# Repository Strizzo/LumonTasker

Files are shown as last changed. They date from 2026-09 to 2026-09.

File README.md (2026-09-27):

# LumonTasker

A working desktop task terminal inspired by *Severance*: a Raspberry Pi 3 Model B,
touchscreen and thermal ticket printer in a custom two-bay enclosure.

The assembled prototype works. The terminal selects tasks from Trello locally,
prints tickets with a monochrome Lumon logo, and records completion or deferral. Its default UI is a simple
blue monospace screen with the Lumon globe, a focus countdown, elapsed-time
progress and a small animated number field. An alternate MDR-style layout is
available by tapping the logo. The separate message-printing integration on the
Pi/mothra remains in service; its deployment source has not yet been imported
into this repository.

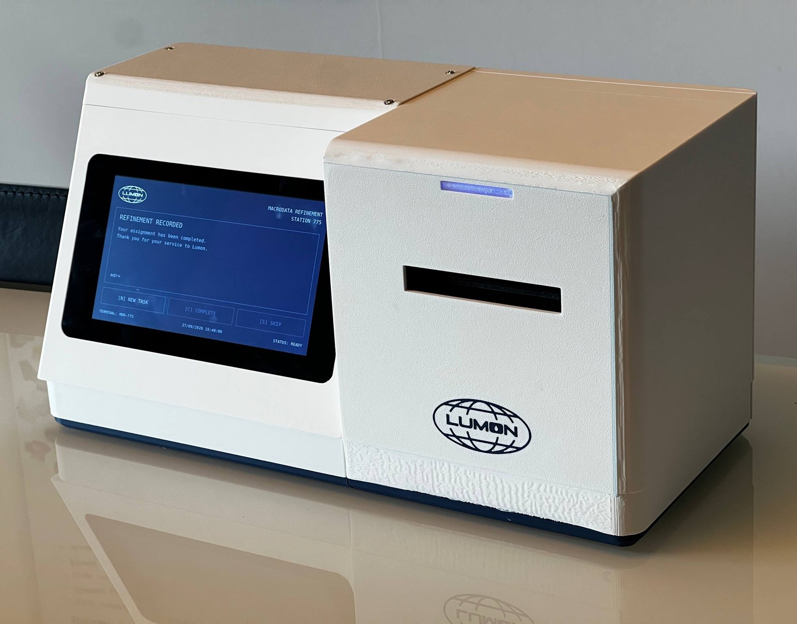
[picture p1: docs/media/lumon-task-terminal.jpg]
The assembled Lumon-inspired task terminal


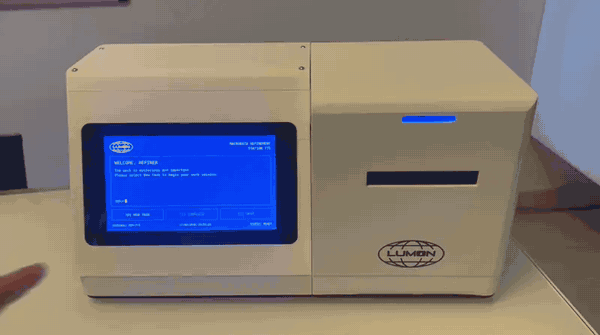
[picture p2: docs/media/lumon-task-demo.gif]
The terminal selecting and printing a task


The demonstration above is the same recording used in the build post, converted
to an animated GIF for GitHub. See also the [two software layouts](software/preview/themes-assignment.png).

## Project contents

| Path | Contents |
| --- | --- |
| [software/](software/README.md) | Pi application, both terminal layouts, assets, isolated checks and deployment records. |
| [cad/](cad/README.md) | Parametric Python CAD sources, hardware measurements, assembly reviews and engineering notes. |
| [cad/output/](cad/output/) | Versioned STEP assemblies, STL meshes, Bambu Studio projects and existing sliced print files. |
| [cad/CURRENT_PRINT_FILES.md](cad/CURRENT_PRINT_FILES.md) | Index of the parts used in the accepted physical build. |
| [files/](files/) | Earlier design sources and exports, preserved as a historical archive. |

## Software setup

Use a Python environment separate from the CAD environment. The dependency
versions in `software/taskticket/requirements.txt` match the working Pi setup.

```sh
cd software/taskticket
python3 -m venv venv
. venv/bin/activate
pip install -r requirements.txt
cp .env.example .env
cp config/settings.example.py config/settings.py
```

Fill in your Trello key, token and board ID in `.env`. The expected board lists
are `TODO`, `DOING`, `DONE` and optionally `Better than nothing`. AI is disabled
by default; ordinary task selection does not require an OpenRouter account.

```sh
python main.py
```

Open `http://localhost:5000/display`. The optional layout is
`http://localhost:5000/display?theme=mdr`. The application expects a configured
USB thermal printer on the Pi; use the isolated preview below to inspect the UI
without hardware or Trello access. Production kiosk startup is described in
[the software notes](software/README.md); historical deployment scripts contain
guards for specific past versions and are not a general installer.

From the project root, with the software environment activated:

```sh
python software/preview/check_backend.py
python software/preview/check_selection.py
python software/preview/check_routes.py
python software/preview/check_printer.py
python software/preview/check_ticket.py
python software/preview/server.py
```

The last command serves a fake-task UI at `http://127.0.0.1:8655/display` and
does not contact the Pi, Trello or a printer.

## Hardware and printing

The current complete assembly is
[LUMON_v51_GLUE_DC_INLET_ASSEMBLY.step](cad/output/v51_dc_inlet_panel/LUMON_v51_GLUE_DC_INLET_ASSEMBLY.step).
STEP files can be imported into Fusion; the editable geometry sources are the
Python generators under `cad/` and `cad/review/`. The working Fusion cloud
documents are not native `.f3d` files in this checkout.

The accepted build combines parts from several revisions. Start with
[the current print-file index](cad/CURRENT_PRINT_FILES.md), not the highest
version number of every historical part. `.3mf` files are Bambu Studio projects;
`.gcode.3mf` files contain already sliced jobs for the original P1S setup.
Check the model, plate, filament mapping and supports in your slicer before
reusing a job on another setup. Current colours are cotton-white PLA, navy-blue
PLA and a separate translucent PETG LED insert.

For CAD development:

```sh
python3 -m venv .venv
.venv/bin/pip install -r cad/requirements.txt
```

Follow the generator and revision notes in `cad/review/`. New revisions still
need the lighter walls, improved roof supports, larger display-glass seat,
closed printer-base underside and removal of the identified unused insert hole.
Those changes are recorded feedback, not changes already applied to the printed
prototype. See [build status](cad/BUILD_STATUS.md) for the full history.

## License

You may build and modify the enclosure for personal, noncommercial use.
Commercial printing or selling copies of the enclosure requires separate
permission. The hardware uses **Open Community License v1.1**, the application
uses **PolyForm Noncommercial 1.0.0**, and original documentation and media use
**CC BY-NC 4.0**. These restrictions mean this is a source-available project,
rather than an unrestricted open-source release.

See [LICENSE](LICENSE) for the scope and full terms, and
[THIRD_PARTY_NOTICES.md](THIRD_PARTY_NOTICES.md) for font licenses and the
*Severance* / Lumon references. This is an independent fan project with no
affiliation or endorsement.

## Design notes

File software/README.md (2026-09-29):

# Lumon terminal software

First deployed on 26 September 2026; MDR-inspired UI deployed on 27 September
local time. The original installation runs on a Raspberry Pi 3 Model B,
managed by `taskiosk.service`. Paths in the historical deployment records refer
to that installation; adapt them to your own Pi when setting up the application.

The physical display is 800 × 480. Its default interface is the simple blue
monospace layout the user preferred, available at
`http://raspberrypi.local:5000/display`. The newer MDR-inspired layout remains
optional at `http://raspberrypi.local:5000/display?theme=mdr`. Tap the Lumon logo
to switch between them. The screenshot from the Pi is
[preview/pi-themes.png](preview/pi-themes.png).

On the idle screen, **Manage** replaces the inactive Complete/Skip buttons.
It opens a 3 × 3 grid of Trello cards, with Previous/Next for additional pages.
DOING and TODO tasks appear directly; **Better Than Nothing** appears as one
group card showing its task count. Tap it to browse its own 3 × 3 grid.
**Back to Main** returns to the parent page, and the group itself never prints.
The logo/station header is hidden in both grids to give the cards more vertical
space and up to three lines for their titles. It returns on the welcome,
task-detail and active-task screens; the connection footer remains visible.
The main grid shows **Total focus** beside the page count: the number of open
DOING/TODO tasks across every page multiplied by the configured focus-session
duration (currently 15 minutes). Better Than Nothing tasks and the group card
are excluded. This is planned focus time, not a prediction of completion time;
the app does not currently store individual task-duration estimates. The total
is hidden inside the nested group, while loading, and on errors.
Tap a card to read its full title, then **Start & Print** to issue that specific
task. Back returns to the same grid page.
Both layouts support the picker; **M** opens it and Escape goes back.
Complete and Skip return when an assignment is active.

The picker includes all open DOING, TODO and Better Than Nothing cards in
Trello's list order, including recently skipped or issued cards. Manual selection
deliberately bypasses the automatic selector's cooldown and weighting, and never
uses AI. Merely browsing or inspecting a card does not print or update history.
The server rechecks open cards before printing, so a card completed or archived
elsewhere cannot silently issue an unrelated task. Tickets record
`selection_method=manual`; completion, assignment restoration and printing use the
existing workflow. [Picker preview with synthetic tasks](preview/manage-classic-grid.png).

Both layouts hide the mouse pointer, including over controls. The kiosk also
runs `unclutter-xfixes` with a one-second idle timeout to hide the native X11
pointer before Chromium receives its first mouse-motion event. Its process is
supervised by the existing kiosk launcher. The active-task screen omits the
fixed focus-session sentence, countdown and percentage bar, including when
restoring an older assignment. A small field of drifting numbers evokes
*Severance* without covering task text or controls. It renders at roughly seven
frames per second while an assignment is active and pauses in a hidden tab or
with reduced motion. The decorative numbers are not task data.

Switching layouts or reloading restores the latest open assignment and original
start time without selecting or printing another ticket. Newly issued tasks
store their display payload in the existing history; older active entries can
be recovered from Trello. Completed, skipped and more-than-12-hour-old entries
are not restored. Repeated-task completion now marks the newest issue, preventing
an old duplicate from causing the just-completed task to reappear.

The default uses one self-hosted DejaVu Sans Mono font. The optional layout is
informed by actual scene excerpts documented in
[references/README.md](references/README.md), using a self-hosted Liberation Sans
approximation; the production's exact typeface is not claimed. Real queue counts
remain available in the status endpoint and footer tooltip. Keyboard shortcuts
are N/C/S; Y/X still work too. The page uses `Cache-Control: no-store` and versioned
assets to avoid stale pages after an update.

## What changed

- The preferred blue terminal interface with the enclosure's Lumon globe,
  large touch buttons, decorative numbers and the newer layout available as an option.
- Real Trello connection status and queue data, refreshed every minute.
  API failures appear as unavailable rather than an empty queue.
- Task selection runs locally by default. It excludes tasks skipped within
  seven days, prefers the least-issued eligible tasks from the last 24 hours,
  then prioritizes DOING and urgent TODO deadlines. Remaining choices mix TODO
  and “Better than nothing,” with more BTN choices on evenings and weekends.
  Ties are randomized. If all eligible cards were issued recently, selection
  continues from the least repeated cards rather than returning false emptiness.
- A selected task gets a 15-minute focus session, not an invented estimate of
  its completion time. Completing a BTN task updates local history while
  leaving the reusable card on Trello; TODO/DOING completion still moves it
  to DONE.
- An optional OpenRouter helper uses Qwen3.7 Flash. Failure, timeout or an
  invalid card ID falls back to local selection, with a ten-minute cooldown
  before trying AI again. Ordinary use currently makes no OpenRouter calls.

## Printed task tickets

Task tickets now use a compact Lumon work-assignment form: globe, department
heading, issue reference, date, task, focus allowance and completion checkboxes.
One monospace family, two weights and thin rules keep it restrained. The
stationery is an original themed design. The old random euro-value line is gone.
See the [actual printer-width preview and layout notes](preview/tickets/README.md).

The entire slip is rendered as a monochrome bitmap, including accented text.
Typical artwork is about 95 mm long, plus the cutter margin; longer titles wrap
and extend the paper. Following physical feedback, the artwork's top padding
was reduced by about 2 mm and its bottom padding increased by about 12 mm to
balance the printer's leading blank space. The revised physical balance awaits
the next ticket; rendering and isolated printer-delivery checks pass.

## Optional settings

Defaults work without changes to the existing Pi configuration:

| Environment variable | Default | Purpose |
| --- | --- | --- |
| `TASKTICKET_USE_AI` | `0` | Set to `1` to try AI before local fallback. |
| `TASKTICKET_AI_MODEL` | `qwen/qwen3.7-flash` | Optional OpenRouter model. |
| `TASKTICKET_FOCUS_MINUTES` | `15` | Focus allowance for tickets and the grid total, bounded to 1–120. |
| `TASKTICKET_TIMEZONE` | `Europe/Luxembourg` | Selection schedule and UI clock. |
| `PRINTER_TASK_LOGO` | `1` | Include the Lumon globe on the work slip; set to `0` to omit it. |
| `PRINTER_WIDTH_DOTS` | `576` | Printable dot width for centring the logo on the POS80. |

Optional AI uses the existing `OPENROUTER_API_KEY` on the Pi. The prompt is
bounded to at most 12 eligible cards and 150 output tokens, without goals,
biography, descriptions or history. Thinking is disabled. An isolated live
test using one invented card succeeded; real Trello cards were not sent during
verification. Model availability and pricing were checked on
[OpenRouter's official model page](https://openrouter.ai/qwen/qwen3.7-flash).

The local source copy intentionally excludes `.env`, `config/settings.py` and
task history. Deployment preserved the Pi's credentials and history.

## Verification

The POS80 also prints graphics. On 27 September, one standalone “LUMON LOGO
TEST” receipt was sent using ESC/POS `GS v 0`; the user confirmed that the globe
was clear and complete. The initial release used a 320 × 164-dot globe above
native printer text. The full work-slip layout now replaces that format.
The test did not select a Trello card or change task history. The separate
message-printing service was not changed.

The current release passed 39 isolated checks on the Pi, including eleven
printer checks and six ticket-layout checks. They cover bitmap polarity, both
USB paths, native-text fallback, one final cut, failure handling, long and accented
titles, print margins and lossless raster-strip reconstruction. A failed write
does not create an issued-task history entry or automatically retry a partial
ticket. The deployed class also captured a synthetic job in a temporary file.

Read-only live checks authenticated to Trello, confirmed the board was open,
and found **11 TODO, 0 DOING and 19 BTN** cards. A dry run using the deployed
selector returned a real eligible task with `selection_method=local`, without
creating an AI client, modifying history or invoking the printer.

Twenty-one Python checks passed: three status checks, nine selection checks and
nine route/history checks. Browser checks passed at 800 × 480, including
55-pixel default touch targets and assignment text without overflow,
pointer hiding in both layouts, preserved sessions when switching, double-tap
protection, animation and reduced-motion behavior, failed-action retry,
completion state and offline status. These tests use
fake tasks and printer dependencies; they do not issue physical tickets. On the
Pi, a one-pixel pointer movement confirmed that Chromium's cursor resource is
fully transparent, and both kiosk and message-printer services remained active.
`scrot -p` manually composites cursor pixels, so it can show an old resource
even while native XFixes cursor hiding is active; the final screenshot was taken
with pointer capture enabled after verifying the transparent resource.

From the project root, with Python 3.9+ and `aiohttp` installed:

```sh
python3 software/preview/check_backend.py
python3 software/preview/check_selection.py
python3 software/preview/check_routes.py
python3 software/preview/check_printer.py
python3 software/preview/check_ticket.py
```

Manual-selection checks are included in `check_selection.py` and
`check_routes.py`. With the preview server and isolated Chrome running as below,
`node software/preview/check_manage.mjs` checks both layouts at 800 × 480:
nested grouping and pagination, parent-page restoration, full-title inspection, cursor hiding, safe text rendering,
double-tap protection, session restoration, empty/offline/stale-card handling,
hidden grid headers, cards at least 75 pixels tall, and returning to automatic selection. Results are in
`preview/manage-ui-check.json`; these checks use synthetic tasks and do not print.

`preview/server.py` provides an isolated UI preview at `127.0.0.1:8655`.
`preview/check_ui.mjs` exercises that preview through an isolated Chrome
debugging port at `127.0.0.1:9226`; it requires Node with built-in WebSocket
support. The current result is saved in `preview/compact-ui-check.json`, including
removal of the fixed focus display, restoration of older assignments, and
animation checks. `preview/themes-ui-check.json` records the earlier timer
release. `preview/mdr-ui-check.json` records
the earlier optional layout release. `preview/simple-ui-check.json` and
`preview/ui-check.json` record the previous designs' checks.

Both `taskiosk.service` and `thermal-printer-subscriber.service` were active
after deployment. The MQTT subscriber's PID stayed unchanged. The teleprint
container and broker on mothra were inspected without changes or test messages.
Physical ticket printing, card completion and Telegram delivery were not
triggered during the earlier UI/backend checks. The subsequent logo and
work-slip proofs are described above. Tap **New Task** on the terminal to
exercise the physical task workflow when wanted.

## Deployment and recovery

The ticket margin adjustment is recorded in `release/ticket-margins-deployment.json`.
Restore `printer/ticket.py` from its recorded backup and restart
`taskiosk.service` to undo it. Deployment captures a synthetic job in a temporary
file and does not issue a physical ticket or change task history.

The simplified task screen and larger task cards are recorded in
`release/compact-grid-deployment.json`. Restore its four `changed_files` from
the recorded backup and restart `taskiosk.service` to undo this UI update.

The grid's total-focus display is recorded in `release/task-total-deployment.json`.
Restore its five `changed_files` from the recorded backup and restart
`taskiosk.service` to undo that display and its duration metadata.

The nested Better Than Nothing group is recorded in
`release/grouped-tasks-deployment.json`. It updates only the shared script and
both templates. Restore its three `changed_files` from the recorded backup and
restart `taskiosk.service` to return to the previous flat picker.

The manual-picker release is recorded in `release/manage-deployment.json`.
To undo it, stop `taskiosk.service`, restore the six `changed_files` from the
recorded backup, then start the service. Credentials, task history and the
separate message-printer service are not part of this update.

The work-slip release is recorded in `release/work-slip-deployment.json`.
To restore the preceding logo-plus-text layout, stop `taskiosk.service`, restore
`printer/thermal_printer.py`, `printer/logo.py` and `core/task_manager.py` from
that backup, then start the kiosk. The unused renderer and bold font can remain.

The ticket-logo release is recorded in `release/ticket-logo-deployment.json`.
To undo it, stop `taskiosk.service`, restore its backed-up
`printer/thermal_printer.py` and `core/task_manager.py`, then start the service.
The unused logo module and PNG can remain. Setting `PRINTER_TASK_LOGO=0` and
restarting the kiosk disables the logo without rolling back the release.

Deployment records are saved in `release/ui-deployment.json` and
`release/selection-deployment.json`; the latest design update is recorded in
`release/themes-deployment.json` (previously `release/mdr-deployment.json`).
Backups on the Pi:

- Initial UI backup:
  `/home/srizzo/taskticket/backups/lumon-ui-20260926T214204Z`
- Selection release backup:
  `/home/srizzo/taskticket/backups/local-selection-20260926T215539Z`
- Simplified UI backup:
  `/home/srizzo/taskticket/backups/vintage-ui-20260926T221632Z`
- MDR-style UI backup:
  `/home/srizzo/taskticket/backups/mdr-ui-20260926T222627Z`
- Two-layout, pointer and animation update backup:
  `/home/srizzo/taskticket/backups/themes-ui-20260926T224648Z`

To undo the latest layout/timer update, restore the files listed in
`themes-deployment.json` from its backup, then restart `taskiosk.service`.
The new optional-layout files can remain unused; the restored template and
script will not reference them.

To undo the MDR visual update, restore its three backed-up files
(`templates/terminal.html`, `static/terminal.css`, `static/terminal.js`), then
restart `taskiosk.service`. The task selector and Trello backend are unchanged
by this visual release.

To undo only the visual simplification, restore its backed-up `main.py`,
`templates/terminal.html`, `static/terminal.css` and `static/terminal.js`, then
restart `taskiosk.service`. This keeps the working local task selector.

To undo the selection release, stop `taskiosk.service`, restore the files
listed in `selection-deployment.json` from its backup to the same relative
paths in the application, then start the service. That restores the initial
Lumon UI with the previous selector. To return fully to the original UI too,
also restore `main.py` from the initial UI backup before starting the service.
Do not restore history or credentials, and do not restart the separate MQTT
subscriber for a UI rollback. The native cursor startup change is backed up
separately; see `release/kiosk-cursor-deployment.json` for the launcher path
and backup. Restore that launcher and restart `taskiosk.service` to undo it.
The small `unclutter-xfixes` package can remain installed and unused.

The deployment scripts guard the specific inspected source hashes; they are
records of this release rather than scripts to rerun unchanged over later edits.

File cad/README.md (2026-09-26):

# Lumon enclosure: engineering review

**Current build:** the assembled prototype was accepted on 26 September 2026.
See [CURRENT_PRINT_FILES.md](CURRENT_PRINT_FILES.md) for the parts used and
[BUILD_STATUS.md](BUILD_STATUS.md) for the physical build record. The sections
below describe the original V19 review and are historical where later revisions
supersede them. Do not treat modelled parts as printed or assembled.

The real printer, screen assembly, Pi/cooler and cable paths determine the
mechanical design. The generated reference picture is a style reference only.
Neither the old picture nor the inherited component boxes establish fit.

## Working files

- `lumon_v19.py`: portable parametric working copy of the archived v18 generator.
- `export_review.py`: colored STEP, assembly-position STLs, individually oriented
  STLs, small fit coupons, previews and independent geometry checks.
- `review/logo_v18.step`: exact logo recovered from the supplied v18 STEP recess;
  six disconnected artwork regions, deliberately preserved.
- `review/audit_v18.py`: baseline STEP/mesh audit.
- `review/prepare_v19.py`: one-time migration recipe, not the normal build command.
- `output/v19/`: generated review artifacts. **Not a print release.**

Run from the project root:

```sh
.venv/bin/python cad/export_review.py
```

Python dependencies are recorded in `requirements.txt`. Original files in
`files/` remain unchanged. Fusion imports are review copies; edits made there
must be intentionally carried back to the generator before another rebuild.

## Color and assembly intent

| Group | Color | Print/assembly decision |
| --- | --- | --- |
| Left shell | Pale grey | Floor, walls, display ribs, insert lands, partition and Pi mounts form one structural print. Supports required at some internal features and the screen-opening roof. |
| Right shell | Pale grey | Floor, walls, spine and printer support rails form one print. Rails remain provisional until the printer is measured. |
| Left top cover | Pale grey | Separate for access to display fasteners, seam screws and electronics. Four screws. |
| Printer trim | Dark charcoal | Separate, open aperture around the provisional printer envelope. Two rear screws and locating skirt. The real printer supplies its lid, paper exit and controls. |
| Screen bezel | Dark charcoal | Separate flat print; perimeter fit clearance added. A thin adhesive attachment is still to be specified; no snap attachment is claimed. |
| Base plates, left/right | Dark charcoal | Separate prints, four screws each. Preserve independent color and screw access. Left plate has through vents and underside channels. |
| Display retainer | Pale grey/internal | Separate flat print; installs after the screen and clamps it at four points. |
| Rear service panels | Pale grey | Separate flat prints, four screws each with external pan heads. |
| Logo | Blue | Optional multi-material region registered to the right shell. Six loose regions are not a sensible first manual assembly. Paint/decal is the simpler single-extruder alternative. |
| Hardware reference bodies | Visualization only | Never print these as enclosure parts. Their shapes are unverified bounding boxes. |

Do not merge lids, retainer or service panels into the shells: doing so traps
hardware or prevents servicing. Keep the two main modules independently
printable and join them at the existing spine. There is no need to introduce
more large external seams until the actual build plate is known.

## Print orientation and remaining checks

`assembly_stl/` retains registration for fit and multi-material inspection.
`oriented_stl/` places each individual part on Z=0; these coordinates no longer
assemble together. Do not mix the two sets in a multi-material object.

- Shells: floor down, open top up. Inspect supports below the screen opening,
  rear-opening roofs and sideways bosses. The old blanket “no supports” claim
  is withdrawn. Supports must be removable before fitting electronics.
- Bezel and retainer: un-tilted and laid flat, rather than printed at their
  14-degree assembly rake.
- Rear panels: exterior face down; locating step faces up.
- Covers/trim: exterior top down to avoid supporting a whole internal ceiling;
  inspect the rounded perimeter for support and bed-contact requirements.
- Base plates: bottom down. Check channels, counterbores and first-layer grip.

The first fit-test plate is configured in `output/p1s_fit_plate/LUMON_v19_fit_test.3mf`
for a Bambu P1S, 0.4mm standard nozzle and textured PEI plate: 0.20mm layers,
3 walls, 20% infill, 3mm outer brim, and automatic build-plate support for the
screen corner. Studio estimates 1h24m and 27.07g including purging.
Physical AMS A1 supplies dark Bambu PLA Matte; A2 supplies light-grey Generic
PLA, as explicitly confirmed by the user. A2 was registered as Generic PLA
in the device settings. The full enclosure has not yet been sliced or released.

General support/split/tolerance rationale follows Prusa's manufacturer guide:
https://help.prusa3d.com/article/modeling-with-3d-printing-in-mind_164135
A mesh that is watertight can still have unprintable bridges or unusable holes.

## Hardware information needed for a fit release

- Printer exact model; body width/depth/height; rubber feet; lid hinge/swing;
  paper path/cutter; buttons and release lever; cable exits and plug clearances.
- Display exact model and complete assembly dimensions, including driver board,
  mounting frame, connectors and cable bend space. Confirm active image area
  before accepting the 6mm edge overlap inherited from v18.
- Raspberry Pi model, cooler and connector/cable directions.
- Actual power supply and voltage architecture. The inherited internal supply,
  inlet and barrier are packaging placeholders, not an electrical design approval.
- Printing setup confirmed: P1S with AMS, standard 0.4mm nozzle and two PLA colors.

The first physical step should be small fit coupons, followed by a printer-bay
fit test after measurement. A full pair of shells should wait for these checks.

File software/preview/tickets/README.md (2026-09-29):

# Lumon work slips

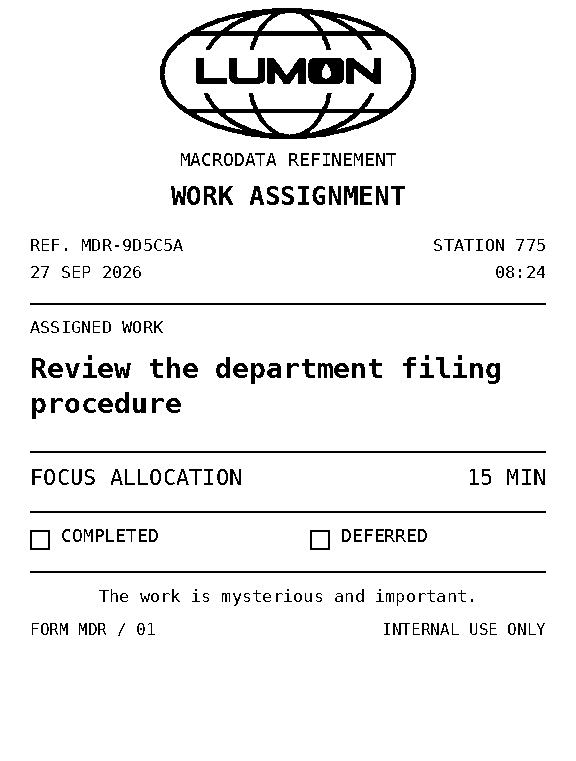
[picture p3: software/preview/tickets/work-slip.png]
Work assignment


Original *Severance*-inspired internal stationery, designed for the accepted
POS80 printer. This is not claimed to reproduce a screen-used paper prop.
The reference images contain synthetic tasks; no real Trello titles are stored.

The layout uses the existing Lumon globe, one DejaVu Sans Mono family in two
weights, thin rules and a clear assignment section. Station 775 matches the
terminal. A stable short reference is derived from the task ID; the issue date
and time use the configured timezone. The time field says **Focus allocation**
for the current selector and **Time estimate** for older estimated tickets.
Optional challenge times and older task-specific guidance remain available.
The paper checkboxes can be marked by hand; they do not change software state.
The random euro-value line and duplicate focus-session sentence are removed.

Rendering happens at the actual 576-dot printable width, with 30-dot side
margins. Normal task text is 28 dots high; supporting fields are 16–22 dots.
At 203 dpi, the illustrated two-line assignment uses roughly 95 mm of artwork
plus the printer's cutter margin. Long titles grow the slip rather than being
clipped or abbreviated. Accented text is rendered directly, avoiding the
printer firmware's inconsistent handling of UTF-8.

The revised artwork starts 8 dots (about 1 mm) below its top, reduced from 24.
Its bottom padding is 96 dots (about 12 mm) larger. This adds approximately
10 mm to each slip overall. The uneven bitmap margins compensate for the
leading blank paper visible on the physical printer; the PNG does not include
that mechanical margin. The current
[ESC/POS feed-and-cut command](https://download4.epson.biz/sec_pubs/pos/reference_en/escpos/gs_cv.html)
feeds to the cutter without reverse feeding. The next physical ticket should
confirm the balance; the POS80's exact head-to-cutter distance is not measured.

The same 1-bit pixels are used for the preview and USB job. They are sent as
contiguous 128-row raster strips with no intervening newlines, then one final
cut. Each strip is about 9 KB at 576 dots. This follows the beginning-of-line
and paper-feed behavior in the
[Epson ESC/POS raster reference](https://download4.epson.biz/sec_pubs/pos/reference_en/escpos/gs_lv_0.html)
and uses the command already confirmed on this POS80. The protocol is not
assumed to work on every other printer model. Missing assets fall back to a
readable native-text work slip before any USB write is attempted; failure after
writing starts never triggers a second fallback ticket.

To regenerate these previews without contacting hardware or Trello:

```sh
python software/preview/render_tickets.py
```

Also inspect [long-title.png](long-title.png) and
[accented-title.png](accented-title.png). The standalone physical sample has a
small **LAYOUT PROOF / NO TASK ISSUED** footer; normal task tickets omit it.

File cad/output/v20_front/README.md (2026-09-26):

> SUPERSEDED: user rejected the detachable front. Use ../v20_integral_front/ for the current mechanical study.

# Front-output v20 mechanical study

This is a new printer-module study, not the completed styled enclosure or a released print job. Do not print the old v19 printer housing: its hardware dimensions are obsolete.

Confirmed inputs:
- User measured desktop body: 131 W × 175 D × 120 H mm.
- User successfully tested feed/cut with the native output face forward.
- Rotated body envelope: 131 W × 120 D × 175 H mm.
- Seam, bezel and insert coupons passed; retain 4.2mm insert bores.

The prototype keeps the existing 158mm right-module width and spine screw positions. It has a 201mm overall design height, 20mm taller than v19, so the complete enclosure silhouette is not yet resolved. The STEP uses local right-module coordinates; translate X by 218.96mm to inspect against the v19 left module. The printer reference is a rectangular measured envelope, not a model of its native face, lid or connectors.

Six separate solids: grey shell, cradle tray, tray stop, top cover, rear cover; dark front surround. The shell floor and walls are united. Tray, stop and covers remain removable. The full native face is exposed by the surround so a guessed small paper slot does not constrain the lid. The rear cable opening is open to the panel bottom. The mounting bracket using the printer's two native keyholes is not yet modeled: its hole spacing and offset have been requested. Without that bracket, the printer is not positively retained and this design is not ready to use.

All six solids are valid and watertight; pairwise intersections and intersections with the measured printer box have no volume overlap above 0.05mm³. This checks nominal geometry only. It does not verify real case curvature, lid sweep, buttons, cable bending, retention or sliced supports. Single-part STL orientations are normalized to the bed. Separate colors onto separate plates. No new job has been sent to the P1S.

Assembly and exploded PNGs visualize the mechanical layout only. The blank grey rectangle in the assembly image represents the purchased printer envelope. Cosmetic radii, logo placement, shared silhouette with the display module, and printer mounting bracket remain to be resolved before releasing a full print.

Rebuild: `.venv/bin/python cad/front_output_v20.py`.

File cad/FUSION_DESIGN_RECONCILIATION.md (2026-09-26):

# Fusion design reconciliation — 21 September 2026

## Evidence and current state

Inspected the two open Fusion documents visually: LUMON_TERMINAL_v18 and LUMON_v19_colored_review (both unsaved review imports). Compared their source/export notes and the exported v19 STEP against the v28 printer bay currently printing. Neither open Fusion document is the current full device; do not use its printer cavity or old print parts as a release reference.

V19 explicitly assigns dark #10161E to printer_trim, display_bezel and both feet; the body and left cover are pale #DEE9EE and the logo blue #0B4F7E. This is deliberate styling, not merely Fusion component colouring. The dark printer part is an OPEN rim around the old top-exit printer, not a solid lid for the new orientation. build_lid specifies a12mm upper fillet and a hollow locating skirt. V28 has a closed, integrated pale top, a6mm front-right corner in plan, and no equivalent rounded upper transition. Earlier explanations that the separate right top was necessary for printability were wrong.

## What must be reconciled

| Area | Finding | Next action |
| --- | --- | --- |
| Printer crown | Dark rounded rim lost when old top-exit architecture was replaced. Old part is158mm wide; current bay175mm. | Design a NEW separately printed navy cosmetic cap for the existing flat top. Do not reuse old rim/cover. Keep rear removal and LED clear. |
| Upper rounding | Thin cap can soften its own edges but cannot recreate the original12mm fillet around a square shell without added height or overhang. | Show cap section/proportions before selecting radius; do not promise identical old silhouette. Prefer modest softening for this prototype. |
| Relative heights | Old full left module reaches181mm; right bay now reaches201mm before any cap. | Treat the20mm step deliberately in whole-device review. A cap increases it. Do not blindly raise display geometry or assume a flush common top. |
| Printer base | Old right foot is sized for158mm bay and has obsolete mounting points. V28 has no matching four foot-insert bosses and its shell starts atZ9. | Design matching dark right plinth and its retention for the printed shell; preserve rocker swept channel and cable opening. Align ground plane with left foot. Do not print old foot_right. |
| Base styling | Old light lower stepped band is absent from new right shell. | Decide with cap/plinth proportions whether to echo it cosmetically; a foot alone will not recreate the old inset light band. |
| Main joint | V28 retains five seam screw locations and two alignment-dowel locations from v19. | Join through left bay before electronics obstruct access; confirm fastener lengths and real tool access. Pairwise STEP audit checks cross-module collisions, not assembly access. |
| Printer support | V26 physically mostly fits; V27/V28 carry approved8.1mm bottom rise and0.6mm narrower total guide gap. | Print refined cradle as final assembly part, not another trial. It is separate from shell by design. |
| Printer retention/service | Whole printer rear-loads; two bars and rear cover are removed for paper service. | Print bars and rear cover. Verify real plug bends, switch clearance and extraction after installation. No top opening needed. |
| LED | Separate insert trial accepted; translucent PETG available. | Print PETG insert separately after profile/slot known; flange attachment without pressing native controls. Confirm visibility behind installed front. |
| Screen bezel/corner | V19 corrected prior lower-left corner geometry; bezel coupon passed previously. | Retain correction and separate dark bezel; specify adhesive only on locating lands, after actual screen fit. Do not restore v18 corner. |
| Display retention | Source assumes192.96x110.76mm original Pi7-inch display,21mm assembly depth TBD and6mm bezel overlap. | Confirm exact actual display, active-area boundaries, PCB thickness, connector and ribbon clearance before printing left tub/retainer. Source MEASURED comments are not new verification. |
| Pi/cooler | Inherited85x56mm PCB and58x49 mounting pattern;22mm assembled height TBD. | Confirm actual Pi and cooler, port direction and cable access; update mounts/envelope. |
| Power packaging | Old left tub hardcodes LRS-100-24-size supply, IEC inlet, divider and a speculative buck envelope. | Confirm actual chosen power hardware before carrying those pockets/cutouts into the next left module. No electrical implementation inferred from CAD placeholders. |
| Cooling | V19 left foot has through slots and rear-opening underside channels. | Keep intake path open; review exhaust and cooler clearance with actual hardware, then evaluate temperatures in assembled prototype. |
| Colours and print split | Current A2 light grey/A1 navy differ from exact historical render swatches. | Keep bezel/cap/plinth navy as separate jobs; pale structural parts separately; six shell colour changes only for logo. PETG insert separate. |
| Fastener schedule | Old31-insert count included obsolete right foot/top details. | Recount after plinth and left bay are final. Tested4.2mm insert bores remain; no two top-cover screws in V28. |

## Execution order

1. Allow current integrated-top shell print to continue. Review does not require cancellation.
2. Design and render the new rounded dark cap and matching right plinth around the ACTUAL v28 shell; these are not yet print-ready parts. Preserve LED and rear service clearances.
3. Prepare final refined cradle, retaining bars, rear cover and PETG diffuser. Verify Bambu settings natively: previous imports did not honor every programmatic setting. Slice each and request print launch as instructed.
4. Confirm display/Pi/cooler/power hardware (question sent to user), then finalize left bay, bezel, retainer, left cover, rear panel and feet together.
5. Recheck seam assembly, wiring, supports and whole-device appearance before releasing left structural print.

The current combined review is output/v28_integrated_top/whole_enclosure_review.step and PNG, generated from retained v19 left parts plus v28 right parts. It is a REVIEW with unverified left hardware, not a complete print release. Cross-module interference audit is context_audit.json. Existing Fusion tabs remain untouched as reference.

## Fusion synchronized — 21 September

Imported the coloured whole_enclosure_review.step into a new Fusion document and saved in the existing lumon project as LUMON_v28_CURRENT_ASSEMBLY_REVIEW. Verified current integrated-top right shell and dark left bezel/foot visible. Original v18/v19 tabs preserved. The new cap/right plinth are still unmodelled, not silently represented by obsolete parts. Left hardware remains unverified.

Standing workflow: refresh the complete coloured assembly in Fusion BEFORE asking for future print approval. Match reviewed right-shell geometry to the actual release revision, retain clear part names and label unverified/concept parts. Keep source generators and review STEP reproducible; save an explicitly versioned Fusion review and visually verify it. Do not use stale Fusion tabs to describe the currently printing design.

## V29 — rear service hatch / ventilation correction (2026-09-21)

The v19 electronics hatch overlapped the lower four rear exhaust slots.
V29 reduces its opening from 112 × 94 to 112 × 74 mm and the cover from
132 × 114 to 132 × 94 mm. Lower datum is retained; upper screw centres move
from z132 to z112. The rear wall and rebate change together, leaving 6 mm
between the cover top and the first exhaust slot. All five vents pass solid
intersection checks, the two changed meshes are watertight, and assembly
pair checks report no interference. This verifies geometry, not cooling performance.

Source: `cad/lumon_v29.py`; regenerate with `.venv/bin/python cad/review/build_v29_review.py`.
Only `tub_left` and `rear_panel_left` are replaced in the exact v28 combined STEP.
The actively printing v28 printer shell is unaffected. Left-side hardware
measurements and print release remain pending.

Complete coloured assembly: `cad/output/v29_rear_vent_fix/whole_enclosure_review.step`.
Saved and opened in Fusion, project `lumon`, as `LUMON_v29_REAR_VENT_REVIEW`.
Audit and rear view are in the same output directory. No new print dispatched.

## V30 — matching printer plinth added (2026-09-21)

Supersedes the printer-base omission above. `cad/review/build_v30_plinth.py`
adds a new navy bonded foot around the exact v28 printed shell, retaining
all v29 geometry. The foot is 9 mm high with 2.5 mm inset and 5 mm lower
bevel matching the left foot. Ground planes agree. Open cutouts preserve
the rocker, rear cables and inter-bay cable route. Five 0.3 mm recessed
adhesive beds retain the foot; unrecessed top lands carry compression.
This avoids new holes in the already printing shell. Physical fit and
bonding remain untested; do not present it as a screw-mounted base.

Valid single-solid watertight mesh, all adhesive beds backed by shell floor,
zero base/assembly intersections and clear relief volumes verified.
Files and assembly notes: `cad/output/v30_printer_plinth/`.
Opened and saved in Fusion project `lumon` as `LUMON_v30_MATCHING_BASE_REVIEW`.
Separate navy print only; not sliced or dispatched. Dark rounded top cap
remains outstanding. No other geometry was changed.

## V31 — prototype complete, cradle retention and next physical checks (2026-09-22)

The v28 shell is now printed (grey/yellow substitution), explicitly a test shell.
The user has only the earlier v26 cradle. V31 retains the exact v28 shell and
approved refined cradle, and adds two tray-capturing legs/lips to the lower rear
bar using its existing screws. Rear/upward nominal play is 0.5 mm. Geometry,
clearance and tray-motion checks pass; physical fit remains pending. The kit
has now been sliced and verified in Bambu Studio: 3 h 6 m 28 s, 108.54 g PLA,
212 layers, one colour. Use `02_cradle_and_bars_reviewed.3mf` and its matching
G-code export. Launch approval, clear bed and current PLA slot remain pending.
See `output/v31_cradle_retention/README.md` for the fitting sequence and prepared
single-colour kit. Imported into Fusion and saved in the existing `lumon`
project as `LUMON_v31_CRADLE_RETENTION_REVIEW`; the complete assembly was
visually checked. A 10-editable-document-limit notification appeared after
saving, but the named v31 document is present without an unsaved marker. No
older document was deleted or changed to read-only during this update.

The user wants the final enclosure less box-like. Keep rear service and a rigid
front/top, but revisit the final structural shoulder rounding and coordinated
navy crown/outlet surround/base using the full assembly. The grey/yellow shell
does not constrain the final styling. Do not start another large shell or final
colour print before hardware fit and actual-CAD appearance review.

## V32 — equal-height study (2026-09-22)

The user explicitly confirmed equal overall heights, tops aligned. This
supersedes the earlier relative-height direction: the left bay grows from
181 to 201 mm, matching the printer bay, with both bases on z=0. The display,
bezel, supports and retainer move up 10 mm to remain centred on the taller
face. Front lid fasteners follow the taller sloped wall and rear vents move
up 20 mm, leaving 26 mm above the service hatch. Bay joining holes retain
their coordinates. All printer-side parts are exact V31 solids, preserving
compatibility with the printed shell and prepared cradle kit.

Changed solids and meshes pass validity/watertightness checks. Complete
assembly intersection checks find no clashes; joining bores, lid fastener
passages and rear vents are unobstructed. Actual left-side hardware remains
unverified, so this is a proportions study, not a left-bay print release.
Coordinated crown rounding and navy trim are still outstanding and must
preserve the common finished height.

Source: `cad/review/build_v32_equal_height.py`. Complete STEP, audit, and
before/after actual-CAD previews: `cad/output/v32_equal_height/`.
The V32 STEP is imported and visible in Fusion as `whole_enclosure_review*`.
Cloud save is blocked by the personal-use 10-editable-document limit;
repeated CUA coordinate actions on the older V28 Editable control failed
with `windowNotFoundAtPosition`, including after resetting the tool session.
No older document was deleted or made read-only. Local STEP and previews are
saved. The design browser was restored. No print was dispatched.

V32 save blocker resolved: the user confirms on 22 September that they made
older Fusion versions read-only and saved the latest equal-height review.

## V33 — cohesive exterior study (2026-09-22)

User explicitly requested matching lower profiles and top-front rounding, with
one continuous shape split for printing rather than two visibly independent
bays. V33 uses a common upright outer envelope with a recessed 14-degree
display. The band has one height and setback across the face; both bays share
a 12 mm front roof radius. The left front brow is now integral, with the
removable lid joint on the roof behind it. The screen and printer datums,
cradle/bars, bay joining axes and service access remain unchanged.

This is a form option, not a final print release. Its four changed solids and
meshes pass checks, all assembly/hardware-envelope and rear-extraction checks
are clear, and vents/joining bores/lid bores are unobstructed. Actual left
hardware and slicer validation remain pending. An assembled seam remains;
do not promise an invisible joint without finishing.

Complete CAD and notes: `cad/output/v33_unified_body/`. Source generator:
`cad/review/build_v33_unified_body.py`. Imported, visually verified and saved
in Fusion project `lumon` as `LUMON_v33_UNIFIED_BODY_STUDY`, without an unsaved
marker. Older V32 saved by the user is preserved. No print dispatched.

## V34 — correction: preserve the sloped display surround (2026-09-22)

The user rejected V33's upright facade and deep screen recess. The original
sloped plane around the display is required. V34 restores the exact V32 face,
bezel and screen position, retaining the common base profile. The display
cover is rebuilt with no fillet along the joining edge: both roof surfaces
meet flat at z201. Exposed front edges have matching 12 mm radii tangent to
their respective faces. The existing front setback from the display rake
remains; no canopy fills it. Roof joint coverage and all assembly, reference,
extraction, vent and bore checks pass. Left hardware and slicing remain pending.

Saved and visually checked in Fusion `lumon` as
`LUMON_v34_SLOPED_CONNECTED_ROOF`. V33 remains only as a rejected alternative.
Files: `cad/output/v34_sloped_connected_roof/`. No print dispatched.

## V35 — desktop-terminal angle (2026-09-22)

User liked the desktop-terminal direction after discussing 20 vs 25 degrees.
V35 models 25 degrees for the entire sloped display face and screen assembly,
retaining the connected roofs and common base. The printer side is exact V34.
Front lid lands/screws move rearward with the panel. A small retainer relief
clears the existing power divider without cutting it. Five screw lands remain
fully supported; use only the rear alignment dowel because the old front pin
now lies ahead of the left wall. All assembly, reference-envelope, extraction,
vent and bore checks pass. Actual electronics remain unverified, with a tight
1.29 mm retainer-to-buck placeholder clearance. No print released/dispatched.

Saved and visually checked in Fusion `lumon` as
`LUMON_v35_DESKTOP_TERMINAL_25DEG`. V34 remains for 14-degree comparison.
Source: `cad/review/build_v35_desktop_terminal.py`.
Files and assembly notes: `cad/output/v35_desktop_terminal/`.

## V39 rear alignment —22 September2026

Full assembly saved in Fusion as LUMON_v39_ALIGNED_REAR at19:38 and verified.
Display-side rear wall/hatch/roof/base extend9.75mm to the printer cap datum.
Front throughY135,25-degree display,Pi/PSU and all printer-side parts unchanged.
Rear corners and base radii matched; CAD/mesh/clearance checks pass.
Seven Bambu bay plates prepared, no dispatch; see output/v39_aligned_rear.

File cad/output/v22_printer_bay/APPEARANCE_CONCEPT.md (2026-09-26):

# Finished appearance concept

Generated with built-in image_gen on 20 September 2026 from whole_enclosure_study.png. Output: finished_appearance_concept.png.

Suggested palette: Polymaker Panchroma Matte PLA, 1.75mm, Cotton White shell and Army Blue bezel/base/logo. This is a Lumon-inspired aesthetic choice, not an official colour match. Current manufacturer swatches approximately #F4EFEB and #2E4462; physical filament and lighting differ. Amazon Italy stock/prices not verified.

The generated render follows CAD proportions but is NOT an exact CAD rendering. LCD graphics, receipt text, printer buttons/status light and some edge/base details are illustrative. Actual printer front is retained, not replaced with this generated control panel. Right feet/base and final cosmetic integration remain to be modeled. Screen/UI design is not changed by this illustration.

User explicitly paused print dispatch; preparation may continue.

Prompt brief: Transform the actual CAD front-right preview into a photorealistic finished-product concept, preserve the sloped left screen module, 20mm taller right front-output printer bay, integral front, existing broad printer opening and logo placement. Matte warm Cotton White shell, Army Blue bezel/base/inlaid logo, fine printed texture, fitted LCD with retro teal task list, exposed black intact printer face with paper and controls, neutral studio desk and soft daylight. No top-output paper, front screws, keyboard or extra knobs. Hardware details illustrative; not an engineering drawing.

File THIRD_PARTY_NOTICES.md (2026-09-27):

# Third-party notices

The project-wide terms in [LICENSE](LICENSE) apply to the author's original
contributions. They do not replace the licenses or rights below.

| Material | License or rights notice |
| --- | --- |
| Courier Prime font files | SIL Open Font License 1.1; see [OFL.txt](software/taskticket/static/fonts/OFL.txt). |
| DejaVu Sans Mono font files | Bitstream Vera font license and DejaVu public-domain changes; see [DejaVu-LICENSE.txt](software/taskticket/static/fonts/DejaVu-LICENSE.txt). |
| Liberation Sans font files | SIL Open Font License 1.1; see [Liberation-LICENSE.txt](software/taskticket/static/fonts/Liberation-LICENSE.txt). |
| Python and CAD dependencies | Installed separately; retain their respective upstream licenses. See [software requirements](software/taskticket/requirements.txt) and [CAD requirements](cad/requirements.txt). |

*Severance*, Lumon and the Lumon globe logo are third-party references used in
this independent fan project. Their names, artwork and trademarks belong to
their respective rightsholders. The software and enclosure licenses do not
grant permission to exploit those third-party rights. No affiliation,
endorsement or official merchandise status is claimed.

The interface and task-slip layouts are original themed designs; they are not
claimed to be production artwork from the series. Scene-reference source links
are documented in [software/references/README.md](software/references/README.md).

The photographs and animated demonstration in `docs/media/` were provided by
the project author. The GIF is a format conversion of the author's original
recording. The media license covers the author's contributions, with the
third-party elements described above excluded.

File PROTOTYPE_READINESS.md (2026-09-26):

# First enclosure prototype — exploration, 20 September 2026

> Follow-up: the working v19 engineering review and revised geometry are in
> `cad/REVIEW_FINDINGS.md` and `cad/output/v19/`. The notes below describe the
> original archive before that review, not the current working candidate.

## Starting point

This workspace is an archive of parametric CAD, STEP assemblies, STL exports,
renders, and reference photographs. No application/firmware project or Git
repository was found at the workspace root. CAD generators use build123d/OCCT.

Use `files/mnt/user-data/outputs/lumon_terminal_v18/` as a **candidate baseline
for review**, alongside `files/lumon_v18.py` and `files/LUMON_TERMINAL_v18.step`.
It includes the raked display module, printer cover with paper slot, separate
feet, rear panels, and display bezel. Its report gives an assembled envelope
of 376.96 × 161 × 181 mm. This is not a print-approved release.

Do not combine the loose STLs in `files/` into an assembly: they include older
geometry. For example, the loose left tub is 227.46 × 160 × 151.97 mm while
the archived v18 left tub is 218.96 × 161 × 156 mm. The loose top plate is
3 mm tall; the v18 cover is 21 mm tall. Selected loose STL/report hashes do
not match their archived counterparts. Names such as v51/v52/v53 should not
alone establish chronological order; source headers and timestamps are unreliable.

## Measured STL bounds for the v18 candidate

Dimensions below were read directly from binary STL vertices, in the model's
millimetre convention. These are assembly-axis bounds, not chosen print orientations.

| Part | X × Y × Z (mm) |
| --- | --- |
| tub_left | 218.96 × 161.00 × 156.00 |
| tub_right | 158.00 × 161.00 × 156.00 |
| top_plate_left | 218.96 × 128.09 × 21.00 |
| printer_lid | 158.00 × 161.00 × 21.00 |
| display_retainer | 194.36 × 36.85 × 133.18 |
| display_bezel | 212.96 × 34.06 × 125.66 |
| rear_panel_left | 140.00 × 3.00 × 114.00 |
| rear_panel_right | 110.00 × 3.00 × 90.00 |
| foot_left | 216.46 × 156.00 × 9.00 |
| foot_right | 155.50 × 156.00 × 9.00 |

`ref_*.stl` represents purchased hardware, not enclosure parts to print.
STLs retain assembly offsets: e.g. tub bottoms are at Z=9 and the printer
cover starts at Z=160. Each part needs deliberate orientation and placement
on the slicer's bed. Bounding-box fit alone does not account for brims or supports.

## Issues to resolve before full-size case prints

1. The archived v18 validation report flags a **1.7 mm rear-left wall FAIL**.
   Reproduce and inspect this before releasing the left tub.
2. Printer dimensions remain explicitly UNVERIFIED: 142 × 122 × 122 mm.
   Confirm the actual unit, connectors, lid opening sweep, controls, and paper
   exit. `paper_slot_y=45` is still TBD. Display thickness is also TBD at 21 mm.
3. The report contains stale statements: it describes both modules as raked
   and also describes the printer block as upright; it calls the printer well
   open although a cover is exported. Its 21-insert schedule omits separate
   foot fastening and the source now includes lid magnets. Recalculate hardware
   from the chosen geometry rather than shopping from the old report.
4. Existing zero-interference results cover selected pairs only. They do not
   establish cover clearance, paper travel, lid servicing, or full assembly fit.
5. Regeneration needs environment repair: build123d is absent from the default
   Python; source uses `/home/claude/out_v18`, `/home/claude/logo_src.png`, and
   `/mnt/user-data/uploads`. The exact logo source is not present under that
   filename. Export code also retains a v2 STEP filename. Preserve the archive
   and make a portable working copy before regenerating.

## Next prototype sequence

1. Record printer model/build volume/nozzle/material and actual component measurements.
2. Confirm the v18 appearance as the desired baseline and repair/revalidate
   the working CAD, including the thin wall and complete mating-part checks.
3. Generate small fit fragments for the seam joint, display rebate, and printer
   support before committing to full tubs (also proposed in BUILD_PLAN_v2.md).
4. Slice and inspect those fragments using the actual printer profile.
5. After fit checks, print the right tub and trial-fit the receipt printer;
   then release the left tub, covers, bezel, retainers, and feet.

An appearance-only mockup can use provisional component dimensions, but should
be labelled accordingly. A functional fit prototype needs measured hardware.

## Verification performed

Read the existing build plans, v18 source and report, inspected the v18 render,
compared selected loose/archive hashes, and independently measured STL bounds.
No CAD regeneration, mesh-manifold validation, slicing, or physical fit test
has been performed. Original design files have not been modified.

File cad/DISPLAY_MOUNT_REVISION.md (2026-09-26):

# Display mounting revision — actual hardware photos, 23 September 2026

## V49 measured bracket-depth correction — 24 September

V48 completed (Device Finished100%,121/121 and user assembly photo), but the
arms bend while seating the display and the short screws do not reach. User
measures glass FRONT to flat metal mounting face **8.4 mm**, and screws **4 mm
under the head**; heads fit the existing counterbores.

- V49 relieves all four contact pads **2.44 mm**, local y6.96 to y9.40.
- Plastic grip under screw head is **2.0 mm**, reduced from3.9; head-seat y11.40.
  The actual4 mm screws protrude2 mm nominally. Do not substitute M3x6.
- Original XY hole positions, arm roots, pocket193.6x111.4/R8.2 and3 mm ledge
  preserved; contact depth changes only. CAD single-body, watertight, bearing,
  screw passage, unchanged-region and conservative insertion checks pass.
- Return to front-face-down orientation at user request. Two small identical
  upper-right corner coupons compare support gap0.20 vs0.12 mm and test depth/
  screw reach. Full-frame geometry also updated, but no full-frame reprint queued.
- New prints not dispatched; fresh plate-clear confirmation is still needed.
  CAD: output/v49_measured_display_depth. Fusion stays savedV39; not synced.
- Earlier2.5 mm maximum-thread-depth claim is not explicitly verified in the
  manufacturer drawing. Do not force a screw that stops before its head seats.
- Full display case still needs cable/power and full-body print/access review.

**Latest width change, 24 September: V45 uses a 3 mm bearing ledge.** The user
requested the wider seat and confirms the black band stays clear of the outer
3 mm rear glass border. The whole ledge remains 2.3 mm thick; 0.8 mm glass,
1 mm front recess, accepted outer opening, and four integral retention arms
remain unchanged. No band notch is needed. V44's 2 mm width below is history.
The nominal chassis is only 0.35 mm away from the wider seat at its lower edge;
the actual seating and metal mount stack still require the physical trial.
See output/v45_display_seat_3mm. Full-case release and Fusion sync remain pending.

**Latest correction, 24 September: the user's recessed seat is load-bearing.**
The glass must rest on its rear perimeter and be stopped from moving inward
without screws. Four screws through integral case arms into the metal lugs
prevent front withdrawal. V41/V43's deliberate gap under the glass was incorrect
for this request. V44 supersedes that load path; historical proposals below are
retained as history, not current instructions.

V44 provides a 2 mm bearing width and keeps the accepted glass opening and 1 mm
recess. The user now measures mostly 0.8 mm glass, and 1.3 mm at a local black
band (possibly a data connection, not identified). The measured baseline seat
is y1.8; historical 0.7 and 1.1 mm variants remain references. The user confirms
the band does not reach the outermost 2 mm rear bearing border, so no seat relief
is needed. The 2 mm dimension is the inward support width, not soft padding
thickness. Glass_0p8 is the selected seat. An interior envelope conservatively
checks band clearance without inventing its exact location or identity. This
does not release the full case for printing. The seat and four rear metal-lug lands must match
the freely seated assembly simultaneously. Check for printing tolerances/high
spots and correct any rear lug gap with measured rigid shims or revised pads;
never use the screws to pull the glass across that gap. No bedding layer is
assumed; any later bedding thickness must be included in the mounting stack.
The old V40 contour test does not validate this new bearing seat. See
output/v44_bearing_seat/README.md and per-variant audits. Fusion and printing
are unchanged by this revision.

The photos show a Pi already attached to the display controller standoffs, four unused outer mounting lugs on the metal back, a thin glass overhang, an orange flex and a DSI cable. Treat the display and Pi as one serviceable assembly. The loose wires were unplugged accidentally; the user confirms no physical pins/connector were reported broken. Their original pin mapping has not been verified, so do not infer connections from wire colours alone.

## Why the V39 display-side mount must change

The inherited CAD represents the display as a192.96×110.76×21 mm box. Its21 mm depth is explicitly a placeholder. The generic4 mm thick rear retainer sits21 mm behind the inner front panel, with long side ribs. Pi references and mounts are separate on the enclosure wall. Photo evidence makes those representations incomplete for this assembled hardware. Previous placeholder collision checks do not establish clearance for the attached Pi or plugs.

## Selected mounting direction

Keep the25-degree sloping face. The latest user requirement removes the separate navy surround and uses the glass border in an integral white recessed seat. Use the four OUTER threaded lugs in the display's metal chassis, on a lightweight removable carrier or local brackets. The official drawing labels these M3, nominal126.2×65.6 mm pitch. Do not confuse them with the inner M2.5 controller/Pi mounting pattern58×49 mm. Verify the hardware variant and fastener engagement before selecting screw length.

Locate the glass within a shallow opening with clearance. A soft anti-rattle gasket can be added, but mounting screws must seat against properly sized rigid spacers/bearing pads, never pull the glass tightly against a rigid lip. The original corner coupon is useful for contour/clearance comparison only and cannot validate the entire mounting stack.

The manufacturer enclosure whitepaper documents0.7 and1.1 mm glass variants with the same front-to-rear-mount datum, and warns that hard contact against the glass during tightening can detach or crack it. A lipless glass opening supported from the metal rear mount is the preferred starting point here; retain the option of soft pads after actual stack measurement. Do not glue only the glass corners. The guide also permits an appropriately designed perimeter tape mount as an alternative; we prefer screw-removable retention for this build.

Use the lighter enclosure design direction: broad skins around2.4 mm initially, with reinforcement local to the carrier mounts. Remove unused separate Pi mounts and bulky generic display ribs only when the new full assembly is represented. Check PSU/divider/buck clearances, airflow, ribbon bends, GPIO jumpers, USB/printer cable, power plug and SD access. No final electrical or thermal layout is implied by this mechanical proposal.

## Confirmed glass outline and provisional corner radius

User measured the glass as **193 × 111 mm** on 23 September, consistent with the nominal 192.96 × 110.76 mm reference. The official drawing shows rounded corners but does not dimension their radius. Scaling its vector outline gives tangent offsets of approximately 7.9 mm; use **R8 provisionally**, not as a manufacturer-certified dimension. Reproducible values are saved in references/display_glass_corner_inference.json. Provide perimeter clearance/corner relief and verify a small fit sample so a minor corner variation cannot load the glass. No additional manual radius measurement is required at this stage. These are reference data and mounting requirements; production CAD has not yet been revised.

## Depth confirmed and V40 fit test

The user confirms **40 mm** total depth with the Pi attached. The user also explicitly requests a precise visual fit. V40 targets a 193.4 × 111.4 mm opening: 0.2 mm clearance per side, provisional R8.2 opening around an R8 glass contour. The rear metal lugs carry the assembly. The glass sits 1 mm behind the navy frame's face; it is not squeezed against a rigid lip.

A small full-outline frame and four brackets have been generated and independently checked in output/v40_display_mount/fit_audit.json. This fit-kit release is separate from the full-enclosure audit: the provisional rear cable allowance overlaps the inherited divider by 188.72 mm³. Do not erase or waive that full-enclosure check. Resolve actual cable routing/power layout before printing the large left body. The nominal 126.2 × 65.65 mm outer M3 lug pattern and glass-to-lug plane must be physically checked using the kit. The earlier 65.6 mm pitch was a rounded reading; the drawing says65.65.

Fusion remains closed at the user's request after Mac performance problems. V40 is not yet synchronized there. The separate fit-kit STEP and mesh files are local and reviewable; keep V39 Fusion clearly distinguished.

Existing V39 display-side projects are review-only and are not released for printing under these new facts. Current printer shell remains accepted. The rear cover was verified finished at231/231 layers before the V40 fit kit was dispatched at21:39 local; both physical checks remain pending.

Sources: see display_hardware.json. The unchanged official drawing is saved at references/original_touch_display_mechanical.pdf.

## Physical contour accepted; integral recessed seat — 24 September

The user reports the V40 frame fits perfectly and shows it around the glass. Preserve the printed193.4×111.4 mm,R8.2 pocket contour. This confirms the practical opening, not the precise glass radius, rear bracket fit, or final retention stack. Rear-bracket clarification is pending.

The user explicitly clarified that there should be **no final navy bezel and no navy lip**. The existing black glass border is the visible surround. The intended geometry is an integral recessed seat in the white sloped panel, with a step behind the glass, not a separate piece overlapping its front. The assistant's earlier interpretation about restoring the original6 mm front overlap was incorrect and must not be implemented.

V41 retains the accepted outline and unchanged V40 bracket shapes, moving the glass and complete relative mounting stack rearward together to recess the glass below the white panel. Fill the old bezel rebate flush with the white face, remove the separate bezel component, and keep the glass free of rigid clamping pressure. Actual body/recess fit and cable/power clearances still require review before a large print.

## Four integral mounts — latest user direction,24 September

V43 merges the four arms into the case and closes the obsolete case-side screw/insert holes. Front-insert the unplugged display and attached Pi; four rear M3×6 screws fasten into the original metal lugs. The integral mounts remain during front removal. Exact nominal swept-envelope checks now include those fixed arms and pass; the earlier V41 check removed the detachable brackets. Existing V40 test pieces are still useful for measuring the same mounting pattern and bearing depth. The final assembly will not need them as loose parts.

Four bearing pads retain3.9 mm thickness and nominal2.1 mm screw engagement. The large case print may need local support beneath integral arms; slicing and real screwdriver/cable access remain to be checked. Unconfirmed actual power architecture and the237.48 mm³ cable/divider clash still hold full-case release. No new print dispatched; Fusion remainsV39.

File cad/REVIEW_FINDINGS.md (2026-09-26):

# v19 enclosure review

## Scope and status

This revision keeps the overall 376.96 × 161 × 181 mm envelope and repairs
mechanical details independent of the hardware measurements. It is a review
candidate, not a production or slicer-approved print release. The generated
reference image provides styling only. Actual hardware takes precedence.

The original archive is preserved. v19 is generated from `lumon_v19.py` and
exported by `export_review.py`; the imported Fusion document is a review copy.

## Findings and changes

| Finding in v18 | v19 change |
| --- | --- |
| Uneven transition beside the lower-left screen corner: rake cut through a previously rounded upright edge | Construct the sloping shell first, then round its actual front edge. Retain the deliberate base-band step. |
| Rear service rebate reached into the rounded rear-left corner; inset base reduced cavity-wall thickness | Move/narrow the left service panel and preserve 3mm walls around the inset base cavity. |
| Display bezel and pocket had identical perimeter size | Add 0.3mm clearance per side to the separate bezel. Adhesive attachment remains to be specified. |
| Forward alignment dowel at Y=15, Z=118 lay in front of the raked left wall | Move it to Y=35 and relocate the nearby upper screw to Y=50. Check hole and surrounding material on both mating walls. |
| Seam counterbore left only 0.8mm of the 3mm wall under the head | Use a full-thickness clearance hole with the screw head accessible inside the left bay. |
| Magnet pockets lacked reliable open seats/lands; some generated enclosed void shells | Replace the speculative magnetic retention with six screw locations: four left, two at the rear of the printer trim. Add connected insert lands and compression sleeves under the covers. |
| Foot inserts were deeper than the tub floor; some locations conflicted with internal packaging | Add raised insert bosses and relocate the eight mounting points into clear regions. |
| 2.2mm rear-panel counterbores cut through the 1.8mm outer skin | Keep the skin and use external screw heads. |
| Solid dark base plate blocked the floor intake slots | Add matching through slots and channels opening at the back of the base. |
| Chamfer along both sides of the base seam produced a V notch | Chamfer the outside perimeter while leaving the mating seam square. |
| Cover imposed an unmeasured paper slot and hid the real printer's top | Replace it with a separate dark, open trim. Its aperture remains provisional; real lid swing, controls and cable access still need checking. |
| Old STEP omitted the blue logo fill and had no useful color separation | Export named, colored bodies, including all six logo regions. Keep hardware references in a separate STEP. |

## Verification and limits

- Independent baseline audit: archived STEP solids were geometrically valid;
  that did not establish good fasteners, assembly access or print orientation.
- v19 checks each main part for one solid, CAD validity and watertight STL.
- All-pairs volume intersections include the case parts, logo, and inherited
  display/printer/Pi/PSU/inlet/buck boxes. See `output/v19/geometry_review.json`.
- Local material probes check insert bores, blind-hole floors, screw passages,
  compression sleeves, rear-panel head bearing and seam fastener surrounds.
- A radial sample of the rear-left corner at seven heights and seven angles,
  sampled every 0.05mm, measured about 1.25mm minimum in v18 and about 3mm in
  v19. This is a targeted check, not a complete minimum-thickness certification.
  See `output/v19/rear_corner_wall_check.json`.
- Three small coupons are extracted from actual geometry: left/right rear seam
  and the screen corner. Each is a valid single solid. They still need slicing
  with the actual printer profile.
- No lid-swing simulation, cable routing validation, physical fit test, thermal
  test or slicer toolpath review has been completed. Hardware boxes are not
  accurate representations of connectors, levers, feet or moving lids.

## Assembly and fastener plan

Keep ribs, lands and floor united with their corresponding shell. Keep covers,
rear panels, feet, screen retainer and dark bezel separate for access and color.
Use the two-module spine joint rather than adding another large visible seam
before knowing the print bed size.

Current geometry has 31 M3 insert locations: spine 5, retainer 4, rear panels 8,
base plates 8, covers 6. Pi pilot holes are separate and are not included in that
count. Two 4mm alignment dowels are provided. These counts are design inventory,
not a finalized shopping list: insert body size, screw engagement and head
geometry need confirmation with the chosen hardware and fit coupons.

Suggested order: test coupons; install accessible inserts in empty shells;
mount display/retainer and required wiring; join the spine while screw access
is clear; fit electronics and printer; attach separate base plates, rear panels,
bezel and covers. Recheck this order with the actual connectors and tools.
The rear lower spine screw is close to the power-supply region: join the modules
before fitting that supply. A removable electronics tray is a sensible later
revision if the confirmed hardware makes service access awkward.

## Remaining design decisions before full-shell printing

1. Confirm actual printer, display assembly, Pi/cooler, power architecture and
   connector dimensions. The printer trim may require a front relief for its
   lid release or controls; do not infer that relief from the generated image.
2. Confirm printer bed, nozzle, filament and multicolor capability.
3. Inspect support paths and removal in a slicer. The upright left shell has a
   roughly 181mm-wide screen opening; “vertical opening” does not make its roof
   self-supporting. If supports prove excessive, separate the front carrier
   with designed screw lands rather than simply cutting the shell in two.
4. Test inserts, dowel fit and bezel rebate. A successful mesh check cannot
   establish real extrusion tolerances.
5. Choose logo method: registered multicolor region, paint, or decal. The small
   disconnected blue islands are not recommended as loose hand-assembled prints.

Print orientations and the part/color table are in `README.md`.

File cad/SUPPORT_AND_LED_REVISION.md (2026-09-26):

# Support and indicator revision

## Hardware correction: tapered casing, downward rocker and LED

User photos, 21 September 2026, show original front/rear walls are not parallel. In the chosen orientation these become upper/lower faces. The prior 131 × 120 × 175mm reference remains only a maximum envelope; it cannot validate support contact, printer tilt or actual outlet alignment when installed. The width coupon passed, not the full cradle. Do not print the full v23 tray/shell as a validated mount.

Original rear power rocker becomes downward-facing. Provide a clearance pocket or through-opening in BOTH tray and any shell floor beneath it, including both switch positions, assembly tolerances and insertion/removal path. The table or eventual foot/base structure must not reach the rocker through that opening. Switch width/height, position and protrusion are pending; no precise hole is guessed from photographs. Define structural support pads on verified casing lands clear of switch and connectors; shim/pad heights may differ to keep the paper-output face aligned. Retainers must secure without wedging tapered casing or loading buttons/lid.

User does not require external feed/lid-release button access; those become available after removing the intact printer for paper service. Conceal with internal noncontact clearance, not a wall resting on controls. LED should remain visible. Preferred proposal: a small separate translucent/off-white insert, supported by a concealed shoulder in the shell, with a light-collection cavity accommodating the sloped native face. Do not claim a fixed matte-PLA wall thickness will transmit enough light; test an optical sample with the actual filament. No direct loading of the native LED lens. Exact LED position and angle pending.

Required measurements: rocker outline, protrusion in both positions and distances to two adjacent edges; original front-to-rear length at lid and bottom (taper); LED outline and centre relative to upper edge in chosen orientation. Photographs establish features but not precise dimensions. The fitted outlet centre remains 60mm from printer top, but its absolute CAD height depends on corrected support placement. No printing authorized for this redesign.

## Additional measurements — 21 September

Original top length 166mm becomes front vertical span; original bottom length175mm becomes rear vertical span. Difference9mm over approximately120mm new front/back depth. This constrains overall taper but does not establish how the9mm is divided between upper and lower faces. Do not assume a9mm wedge under the printer or move the fitted outlet until support pose is determined. Keep175mm as conservative height envelope.

Downward switch outline23×16mm; distance65mm from original top/new front edge and16mm from closest side edge. Edge-versus-centre datum, side in installed coordinates and protrusion remain unconfirmed. Store measurements without silently locating a precision hole. Prefer open relief beneath rocker with support lands outside its full travel; table/base and insertion path clearance still required. No print sent.

## Confirmed rocker clearance

User confirms offsets65mm from new front and16mm from nearest side are to NEAREST EDGES. Rocker protrudes4.5mm. With provisional23mm across-width and16mm front/back axis assignment, rocker spans65–81mm from front and16–39mm from nearest side. Proposed relief27×20mm gives2mm margin on each side:63–83mm from front,14–41mm from nearest side. Reserve at least6.5mm free depth normal to the casing (4.5mm rocker +2mm margin), in both switch positions. These are design allowances, not a validated installed cutout.

Any tray/floor/base structure must clear this volume. A closed pocket under the final position alone is insufficient if the downward rocker crosses solid supports while sliding in; use an open insertion channel or a removable support arrangement. Resolve actual taper/support pose and transverse-side mapping before committing support geometry. No print sent.

Active revision: v25_tapered_printer, source printer_bay_v25.py. User-authorized60/40 taper implemented with bearing rails, rear-open switch channel, fitted90×14 paper slot and separate hollow0.8mm LED insert. LED40×4.5 projected, upper edge2mm down (interpretation); switch mapped left in top plan with FRONT at top. See v25 README for assumptions and checks. Printing requires explicit user confirmation.

## Translucent PETG available — 21 September

User has translucent PETG. Preferred final LED diffuser is the existing separate insert printed in PETG and assembled into the PLA shell. Do not combine the materials as a bonded multi-material print. Existing light-grey PLA trial is still useful for geometry/fit. PETG brand/profile and loaded slot are not specified; do not send PETG using the current A2 PLA profile. Keep the recessed flange and noncontact cavity; verify optical transmission before final installation.

## V26: lateral taper correction

User confirms final front/outlet width132mm and rear/cable-face width143mm; switch remains underneath. V25 constant-width cradle invalid. Revised source cad/printer_bay_v26.py and output/v26_double_taper_printer accommodate both tapers, with provisional symmetric lateral split. Cradle guide gaps134/145mm; bay width175mm. Geometry audits pass for estimated envelope. Replacement cradle project prepared but not sliced/sent. Full shell remains pending physical fit and full-device integration.

## V27 physical-fit acceptance and refinement

V26 mostly fits; user waives repeat cradle trial. Increase bottom support rise5.4 to8.1mm, reduce total lateral gap0.6mm. Aperture/LED front datum rises2.7mm while retaining166mm front span. Updated CAD audits pass; final cradle included with assembly parts. Shell native supported project sliced8h49m/335.77g/six filament changes,not sent. Remaining parts prepared but not sliced. See output/v27_refined_printer/README.md; native Bambu settings must be verified because imported packer settings were not fully honored.

## V28 integrated top — user-requested cancellation

V27 shell cancelled at layer1/805. V28 merges4mm top into shell, removes both top fasteners and insert bores, retains201mm external height and rear extraction. Front-down orientation prints top as upright wall; separate cover was not required for printability. Geometry audits pass; no replacement dispatched. Bed must be cleared after cooling. See output/v28_integrated_top.

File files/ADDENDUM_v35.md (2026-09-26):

# LUMON_TERMINAL — v3.5 addendum

Adds the 10° display rake and the internal-PSU power bay. Generated by
`lumon_v35.py`. Envelope unchanged: **359 × 153 × 144 mm**.

---

## 1. Where the aesthetic details land

The split is not "nice things last", it is whether the detail moves a
mounting face.

**Form-defining — done now, in v3.5.** Rake, and by extension the front
plane's position at every height. Everything that mounts to that plane —
window lip, locating ribs, retainer bosses, retainer frame — is generated in
a local upright frame and then raked as a unit, so they stay coplanar by
construction rather than by hand-fitting.

**Surface — M4.** Fillets and chamfers on the top and front edges, shadow gap
at the seam, bezel chamfer, vent slot styling, ID plate, status LED, feet.
These only cut material from surfaces that are already fixed.

Corner radii sit awkwardly across the two: the external radius is currently
6 mm and is a surface detail, but going much above ~8 mm starts eating the
space the corner bosses occupy. Treat 8 mm as the ceiling unless the bosses
move first.

---

## 2. What the rake cost

- Front face leans back **25 mm** over the 144 mm height.
- The display's vertical extent shrinks to 110.76 × cos 10° = **109.1 mm**.
  That is inherent to tilting, not a modelling artefact.
- The display's rear face sweeps backwards as it rises: **y ≈ 29 mm at
  z = 28**, **y ≈ 49 mm at the top**. Three things had to move out of that
  swept volume: the mains barrier (now starts at y = 40), the PSU's front
  corner blocks (shortened to 6 mm), and the front pair of top-plate bosses
  (now at y = 58, behind the display's top rear edge). The top plate's front
  edge is located by the rebate ledge instead of by screws.
- Side stiffening flanges are clipped to start behind the display assembly.

### The seam step

The printer module cannot be raked. Its lid opens straight up and its front
sits 3 mm behind the front face, so raking that module would drive the wall
into the printer. The result is a **25 mm step at the top of the seam**: the
display console leans back, the printer block stands vertical.

This is defensible — it reads as a raked console beside a forward equipment
block, which is what the render implies anyway. But it is a real decision, not
a side effect. At M4 it gets resolved deliberately: either a chamfer running
the step into the seam, or a shadow gap that declares it. If you would rather
they align, the alternative is moving the printer back ~25 mm, which pushes
the depth to about 178 mm.

---

## 3. Power architecture

One 24 V open-frame supply, one mains entry, one buck for the Pi.

```
 IEC C14 (fused + switched) ─ fixed rear wall
        │
        └─ 24 V PSU ─┬─ 24 V ──► printer  (through the spine pass-through)
                     └─ buck ── 5 V ─────► Pi ──► display (GPIO / USB)
```

- **PSU pocket 129 × 97 × 30** at x = 66, y = 40. Sized for Mean Well
  LRS-100-24 (4.5 A, 108 W); the LRS-75-24 (99 × 97 × 30, 3.2 A) drops into
  the same pocket with longer corner blocks. Captured by printed corner
  blocks, not screwed — its own M4 holes stay unused and unmeasured.
- Pulled 13 mm forward of the rear wall so the rear-panel insert bosses clear
  it. They collided in the first pass.
- **Mains inlet in the fixed strip of the rear wall**, not in the removable
  service panel, so mains wiring never crosses a joint you open for service.
  Cutout 47.2 × 28.3 for a fused + switched snap-in C14; the outer face is
  thinned locally to 1.5 mm, because snap-in clips will not grip 3 mm.
- **Mains barrier** at x = 59, 46 mm tall, separating the PSU zone from the
  Pi and buck.
- **Pi mounted vertically** on the left wall on four 58 × 49 standoffs, ports
  facing rear. Flat on the floor it would not fit beside a 129 mm PSU.
- **Ventilation:** intake slots in the floor under the PSU, exhaust high in
  the rear wall. Nothing on any visible surface.

### Sizing caveat

108 W assumes a 24 V printer. **Read the voltage and current off the label of
the printer's own brick at M0** — that is the sizing input and it is currently
a guess. If the printer turns out to be 12 V, the whole rail changes.

Mains inside a printed enclosure: PETG or ASA, not PLA. Terminal block
covered, inlet earthed to the PSU chassis terminal, mains conductors strain
relieved and kept on their own side of the barrier.

---

## 4. Assembly order change

The spine screw at (y 140, z 45) sits above the PSU and must be driven
**before** the PSU goes in. Splitting the modules later means removing the PSU
first.

---

## 5. Open

Printer W/D/H, lid swing, LED and button positions, port positions, display
assembly thickness, Pi model, buck module dimensions, printer supply voltage.

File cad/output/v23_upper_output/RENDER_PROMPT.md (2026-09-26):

# Upper-output appearance concept

Built-in image_gen; reference: whole_enclosure_study.png. Appearance concept only: exact printer controls, screen graphics and base details remain illustrative. No print authorization.

Use case: product-mockup, CAD-to-photoreal concept. Use the attached CAD as strict reference for the geometry, proportions, view, opening locations and logo. Render a completed Lumon-inspired desktop device on a neutral desk in soft studio light. Matte warm off-white shell (Cotton White approximately #F4EFEB), matte muted navy bezel/base/logo (Army Blue approximately #2E4462), subtle fine 3D printed surface. Left module has a sloping landscape LCD in the existing bezel, screen filled with a minimal teal-on-dark task list. Right taller module MUST have the black rectangular printer face in the UPPER HALF exactly where the CAD has a grey rectangle. Upper edge of aperture close to top, lower edge around mid-height. The integral white LOWER HALF has the navy LUMON globe logo, preserve exact CAD logo placement. Inside that UPPER black aperture show exposed native receipt printer face: a small horizontal blue status bar with triangular buttons beside it near the TOP of the black face, a horizontal paper exit BELOW these controls but still in the upper half of the enclosure, short white 80mm receipt emerging forward/down. This is the native printer face, not an added removable enclosure panel. Keep receipt short enough to show logo below. Do NOT move outlet to lower half; do NOT place logo above printer opening. No visible front screws or seam outlining the white lower panel; front shell is integral. Keep original CAD two-module proportions, right module 20mm taller, the existing vertical module joint, right top flat and off-white, no keyboard or top paper outlet. Slightly round edges only as CAD. Screen content and exact printer face details illustrative. One hero image, no annotations or extra views, no dimension arrows.

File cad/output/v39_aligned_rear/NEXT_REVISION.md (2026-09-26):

# Next shell revision — physical feedback, 23 September 2026

## Exposed unused insert hole — 26 September feedback

Remove the unused screw-insert bore exposed on the printer-bay edge beside
the display glass in the user's photo:
`/tmp/codex-remote-attachments/01a0bf3e-2220-7252-adef-d07f9ff37b1f/491BE101-4384-473F-91DF-DCE7AA8ACD06/1-Foto-1.jpg`.
The next revision should have a continuous finished surface there. Identify
the exact source feature against this photo before modifying CAD; remove any
corresponding unused mating bore, while preserving the other functioning
inter-bay joints and display mounts. This is future-revision feedback, not
a request to reprint or alter the currently printing inlet panel.

User accepts the current V39 shell and confirms the existing V31 cradle and printer fit perfectly inside it. Do not reprint this shell now. User authorizes the next piece (the compatible V39 rear cover) and confirms the build plate is clear.

The lower light-coloured band is recessed 0.8 mm on the exterior, Z9–33 mm. This is deliberate styling geometry inherited from V33 and retained through V39, not evidence of filament shrinkage. With the shell printed front-face down, the recessed front strip needs support; user photographs show the navy support interface still present in the first photo and the stepped side outline in the second.

For the next shell revision, make this light-coloured lower band flush with the main exterior on front and sides. Preserve the tested inner floor, cradle datums, switch/cable relief, insert positions and retention interfaces. Coordinate the matching rear-cover lower band and display-bay exterior so the assembly remains cohesive. Keep the separate navy foot as a separate design decision; do not silently remove its base functions. Review the revised print orientation and support preview to eliminate this unnecessary exterior support strip.

Source anchors: build_v33_unified_body.py BAND_INSET=.8; V38 rear cap repeats the .8 mm lower band; V39 retains the printer-side geometry. No geometry or current prepared slice has been changed by this note.

## Weight reduction — additional user feedback

User reports that the shell feels too heavy and asks for a better balance of robustness and filament use. Treat this as a design requirement for the next shell revision and a reason to review the remaining unprinted parts before release. The already printed shell is accepted; do not scrap it. The rear cover is already printing and was not stopped or modified.

Evidence from the actual V39 shell G-code (see weight_audit.json): 4 wall loops, 5 top / 5 bottom layers, 15% gyroid. Slicer model mass approximately 593.16 g; total with support/purge/tower 634.49 g. Summed XY deposition by feature gives 415.39 g of inner+outer wall paths, 72.52 g sparse infill, 54.42 g internal solid infill, 39.54 g support/interface. These are toolpath estimates, not a physical weighing. The feature sums match the slicer total after excluding stationary purge. Existing CAD includes 3 mm front/outer wall, 4 mm roof/floor, a continuous 9 mm inter-bay wall, and thick rear mounting rails.

Reducing sparse infill from15% to10% would, under a simple proportional estimate, save only about24 g on this shell (approximately4% of model mass); actual reslicing is required. Geometry and perimeter allocation offer the larger opportunity. The unprinted display body has only23.26 g of sparse infill in612.70 g total, making infill-only changes particularly ineffective there.

Candidate design, requiring slicing and physical stiffness/retention checks before release:
- Broad non-load-bearing skins: start at2.4 mm; preserve overall outside dimensions and tested internal bearing/locating datums. Expand selected cavities to thin panels without moving the printer, cradle or screw axes. Use short local ribs where large panels flex.
- Inter-bay wall and full-height rear rails: replace excess bulk with a thinner web plus local mounting bosses/gussets. Preserve the complete insert engagement depth and surrounding material at each screw. Do not merely change the9 mm wall globally, since it locates and joins the bays.
- Printer-bearing floor: preserve cradle seats and load paths; consider pockets between them rather than blanket thinning.
- Initial slicer candidate:3 wall loops,4 top/bottom layers,8–10% gyroid in remaining thick regions. Keep local reinforcement around inserts, inter-bay joints and retaining contacts. Thin skins may remain effectively solid; fewer loops alone is not a guaranteed mass saving.
- Unprinted navy feet: investigate a ribbed underside retaining the existing outer appearance, bearing/bonding pads, cable/switch openings and rear-cover clearance. Review the unprinted display body/roof before using current heavyweight slices.
- Coordinate with the flush lower-band correction. Keep the current V39 cover compatible with the accepted shell; future matching pieces must be versioned separately.

Before any revised print: compare model/support mass and time against V39 in Bambu; inspect unsupported roofs, panel skins and reinforced fasteners. Validate with a representative panel/corner sample using the actual filament and orientation if needed. Do not claim a final percentage saving or validated strength until those checks are complete. No revised lightweight CAD or G-code has yet been released.

## Closed navy underside — 24 September feedback

The V42 lean slice of the original V39 navy base is printed and the user confirms it fits; they will glue it later. Keep this accepted part. For the next base revision, the user prefers a closed flat underside instead of openings copying the shell-floor reliefs. This supersedes the open/ribbed underside suggestion above.

V30 and V38 conservatively extended rocker and cable service volumes through the complete base to ground level. A matching through-cut below every shell-floor aperture is not intrinsically required. Develop a thin continuous bottom skin below internal clearance recesses, with necessary rear/side exits, rather than filling the base solid. Verify rocker clearance in both positions, plugs/cable bends and rear insertion/removal against actual hardware; the old ground-reaching keepout boxes do not establish the minimum physical clearance. Preserve the accepted outer fit and adhesive lands and review weight/time after slicing. No closed-floor geometry or print is released yet.

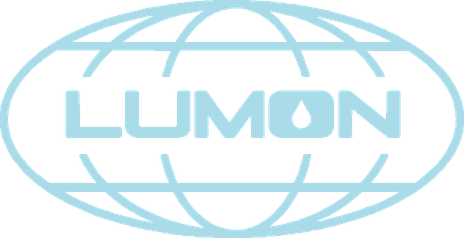
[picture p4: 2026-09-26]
software/assets/lumon-cyan.png

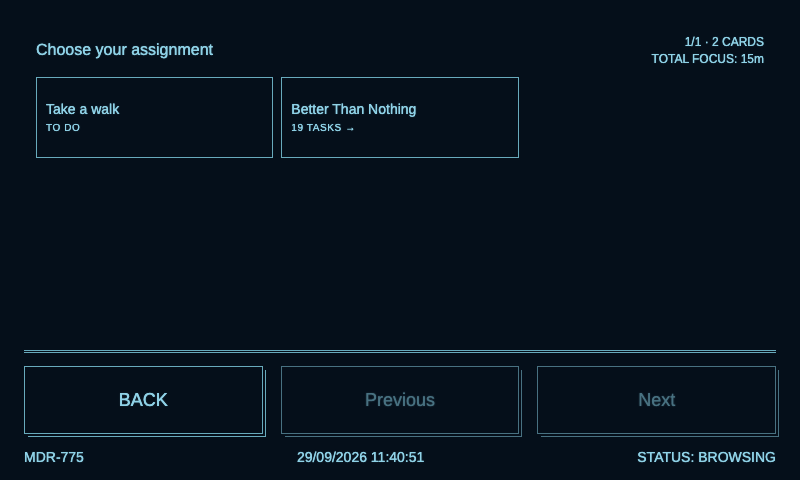
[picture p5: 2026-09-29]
software/preview/manage-mdr-grouped-main.png

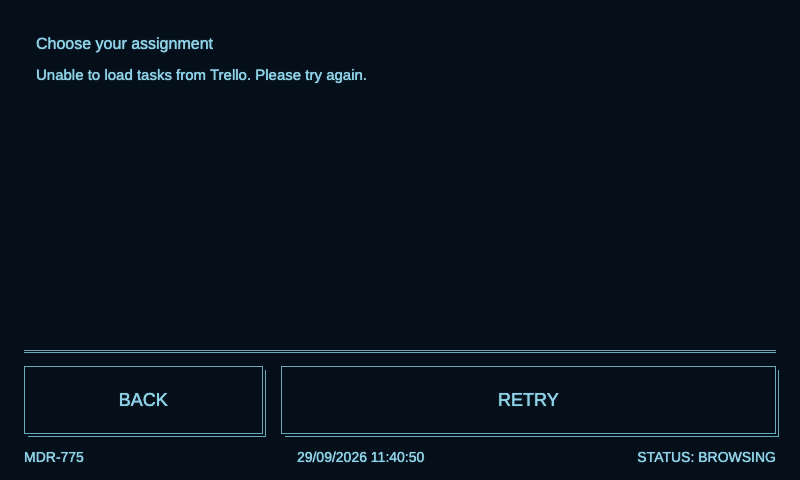
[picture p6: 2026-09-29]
software/preview/manage-mdr-offline.png

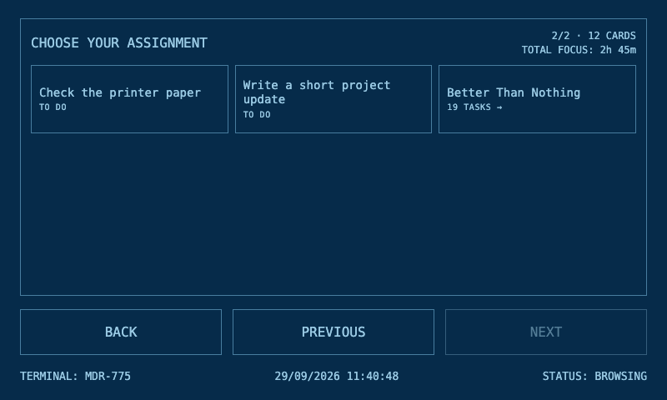
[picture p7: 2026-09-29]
software/preview/manage-classic-page2.png

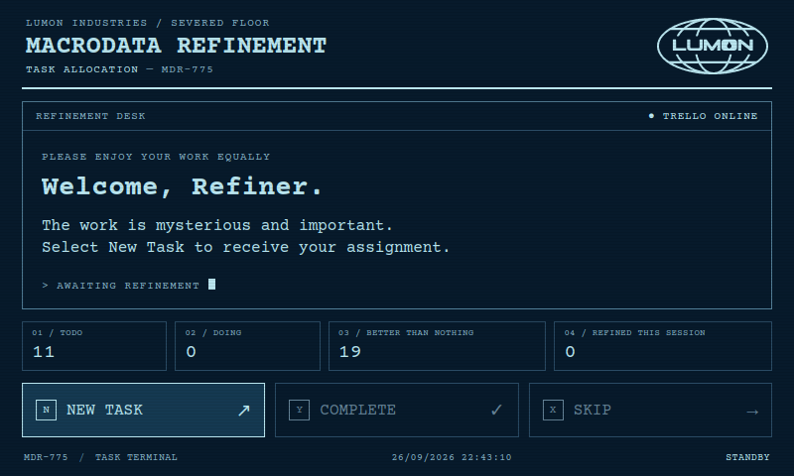
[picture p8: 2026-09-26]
software/preview/pi-after.png

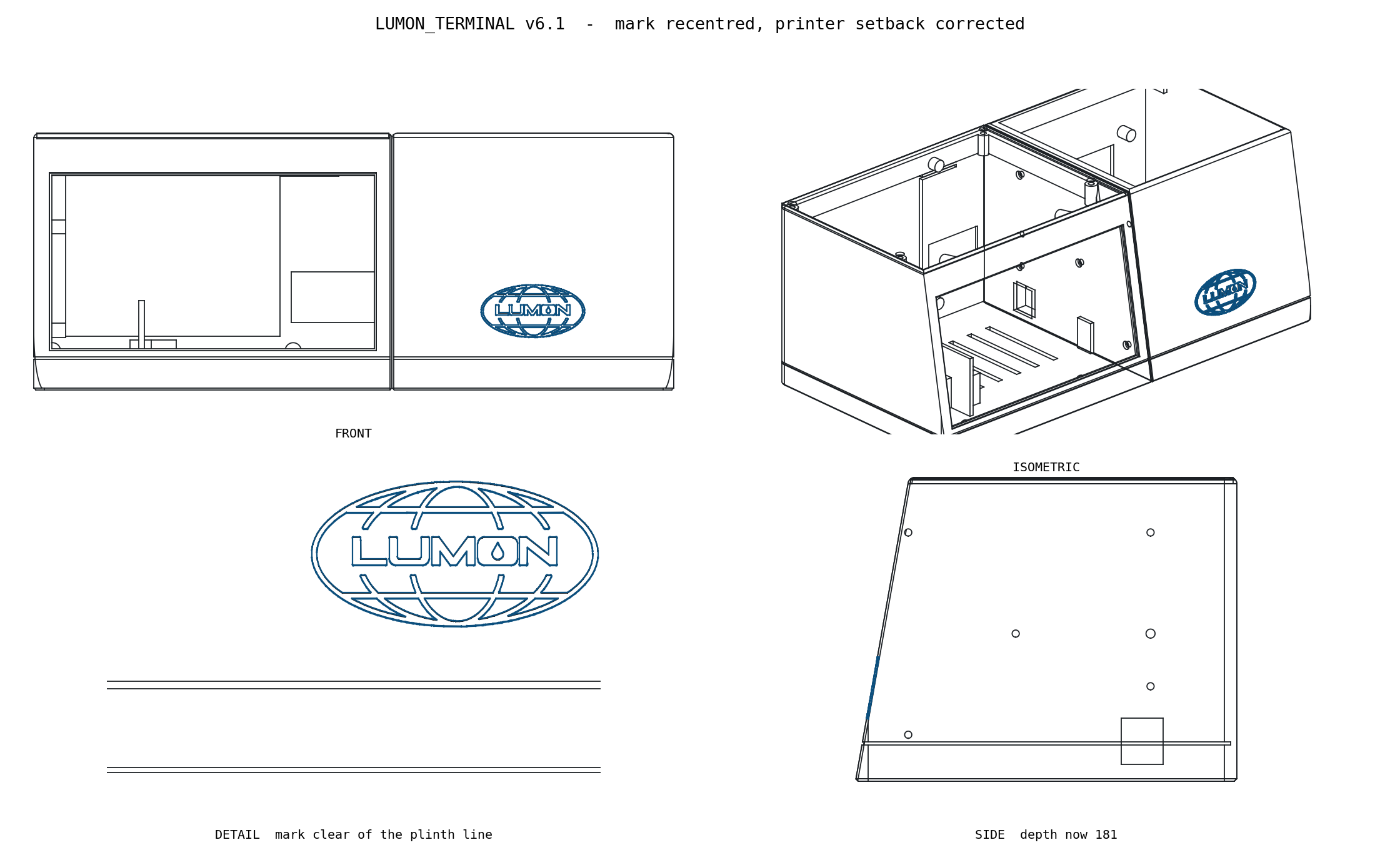
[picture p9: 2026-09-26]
files/v6_views.png

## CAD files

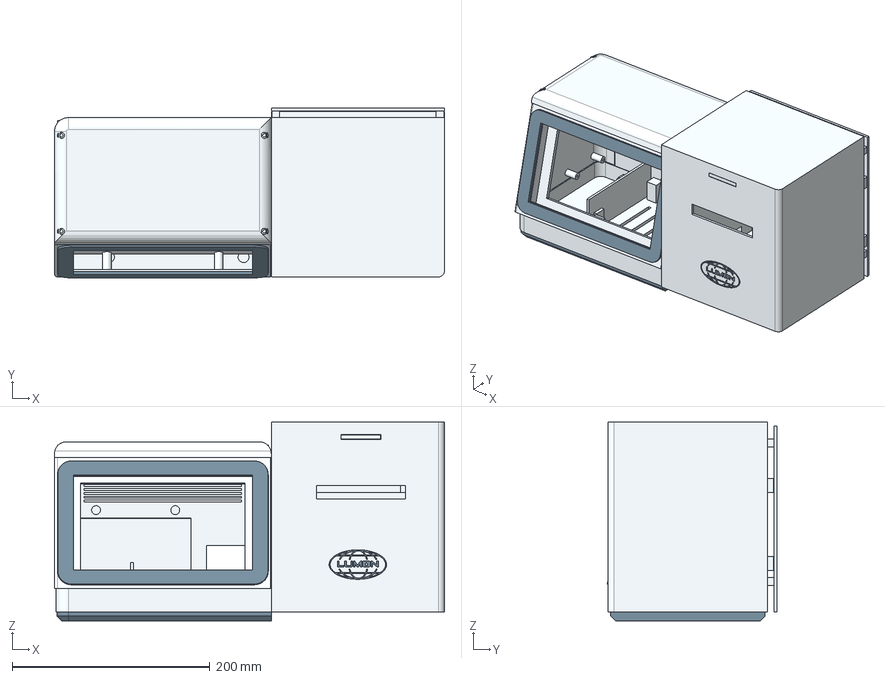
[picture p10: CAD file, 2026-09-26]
cad/output/v29_rear_vent_fix/whole_enclosure_review.step
394.0 x 171.5 x 201.0 mm
tub_left
top_plate_left
display_retainer
rear_panel_left
foot_left
display_bezel
cradle_tray
retaining_bar_58
retaining_bar_137
rear_cover
logo
led_diffuser

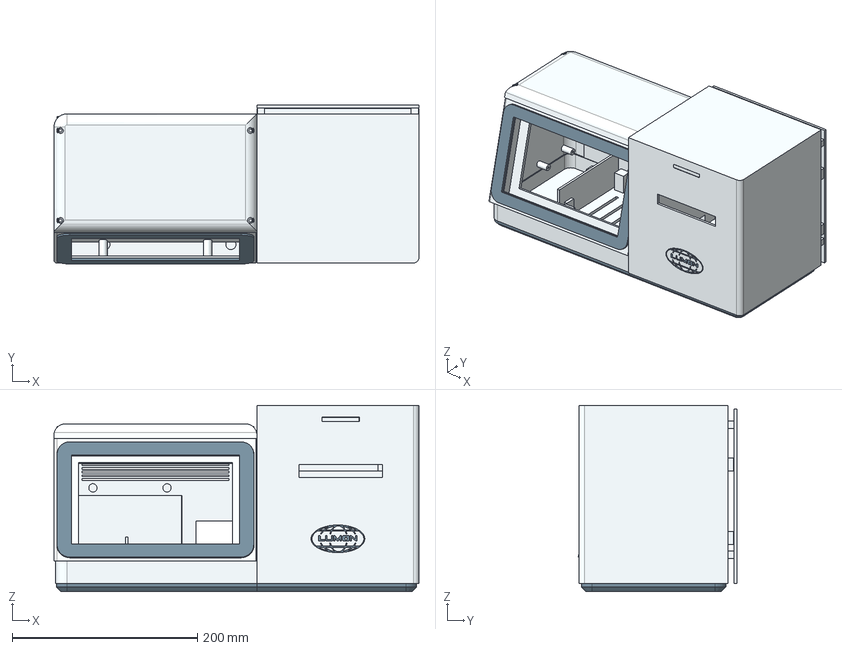
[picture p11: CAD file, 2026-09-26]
cad/output/v30_printer_plinth/whole_enclosure_review.step
394.0 x 171.5 x 201.0 mm
tub_left
top_plate_left
display_retainer
rear_panel_left
foot_left
display_bezel
cradle_tray
retaining_bar_58
retaining_bar_137
rear_cover
logo
led_diffuser
foot_right_bonded

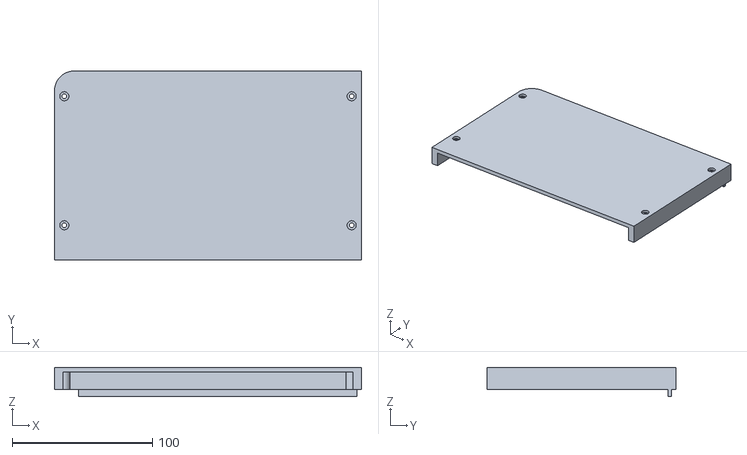
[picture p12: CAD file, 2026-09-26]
cad/output/v33_unified_body/top_plate_left_assembly.stl
219.0 x 134.8 x 21.0

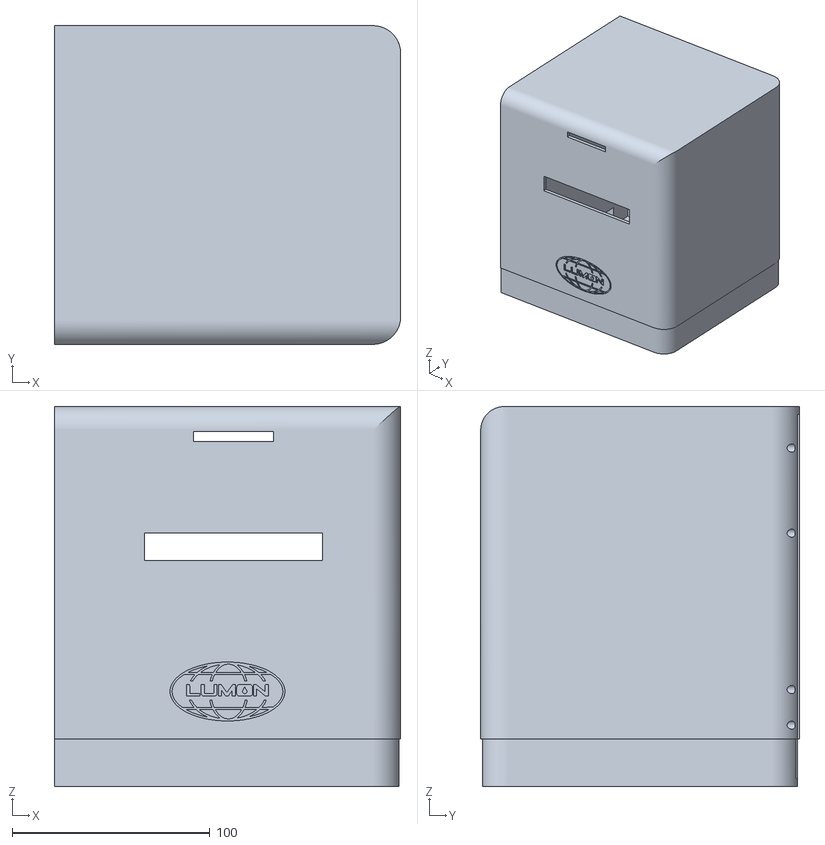
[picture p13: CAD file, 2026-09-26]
cad/output/v34_sloped_connected_roof/shell_assembly.stl
175.0 x 161.0 x 192.0

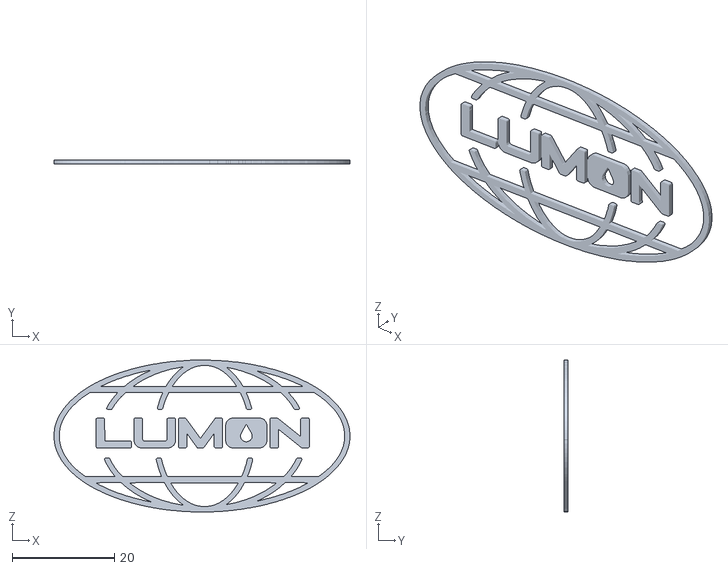
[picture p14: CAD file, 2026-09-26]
cad/output/v37_logo_spacing/logo_assembly.stl
58.0 x 0.8 x 29.8

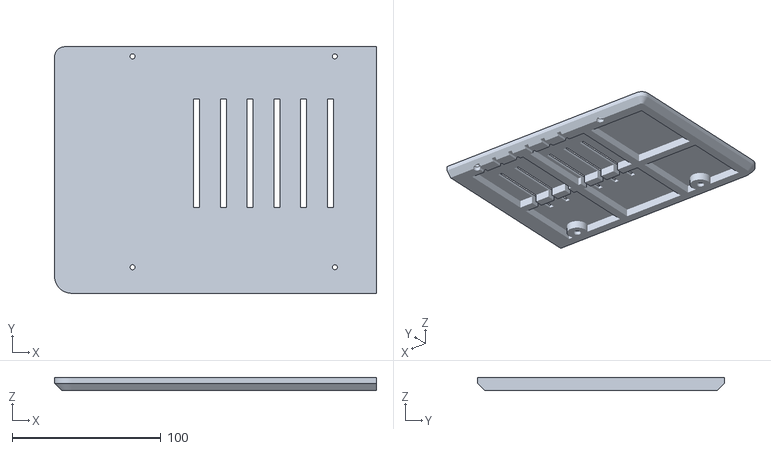
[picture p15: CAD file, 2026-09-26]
cad/output/v40_display_mount/foot_left_assembly.stl
216.5 x 165.8 x 9.00

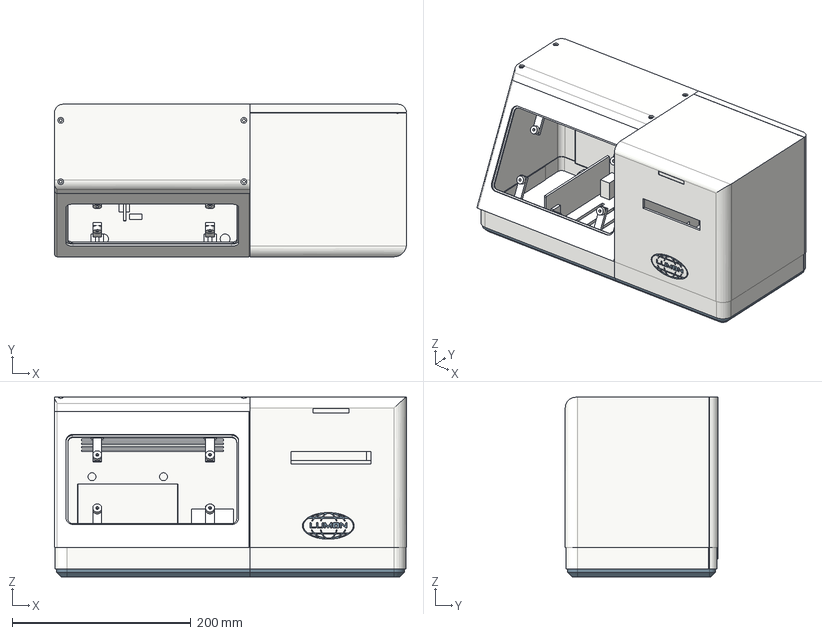
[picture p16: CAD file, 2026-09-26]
cad/output/v43_integral_display_mounts/whole_enclosure_review.step
394.0 x 170.8 x 201.0 mm
tub_left
top_plate_left
rear_panel_left
foot_left
cradle_tray
led_diffuser
foot_right_bonded
rear_cover_integrated

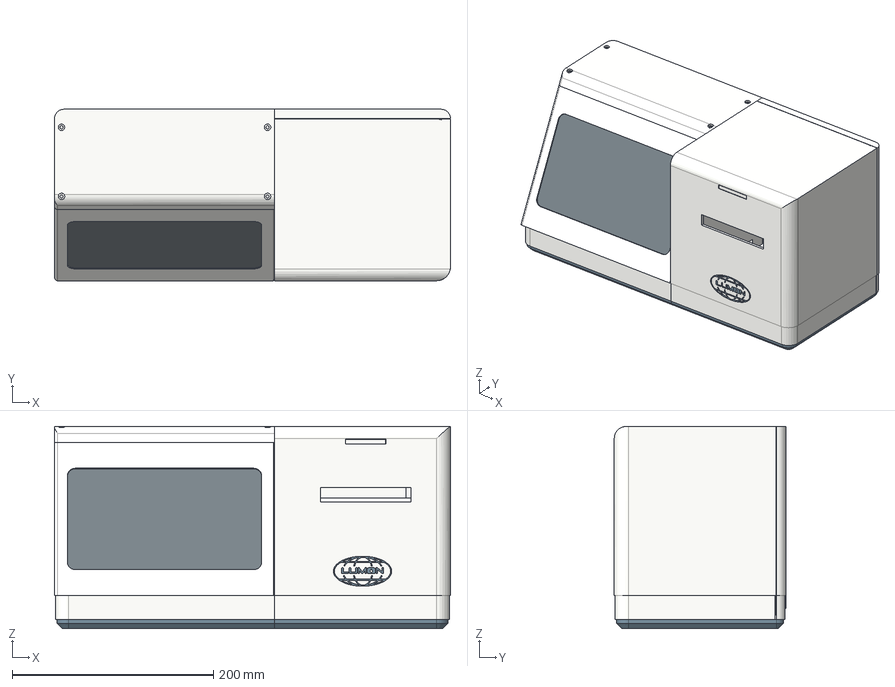
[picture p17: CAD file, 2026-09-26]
cad/output/v44_bearing_seat/glass_1p1/whole_enclosure_with_hardware.step
394.0 x 170.8 x 201.0 mm
tub_left
top_plate_left
rear_panel_left
foot_left
cradle_tray
led_diffuser
foot_right_bonded
rear_cover_integrated
REFERENCE_glass
REFERENCE_chassis_nominal
REFERENCE_attached_Pi_nominal

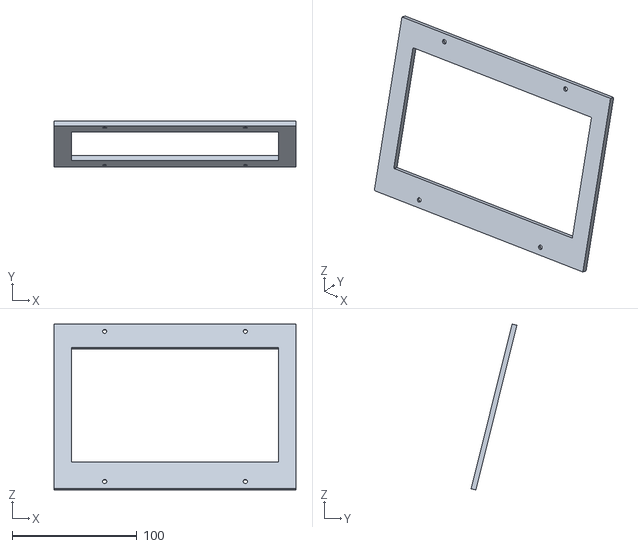
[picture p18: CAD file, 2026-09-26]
cad/output/v32_equal_height/display_retainer_assembly.stl
194.4 x 36.8 x 133.2

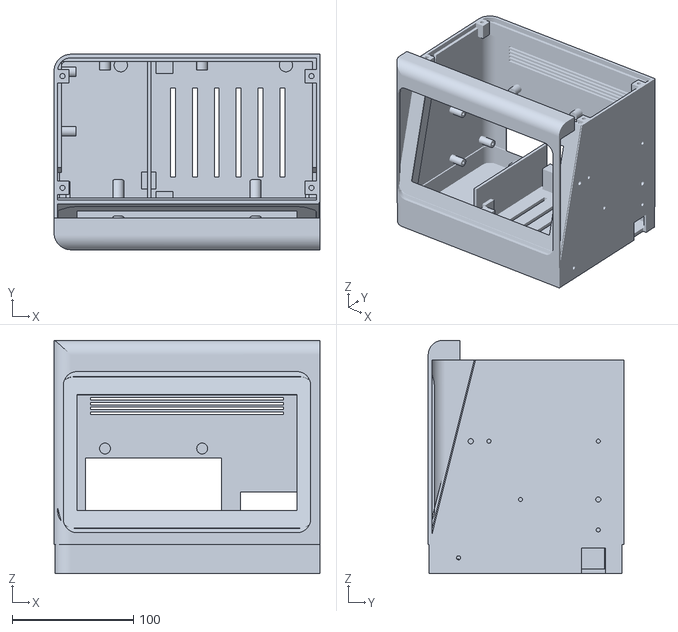
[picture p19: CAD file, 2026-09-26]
cad/output/v33_unified_body/tub_left_assembly.stl
219.0 x 161.0 x 192.0

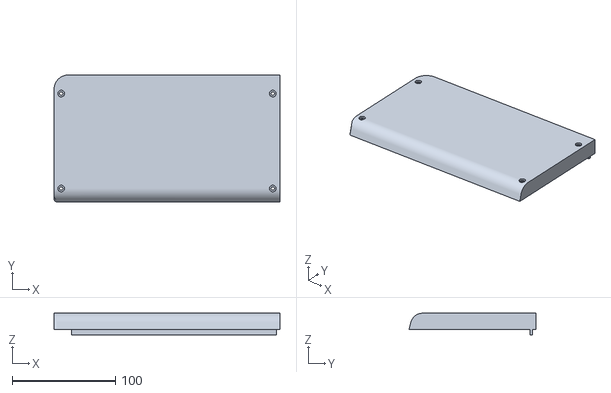
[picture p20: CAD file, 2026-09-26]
cad/output/v34_sloped_connected_roof/top_plate_left_assembly.stl
219.0 x 123.1 x 21.0

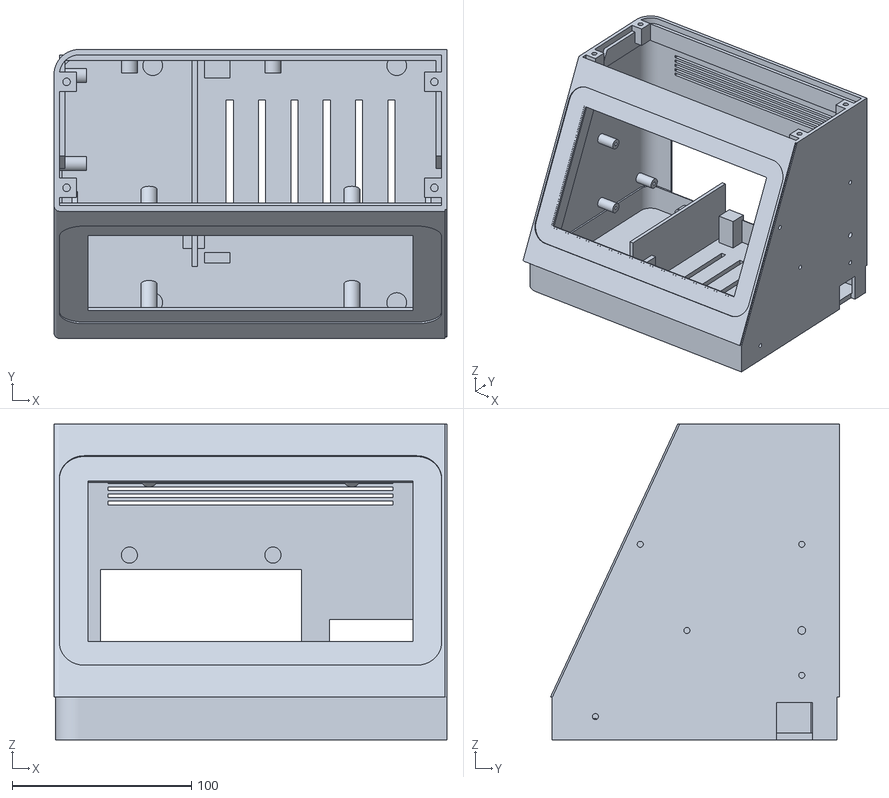
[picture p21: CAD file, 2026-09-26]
cad/output/v35_desktop_terminal/tub_left_assembly.stl
219.0 x 161.0 x 176.0

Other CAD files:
cad/output/v35_desktop_terminal/whole_enclosure_review.step
cad/output/v36_outlet_alignment/whole_enclosure_review.step
cad/output/v44_bearing_seat/glass_0p7/whole_enclosure_review.step
cad/output/v44_bearing_seat/glass_0p8/whole_enclosure_review.step
cad/output/v45_display_seat_3mm/glass_0p8/whole_enclosure_with_hardware.step
cad/output/v49_measured_display_depth/whole_enclosure_review.step
cad/output/p1s_fit_plate/LUMON_v19_fit_test.3mf
cad/output/p1s_fit_plate/LUMON_v19_fit_test_setup.3mf
cad/output/p1s_fit_plate/dark_bezel_corner.stl
cad/output/p1s_fit_plate/light_screen_corner.stl
cad/output/p1s_fit_plate/light_seam_left.stl
cad/output/p1s_fit_plate/light_seam_right.stl
cad/output/v19/LUMON_v19_colored_review.step
cad/output/v19/assembly_stl/display_bezel.stl
cad/output/v19/assembly_stl/display_retainer.stl
cad/output/v19/assembly_stl/foot_left.stl
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

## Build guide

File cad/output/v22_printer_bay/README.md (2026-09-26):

# V22 rear-loading printer bay — prototype, not print-released

**USER HOLD: preparation only; do not print until renewed user authorization.**

Source: `cad/printer_bay_v22.py`. Bambu project packer: `cad/review/pack_printer_projects.py`.

## Design

The intact printer slides in from the rear onto a removable tray. Two rear bars retain it; a separate rear cover conceals them. The front is part of the main shell and has no removable panel or front screws. Side guides have 1mm nominal clearance to the measured 131mm body width, so its corner radius is not needed. The native keyholes (61mm centres, 132mm from large-hole centres to original rear/cable edge) are recorded but unused.

Rotated printer envelope: 131 W × 120 D × 175 H mm. Controls face forward near the bottom, original rear/cable edge is above. Front clearance is 1mm, rear retaining-pad clearance 0.5mm. Optional removable shims can take up play after trial fitting. Never force the body into place.

The front aperture is 127 W × 88 H mm, exposing a generous lower region for the native cutter and buttons. Their exact locations and paper trajectory are not measured; this aperture requires physical verification. The grey block in renders represents the printer envelope, not a second panel to print. Native printer casing, lid and mechanism stay intact.

## Assembly and paper changes

1. Fit M3 heat-set inserts in the tested 4.2mm bores, flush and square. Keep bores clear.
2. Place the tray on the shell floor and slide the printer in from the rear.
3. Confirm the front opening clears the cutter, paper and buttons, and pads contact solid casing. Route cables through the upper rear opening without pinching or tight bends.
4. Attach two retaining bars with four M3×12 screws (6mm bar thickness, nominal 6mm thread engagement).
5. Attach the rear cover with four M3×14 screws (9.5mm cover/spacer stack, nominal 4.5mm engagement).
6. Attach the top using two M3×8 screws (4mm cover, nominal 4mm engagement). Check screws do not bottom out; tighten gently.

For paper changes: disconnect cables, remove rear cover and both bars, slide the whole printer rearward, then open its native lid outside the enclosure. The top may remain fitted according to the rectangular-body removal check. Reinstall in reverse. Spine attachment to the display module uses the inherited interface and is separate from these ten screws.

## Prepared plates

| File | Parts | Physical AMS slot | Nominal layers at 0.2mm |
|---|---|---|---|
| 01_shell_with_logo.3mf | Integral-front shell and registered flush logo | A2 shell, A1 logo | 805; both colours only in first 4 |
| 02_cradle_and_bars.3mf | Tray and two retaining bars | A2 | about 213 |
| 03_top_cover.3mf | Top cover | A2 | 20 |
| 04_rear_cover.3mf | Rear cover including integral spacers | A2 | about 48 |

Layer counts above are geometric estimates, not slicer results. A2 is light-grey Generic PLA, A1 dark Bambu PLA Matte. Only the shell plate requires colour changes. Shell prints front-face down, with the 0.8mm logo against the plate; all other parts are single colour. Never independently centre the shell and logo STLs: the registered files share the same transform and are assembled in the prepared 3MF.

Proposed settings: P1S 0.4mm, 0.2mm layers, four walls, five top/bottom layers, 15% gyroid, 5mm outer brim. Supports currently disabled for inspection, not yet validated. Slicer must confirm bed/exclusion-area and prime-tower clearances, bridging/overhangs, correct filament allocation and time/material totals before sending.

## Verification and remaining work

`checks.json`: six individual structural solids plus six-region logo; all meshes watertight, no significant pairwise/body-envelope collisions, rear-removal sweep clear with top fitted. This validates nominal CAD geometry, not physical hardware fit or print success.

`whole_enclosure_study.png` / `.step` combines the new bay with the existing display module for proportions. The new bay is 20mm taller than the old 181mm design height. The right plinth/feet and final cosmetic integration are unfinished; this is a printer-bay prototype, not the full case release. Display/Pi/cooler and power/cable fit remain unverified.

Bambu Studio 02.05.00.66 command-line slicing crashed before output on both this project and the previously printed fit-test project. Explicit settings loading also failed profile compatibility. Native UI returned no accessible window. No valid sliced G-code, print-time estimate or waste total was produced, and no print was sent. Resume via Bambu UI when the Mac/window is accessible. Prepared archives still require successful Bambu import and preview validation.

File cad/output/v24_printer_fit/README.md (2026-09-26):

# Printer fit samples — centre datum confirmed

User confirmed 56mm from printer upper edge to outlet vertical centre. Aperture upper edge is 49mm down, lower edge 63mm down; width 90mm, height 14mm, horizontally centred. Selected file: `front_template_centre_56_ALTERNATIVE.stl` (historical filename; this is now the confirmed version). Upper-edge-56 template is obsolete and not on the plate.

Two pieces: centre-datum front template (131 × 69 × 3mm) and actual cradle cross-section (141 × 16 × 20mm, 133mm guide gap for 131mm printer). Hold the template notch/top edge level with printer top and centre it; verify paper alignment, feed/cut and absence of rubbing. Place cradle gauge under the printer to check free fit and resting contact. Neither sample validates full connector routing or retaining pads.

P1S 0.4mm / Textured PEI / 0.2mm / four walls / 15% gyroid / 5mm brim / no supports or prime tower. Both pieces physical AMS A2 light-grey Generic PLA. Bambu GUI estimate 45m42s including preparation, 15.37g, 100 layers. No within-print colour swaps. User authorized starting if under one hour and finished before 11:30 meeting. Send initiated 21 September 10:32 local, printer accepted job and entered preparation, 0/100 layers; device estimated finish 11:18. Full-case printing remains on hold.

Plug measurements: power15mm, square USB12mm, recorded provisionally as protrusion allowances; locations and bend space remain unmeasured. Upper-output orientation is already user-tested.

## Physical sample result, 21 September 2026

User confirms cradle fit is fine; retain 133mm guide gap. Printed centre-56mm template fits acceptably, but moving its opening DOWN 4mm aligns it perfectly: use centre 60mm below printer upper edge, edges 53/67mm below top, unchanged 90 × 14mm size. This supersedes the earlier 56mm value. No repeat sample print requested or sent. Corrected reference geometry is in `cad/output/v24_printer_fit_refined`; preserve this printed job as history. Paper feed/cut through template was not explicitly reported, so do not mark that test passed.

For the current v23 body placement (X16.5..147.5, Z16..191), the fitted outlet rectangle maps to X37..127 and Z124..138, centre X82/Z131. This is centred on the printer, not shell X79. The v23 broad opening remains provisional; carry these coordinates into the detailed front while resolving button access.

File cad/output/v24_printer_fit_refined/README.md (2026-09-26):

# Fit correction — no reprint needed

Cradle sample physically accepted; retain geometry and 133mm guide spacing.

Outlet template: move opening 4mm down from printed centre-56 version. New centre is 60mm from printer top; upper/lower edges 53/67mm. Size stays 90 × 14mm. Source: user physical fit feedback, 21 September 2026.

Exports are corrected reference geometry only. No new Bambu job or dispatch; full-case print hold remains. Original printed files preserved in ../v24_printer_fit. Feed/cut through template not explicitly reported.

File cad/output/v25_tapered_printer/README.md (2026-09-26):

# V25 tapered printer bay — review, not print release

Source `cad/printer_bay_v25.py`. Supersedes v23 bay. **Current authorization (21 September): useful trial prints may proceed provided they finish with margin before 15:30. Verify the bed is clear between jobs. Later prints require renewed authorization.**

## Implemented

Approximate user-authorized60/40 taper: rear span175mm, front166mm over120mm depth; lower/switch face differs5.4mm, upper3.6mm. With reference rear bottomZ16/topZ191, front bottomZ21.4/topZ187.4. Two8mm-wide longitudinal bearing rails follow the lower slope. Original133mm side-guide gap is retained from the passed width sample. Contact lands and real casing curvature still need trial fitting; the approximation is not a scan.

Paper aperture90×14mm, centred on printer X82, not shell X79. CentreZ127.4 follows60mm below the new front topZ187.4; boundsX37..127,Z120.4..134.4. Original tested local60mm datum is retained, not the obsolete absolute height from the rectangular box. White integral front remains; logo below atZ57. Native buttons concealed with nominal front clearance; no external pushers.

Rocker23×16mm, nearest edges65mm from new front and16mm from nearest side, protrusion4.5mm. Left placement follows user's above-view description with FRONT at top of plan. Clearance channelX30.5..57.5, Y67 through rear, cuts both tray and shell floor. Its swept audit reserves2mm lateral and2mm additional depth beyond4.5mm protrusion. It is open-ended to avoid snagging during rear loading. Clear native casing pads carry load rather than rocker. Check side mapping in the top view before fabrication.

LED projected rectangle40×4.5mm, top2mm below front upper edge. Horizontal centring assumed from photographs. Separate hollow diffuser:0.8mm light-transmitting front wall, peripheral rim and rear bonding flange,0.2mm edge clearance to shell. Install from rear with small adhesive points on flange; no force or adhesive on native LED. Current material/transmission, native light angle and setback remain unverified. This is NOT a guarantee that matte light-grey PLA transmits enough blue light; translucent/white insert or thinner membrane can be substituted without reprinting the shell. Print flange-down; membrane bridges only2.9mm across the cavity. Buttons retain nominal1mm body-envelope clearance, but their actual projection is not modeled.

## Assembly

Heat-set bores remain tested4.2mm. Seat tray, slide printer from rear, route cables through lower rear relief, fit both retaining bars (fourM3×12), rear cover (fourM3×14), top (twoM3×8). Use gentle tightening and verify no bottoming. Remove rear cover and bars to withdraw intact printer for paper changes. Disconnect cables first. Body and rocker removal envelopes audited; cable plugs are not fully modeled because locations/bends remain unmeasured. Do not pull against connected cables.

## Limits and outputs

STEP, oriented STLs, registered shell/logo STLs, CAD renders, checks.json. Collision checks use an estimated tapered prism, not detailed hardware. Rear switch keepout is modeled conservatively along its path. Actual support contact, button noncontact, LED transmission and cable fit still require physical review. Full-device base/feet integration and left electronics fit remain unfinished. Print status is recorded below. Each remaining Bambu project requires successful slicing and review before dispatch.

## LED trial sliced in Bambu GUI

05_led_diffuser_trial.3mf imported and sliced successfully:10m08s total,7m13s preparation plus2m55s printing;0.61g model/material estimate,17 layers at0.2mm. Only filament2/light-grey Generic PLA used, no repeated colour changes. Trial is for checking current filament transmission before larger printing. Preview has no error. Sent at 12:51 on 21 September with user authorization; device confirmed active at 12:55. Completion is not yet confirmed.

## Cradle trial ready — not yet sent

`06_cradle_fit_only.3mf`: Bambu GUI estimate 1h23m, 48.85g / 16.38m, 100 layers, A2 light-grey PLA only. No colour swaps. Cradle plus both retaining bars would take 2h18m, so the bars were removed from this trial to leave margin before the meeting. Original combined project remains available. Await a clear bed after the LED trial before sending the cradle.

### Physical checks after cooling

- LED: hold the hollow rear toward the printer's blue LED. Check visibility from normal viewing distance without pressing either native button. No glue yet.
- Cradle: use the confirmed upper-half outlet orientation. Seat the printer gently on the two sloped rails. It should sit steadily without needing to wedge or force the housing between the guides.
- Check that the downward-facing rocker stays entirely inside the relief, with clearance in either switch position. The printer must not rest on the rocker. Check with power disconnected first.
- Slide the printer rearward out of the cradle; neither the switch nor the casing should catch. Check the cable route with the plugs attached, without bending them sharply.
- This trial checks the support geometry; the final shell, retaining bars, cover and electronics integration are not yet physically validated.

## Translucent PETG available — 21 September

User has translucent PETG. Preferred final LED diffuser is the existing separate insert printed in PETG and assembled into the PLA shell. Do not combine the materials as a bonded multi-material print. Existing light-grey PLA trial is still useful for geometry/fit. PETG brand/profile and loaded slot are not specified; do not send PETG using the current A2 PLA profile. Keep the recessed flange and noncontact cavity; verify optical transmission before final installation.

## Trial dispatch — 21 September, 13:06 local

User reports LED trial is fine and build plate is cleared. Cradle-only job sent to P1S using AMS A2 light-grey PLA. Auto Bed Leveling explicitly disabled at user request; timelapse off. Sliced estimate remains 1h23m, so expected finish around 14:30 with ample margin before 15:30 meeting. Device accepted job and began downloading; final device startup confirmation recorded in cradle_trial_slice.json.

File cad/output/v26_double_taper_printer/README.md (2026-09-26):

# V26 — printer tapered in width and height

Supersedes v25. Preserve v25 as the printed trial history; its constant-width cradle does not fit the full printer.

Confirmed final orientation: paper-outlet front face 132mm wide, cable-plug rear face 143mm wide. The switch remains on the underside. Front/rear heights remain 166/175mm over 120mm depth. Width taper is provisionally symmetric (5.5mm per side); lower/upper height taper remains the user-authorized 60/40 approximation.

Cradle inner guide widths are 134mm at the front and 145mm at the rear. Fixed 8mm support lands remain under the estimated casing throughout its length; physical contact against rounded real surfaces remains unverified. Switch relief is widened to 31mm to accommodate the side-datum uncertainty introduced by the taper and remains open through the rear. Do not force the old cradle onto the printer.

Bay width increases from 158 to 175mm, retaining rear fastener clearance and the existing left seam interface. Paper aperture remains 90 x 14mm, centred on the printer, with its vertical centre 60mm below the front body top. LED diffuser geometry is unchanged apart from its assembly location; use a separately printed translucent PETG insert. Previous PLA insert trial was reported fine.

Generated STEP/STL parts pass solid validity, watertight mesh, pairwise interference, straight rearward body removal and conservative switch-path checks. These checks use an idealized tapered envelope; they do not validate the real curves, buttons or cables. Full-device integration with the display bay remains pending.

06_cradle_fit_only.3mf is prepared for P1S, 0.4mm nozzle, 0.2mm layers, filament 2 light-grey PLA. NOT sliced or sent; previous v25 duration does not apply. Confirm the build plate is clear and check current print authorization/time window before dispatch. User requested skipping automatic bed leveling for repeat printing.

Next physical trial: confirm front and rear guide fit, steady support on sloped lands, underside switch clearance in both positions, rearward withdrawal and connected cable clearance. Do not print the full shell before these checks pass.

## GUI slicing completed — 21 September, 14:42

Revised cradle: slice OK, 1h33m total (7m13s preparation, approximately1h26m model),55.54g,100 layers,filament2. Not sent: starting now would overlap the15:30–16:00 meeting. Skip Auto Bed Leveling at next dispatch as requested; some preparation time remains.

## Print started — 21 September, 14:54

User explicitly authorized starting despite the earlier meeting constraint. V26 cradle sent on A2 light-grey PLA, Auto Bed Leveling off, timelapse off. Device confirms active job preparing,100 layers,55.54g,estimated finish16:26. Physical fit remains to be checked after completion.

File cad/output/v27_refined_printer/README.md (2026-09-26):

# V27 — physical-fit refinements

V26 cradle reported mostly fine. User explicitly requests proceeding without another cradle test. Bottom support rise is increased by50% from5.4 to8.1mm above the rear bearing level; front support rises2.7mm. Lateral guide gap is reduced0.6mm total (0.3mm each side), giving133.4mm front and144.4mm rear. Side guide slope and height are unchanged.

Reference front bottomZ24.1/top190.1 preserves measured166mm front span; rear remainsZ16..191 and175mm span. Paper aperture and LED are raised2.7mm with the front datum; aperture centre remains60mm below front top. This updates the estimated casing profile to fit feedback, not a precise scan or proven rigid-body pose. Width taper remains132/143mm. Switch channel remains conservative and open rearward.

All exported solids/meshes pass validity/watertightness, pairwise collision, body rear withdrawal and switch sweep checks. No physical repeat of refinements is claimed. Whole-enclosure context STEP/PNG includes the older left module for visual review only; display/Pi fit and full base integration remain pending.

## Print preparation

Use01_shell_supported.3mf for the shell: saved by Bambu Studio with tree(auto) supports enabled,2 wall loops,15% infill. GUI slicing:8h49m,335.77g total,15.85g supports,1.96g purge,0.8g tower,6 filament changes,805layers. No cantilever warning remains. Slot2 light-grey PLA body,slot1 navy PLA logo. Shell lies front-face down; logo is confined to initial layers. Native archive contains meshes/settings, not saved G-code. No print sent.

The generated01_shell_with_logo.3mf is an intermediate, not the reviewed native variant. Programmatic settings were not fully applied by this Bambu version; verify settings in GUI for all remaining projects. Do not overwrite01_shell_supported.3mf by rerunning the packer.

Other prepared projects:02_cradle_and_bars (final refined cradle, not another trial),03_top_cover,04_rear_cover,07_retaining_bars_only (alternative if cradle handled separately). These remain unsliced; no duration claims. Use separate single-colour jobs for these parts. PETG diffuser remains a separate insert STL; profile/loaded slot not specified, so no PETG print project dispatched.

Assembly: install4.2mm heat-set inserts; seat refined cradle, load intact printer from rear, install two retaining bars (fourM3x12), rear cover (fourM3x14), top (twoM3x8). Check screw bottoming and retain the switch/cable clearances. Diffuser bonded only on its flange, no pressure on original light/buttons. Paper service via rear cover and retaining-bar removal.

Print launch requires user confirmation, consistent with standing instruction; the earlier time-window and specific cradle authorizations do not release this long shell job.

## Shell dispatched with explicit user approval

21 September approximately16:51 local:01_shell_supported sent and device confirmed active heating,805 layers,335.77g,estimated finish22 September01:39. AMS A2 light-grey body/A1 navy logo;Auto Bed Leveling off,timelapse off. Other parts remain unprinted.

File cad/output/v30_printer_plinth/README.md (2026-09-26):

# V30 — matching printer base

The new navy `foot_right_bonded` fills the missing z0–9 mm beneath the exact v28 shell. It shares the left foot's ground plane, 2.5 mm inset and 5 mm lower bevel. The outside corners have an 11.5 mm radius. The v29 rear-hatch correction is retained.

Print `foot_right_navy.stl` as a separate single-colour PLA part, underside flat on the bed. Proposed filament: existing A1 navy PLA. Bounds: 172.5 × 156 × 9 mm. Slicer setup and print approval are still required; no print was launched.

Assembly: dry-fit under the joined enclosure first, front edge aligned and feet on a flat surface. The shell rests on the top lands; five 0.3 mm-deep recessed beds provide room for adhesive. Apply adhesive only within those beds and seat the lands fully against the shell. Do not use thick foam tape that raises the shell. This bonded retention avoids drilling or revising the shell already being printed. Rear withdrawal of the native printer remains available without removing the base.

The switch relief, rear cable channel and inter-bay cable notch remain open through the base. No new screw holes or assumed fasteners have been added. Physical fit and adhesive retention have not yet been tested.

Checks in `audit.json`: one valid watertight solid, common ground plane, every bonding bed backed by the shell floor, zero interference with all existing assembly parts, and zero intrusion into the three relief volumes.

Regenerate: `.venv/bin/python cad/review/build_v30_plinth.py` from the project root. Fusion project `lumon`: `LUMON_v30_MATCHING_BASE_REVIEW`.

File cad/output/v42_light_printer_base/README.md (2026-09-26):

# V42 — lighter printer-base print

## Selected and dispatched

**02_V42_printer_base_lean.3mf / .gcode.3mf** uses the original V39 base shape with3 walls,4 top/bottom layers,10% gyroid and0.2 mm layers. Single navy PLA fromAMS A1, no supports or colour swaps. Outer shape, original bonding pads, switch/cable channels and fit to the accepted printer shell are unchanged.

Started24 September00:57 local. On24 September morning the user reports completion and P1S3DP-01P-994 shows matching job V42_Navy_Printer_Base_Lean Finished,100%,45/45 layers. Estimated2h05m09s,75.89 g; actual finish time not retrieved. Bed leveling/timelapse off. User subsequently confirms the base fits and will glue it later; bonding remains undone. The plate was cleared and V46 display-seat test dispatched at10:39; see that job's record for the latest print state.

| Slice | Material | Time |
|---|---:|---:|
| Original V39 settings |97.50 g|2h48m01s|
| New pocketed CAD, lean settings |89.01 g|2h38m37s|
| **Selected original shape, lean settings** |**75.89 g**|**2h05m09s**|

The selected slice saves21.61 g (22.2%) and42m52s relative to V39. Pockets reduce CAD volume by29.6% but create extra perimeter paths, so they lose the actual print comparison. Do not print01_V42_light_printer_base: it is the rejected pocketed candidate. The internal plate/object names in the selected archive still mention COMPARE_ONLY because that comparison won; the dispatch job was explicitly renamed.

The current whole_enclosure_review.step copies the V41 recessed-glass candidate with the ORIGINAL printer base. whole_enclosure_pocketed_candidate.step and printer_base_local.step/printer_base_print.stl document the unselected pocket experiment. Fusion remains closed/latest savedV39.

## After printing

Dry-fit the base under the accepted printer shell. Its large rear openings must line up with the switch/cable channels and it should sit flat. Keep it unbonded until rear-cover installation and the combined-bay fit are checked. The shallow original adhesive beds remain available for final bonding; no new mounting screws or shell drilling are required.

## Underside feedback — 24 September

The user accepts the printed base's fit but prefers a closed flat bottom. V30 cut conservative rocker, rear-cable and inter-bay clearance volumes completely through the 9 mm base; V38 retained this approach in the longer base used by V39/V42. These are service-clearance openings, not ventilation requirements or a structural need to duplicate every shell-floor aperture.

For the next revision, design a thin continuous underside below internal recesses/channels, with only required rear/side cable exits and service access. Do not fill the channels solid. Check the actual rocker positions, plugged-in cables and rear extraction sweep against the proposed bottom skin rather than treating the old ground-reaching clearance boxes as measured hardware. Closed-floor clearance is not yet validated; no replacement geometry or print has been released. Keep the accepted printed base, with bonding deferred as the user plans.

## Historical V41 display progress (superseded by V45/V46)

V41 exact nominal front-extraction sweeps for glass/chassis/attached Pi passed with rear brackets removed. White recessed seat and visible glass border retained, no navy bezel. Four rear bracket seating and power hardware/layout still need confirmation. The broad cable keepout clashes with an inherited internal-PSU divider, so it has not been silently waived. User asked whether to retain existing external power adapters; answer pending. No display-body print released.

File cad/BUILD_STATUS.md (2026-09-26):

# Current physical build status — 26 September 2026

## Assembled device accepted; software phase started — 26 September

User reports “It's great and it works” after assembling the two bays, including
the translucent PETG insert. The supplied photo shows the assembled device with
the blue indicator illuminated. This supersedes the insert's pending completion,
fit and transmission checks below. No further enclosure print is requested at
this point; the next task is Trello verification and the Lumon terminal UI.
Software deployment and live checks are documented in `../software/README.md`.
Photo reference:
`/tmp/codex-remote-attachments/01a0bf3e-2220-7252-adef-d07f9ff37b1f/0633AA76-1ED7-49BC-8ACD-53273498E6D4/1-Foto-1.jpg`.

## Translucent PETG LED insert — 26 September

User confirms translucent PETG is loaded in AMS slot **3**. Prepared the current
assembly's existing insert, unchanged from the accepted earlier PLA fit trial.
One valid watertight solid, 44 × 8.5 × 3.4 mm in flange-down print orientation,
zero clashes with the current assembly. The saved Fusion assembly already
contains this geometry; no new Fusion document is needed.

Native Bambu slice: **11m30s, 0.61 g, 17 layers at 0.2 mm**, Generic PETG
255 C nozzle / 70 C textured PEI bed, no supports or prime tower. Continuous
first-layer flange and layer 14 short face bridge visually checked. Native
export verifies the PETG preset and temperatures. A3 PETG K0.040 registration
confirmed in Device; project filament 1 must map to physical **A3** at launch.
Prepared project/toolpath: `output/v51_petg_led_insert`.

**Dispatched** after fresh user confirmation that the plate is cleared.
Send dialog mapping verified PETG **A3**, timelapse OFF, auto bed levelling OFF.
Device confirms active preparation of the matching LED job at 0/17 layers,
waiting for heatbed; nozzle target 255 C / bed target 70 C. Estimated finish
22:25 local.
Completion, physical PETG fit and optical transmission are still pending.
After printing,
fit the insert from behind the light opening, flange inside; test the blue light
before small flange adhesive points. PETG optical performance remains untested.

White DC inlet panel is **Finished 100%, 40/40 layers** in Bambu Device.
Removal is confirmed by the user clearing the plate; actual socket/panel fit
is not yet confirmed. This supersedes
older inlet-panel "active preparation" statements below.

## Exposed unused insert hole — next revision feedback, 26 September

User identifies the visible screw-insert hole on the printer-bay edge beside
the display glass as useless and requests removal in a future revision.
Photo reference:
`/tmp/codex-remote-attachments/01a0bf3e-2220-7252-adef-d07f9ff37b1f/491BE101-4384-473F-91DF-DCE7AA8ACD06/1-Foto-1.jpg`.
Omit that exposed unused bore and any associated unused mating feature in the
next revision, leaving a continuous finished surface beside the screen.
Map this photo to the exact CAD bore before editing; do not remove the other
working inter-bay joints or display mounts as a blanket change. Current
printed parts and the active inlet-panel job are unchanged.

## Remaining-print and batching review — 26 September

User is away and cannot clear the build plate between jobs. Bambu Device was
checked again: the V51 navy display base is Finished 100%, 45/45 layers; the
white DC inlet panel was initially prepared but not dispatched. User subsequently
confirms the plate was left cleared and authorizes printing. The inlet panel
was sent to P1S using cotton white A2 with bed levelling and timelapse off;
Device confirms active preparation at 0/40 layers, filament loading and
heating to 55 C bed / 220 C nozzle; estimated finish 17:26 local.
Completion and physical fit remain pending.

There are no other specified, unprinted PLA enclosure parts to add to the
inlet-panel plate. The printer shell/cradle, printer rear cover, both navy
bases, display body, rounded roof and rear hatch have already been printed.
Printed does not mean physically fitted: printer rear-cover fit and display
base fit still need user confirmation. Old loose display brackets and navy
screen bezel are superseded and must not be printed. Inter-bay joining uses
fasteners and the existing rear metal alignment-dowel provision, not a new
printed joining block.

The LED insert was only trial-printed in light-grey PLA (see V25
`led_trial_slice.json`, finished and accepted). The final translucent PETG
insert is prepared with Generic PETG and user-confirmed AMS A3; its printing
and optical check are pending (see current section above). Keep this as a separate PETG job rather than adding it to
the cotton-white PLA inlet panel. Any converter mount or harness restraint
requires the actual selected converter and wiring layout. Future lighter
shells, improved display roof supports and larger glass seat are revision
requests, not additional parts needed for this physical assembly.

## Rear 24 V inlet glue panel — 26 September

User chooses to glue the female DC socket and requests a cylindrical sleeve
extending **5 mm inward** for adhesive contact. Prepared the V51 accessory with
10.2 mm bore for the requested nominal 10 mm neck, 14.2 mm sleeve outer diameter
and 2 mm radial wall. Outer face remains 56 × 37.1 mm, locating shoulder
46.9 × 28 mm, preserving the already printed case. It is one valid watertight
solid with zero CAD assembly clashes. Actual socket neck/body clearance must
be dry-fitted before glue. The separate rear clamp and black-body measurement
request are superseded by the user's glue choice.

Bambu Studio native slice of `02_DC_inlet_glue_panel.3mf`: **20m27s, 5.62 g,
40 layers at 0.2 mm**, cotton-white PolyTerra PLA on project filament 2 / AMS
slot 2. Outside face on bed; no supports/prime tower. First layer and complete
sleeve toolpaths visually checked. Saved native project and exported native
G-code 3MF in `output/v51_dc_inlet_panel`. Stock PolyTerra profile uses 220°C
nozzle, 55°C textured bed and carries the generic PLA chamber/bed heat advisory;
do not alter profile glass-transition fields simply to suppress that warning.
**Dispatched 26 September, approximately 17:05 local, after explicit plate-clear
confirmation.** Cotton white A2, bed levelling and timelapse OFF. Device
confirms active preparation of the inlet panel at 0/40 layers, filament
loading and heating; estimated finish 17:26 local.
Completion and physical socket/panel fit are pending.

Bambu Device reports the navy display base **Finished 100%, 45/45 layers**.
User confirms the plate is clear, so removal is confirmed; base fit is still
unconfirmed. The revised full assembly STEP is
`LUMON_v51_GLUE_DC_INLET_ASSEMBLY.step`. Imported and saved the full assembly
in Fusion project `lumon` as `LUMON_v51_GLUE_DC_INLET_ASSEMBLY`. Confirmed saved
(no asterisk), with only that document left open. V30 review was made read-only
to free one editable slot; it is preserved.

Incoming regulated 5 V can use Pi **physical pin 2**, and incoming ground
**physical pin 9**; the display remains on pin 4 (red 5 V) and pin 6 (black GND).
On a component-side view with the header along the top and USB/Ethernet to the
right, the outside row is even-numbered left to right, and the inside row is odd.
GPIO input bypasses the Pi 3 micro-USB input protection: final protected converter
and secure harness are still pending. No physical power wiring is inferred.

## V51 display-body fit and support feedback — 26 September

The user reports that several of the automatic tree supports inside the upright
white body broke during printing. The roof bridge still printed, but left loose
strands that the user removed. This is a support failure, not evidence that the
body geometry or filament calibration alone is at fault. For the next full body,
replace the current default `tree(auto)` strategy at that roof span with a
stable, deliberately placed support arrangement and inspect its footprint,
branch/trunk stability, interface and bridge layers in Bambu Studio before
printing. Consider a self-supporting roof detail if it preserves the accepted
external shape and roof interface. Do not reuse the V51 support plan unchanged.

The V51 recessed glass seat was too tight in the full body: fitting required
substantial sanding despite the earlier small fit coupons. On the next body
revision, enlarge the seat **2.0 mm overall in width and 2.0 mm overall in
height**, centred on the existing glass/lug datums (nominal current opening
193.6 × 111.4 mm; proposed 195.6 × 113.4 mm, subject to checking the actual
V51 source). Keep the accepted four mounting-hole axes and screw-contact depth.
Retain an effective 3 mm load-bearing ledge under the actual glass perimeter;
do not simply move the inner ledge edge outward with the new pocket. Check
glass retention, visible edge gap, corner profile and front removal with the
real display before another full print. The current sanded white body remains
the physical test part; no reprint is requested now.

The navy base was still printing when this feedback was reported. Bambu now
reports completion; physical fit is not yet confirmed.

The user does the project through the assistant and has done no unreported work.
Keep CAD, sliced, printed, and physically fitted states separate. Update physical
state only from explicit user confirmation or direct evidence; never infer that
an instruction has been carried out.

## Power requirement clarified — one external cable

User confirms **Raspberry Pi 3 Model B**. Printer adapter label is 24 V DC,
1.5 A, 36 W (adapter rating, not measured printer load). Plan: one external
24 V enclosed brick, internal regulated 5 V converter feeding Pi micro-USB,
and a separate 24 V printer branch. The user is willing to reuse the original
printer DC cable/three-contact plug; pinout and polarity still need verification.

Recommended adapter: **Mean Well GST90A24-P1M, 24 V / 3.75 A / 90 W**.
Amazon.de listing https://www.amazon.de/dp/B0131V8XWQ verified 24 September:
IT-Tronics GmbH €32.91 + €8 shipping = €40.91, estimated 30 September–5 October.
Cheapest offer €37.78 delivered, estimated 8–12 October. No purchase made.
C14 mains inlet needs a grounded C13 mains lead; listing only states one adapter.
DC output is 5.5 × 2.5 mm centre-positive barrel, not the printer's connector.
Converter and enclosure DC inlet are still to finalize. See power_architecture.json.

This direction supersedes the old unconfirmed internal LRS supply, IEC inlet
and divider. No electrical connections or full-body release yet. Active V50
roof/rear-panel print remains compatible and unchanged.

## V51 display body preparation — 25 September

Follow-up: user reports the V51 white display body has finished and the plate
is clear. The bottom edge and four roof mounts look intact; user says roof and
rear-hatch fits look fine. No detailed mounted-screen test has been reported.
The navy display base is printing on P1S 3DP-01P-994. The inherited V40
underside-pocket base was rejected after native slice preview (124.03 g,
4h38m, cantilever warning). V51 uses the closed-surface V39 outer profile
with old power-vent slots filled. CAD probes confirm continuous top/bottom
material across the interior and preserve the four fastening holes. Six small
tabs introduced by the slot plugs were trimmed to the chamfered outer profile
before the final slice. The top-face-down plate sliced with no support at
3h23m17s, 114.16 g, 45 layers, 3 walls, 4 top/bottom layers and 8% gyroid.
Bambu Studio reported successfully sent with navy PLA A1, timelapse off and
auto bed levelling off; Device subsequently showed active printing at 6%,
layer 1/45, with nozzle and bed at printing temperature. Completion and
physical fit are pending. After it cools, check the closed underside/edge,
dry-fit it to the white body and compare the back edge with the printer bay
base before any permanent assembly.

V50 rounded white roof and 132 × 94 mm white rear hatch completed. Bambu shows
Finished 114/114; user confirms both intact and build plate clear. They do not
assemble until the full display bay body is printed. Roof fastens from above;
rear hatch closes the lower rear service opening. Remove supports gently and
store both parts. No need for glue.

V51 CAD preserves the accepted V49 glass/metal-lug seat and V50 printed mating
interfaces. Removed old open-frame internal AC PSU divider/corner blocks and
unneeded Pi-on-side-wall standoffs; closed old floor/base cooling slots. The
old rear connector recess is retained as a modular low-voltage inlet site,
with an independent blank/pilot insert until the exact connector is selected.
Single-solid watertight STL; body front-down bounds 218.96 × 231.33 × 164.17 mm.
Bambu's selected upright, base-down plate is
`output/v51_external_power_body/02_V51_display_body_upright.3mf`.
Native tree-support slice: 20h2m, 562.20 g total (457.69 g model),
3 walls, 4 top/bottom layers, 8% gyroid, 0.12 mm support gap.
Sent to P1S 3DP-01P-994 using cotton white A2 with timelapse and auto bed
levelling off after user confirmed the roof/hatch intact and plate clear.
Bambu showed an active 0/880-layer job, cleaning nozzle tip, estimated finish
20:59 local. User subsequently confirmed this body completed, bottom and roof
mounts intact, roof and rear hatch fit, and plate clear. The corrected V51
whole-assembly STEP was uploaded to the existing Fusion `lumon` project as
`LUMON_v51_EXTERNAL_POWER_ASSEMBLY`; it appeared in the project search and
opened as a solid-design assembly. Fusion is a review copy of the generated
CAD; the project STEP remains the source for further geometry edits.

Navy display base print plate is
`output/v51_external_power_body/04_V51_closed_display_base_top_down.3mf`.
The old internal-PSU ventilation slots are closed in this version. Earlier
`03_V51_closed_display_base.3mf` is the alternate bottom-down comparison,
not the print job sent to the P1S.

User proposed Amazon Prime GPJYD 24 V / 3 A / 72 W adapter; its rating fits the
provisional power budget, but purchase/physical loaded performance are unconfirmed.
Pi needs a separate regulated 5 V converter. See power_architecture.json.

## V50 display roof and rear panel print record — 24 September

User confirms the plate is clear after V49. Sent the prepared roof and rear
panel together as V50_Display_Roof_and_Rear_Panel to P1S3DP-01P-994.
Cotton whiteA2, bed levellingOFF, timelapseOFF verified.114 heights,
3h53m40s,118.64g, no inter-colour swaps. Device later showed Finished 114/114; user confirms both pieces intact and
plate clear on 25 September. Output: v50_full_display_preflight.

The full display body/base remain unprinted. The power direction is now a
shared external 24 V supply (see above); internal converter/inlet geometry
still needs integration. Display fit tests are accepted.

## Current — V49 physical tests accepted, full bay preparation

User confirms BOTH V49 corner samples seat without bending and their 4 mm
screws reach/tighten gently. User measured the mixed samples and identifies
**0.12 mm support top gap as better**. Select that gap for supported display
bearing features. No further full-frame fit test is needed before preparing
the full display bay. The four-hole XY pattern was separately confirmed on
the earlier full-frame test; V49 tests one revised corner twice.

Full display body, roof, rear hatch and left navy base remain unprinted.
Printer shell/cradle and navy printer base fit are accepted. Printer rear
cover was printed; physical fit has not been reported. Preserve accepted
printer geometry. Power architecture is awaiting clarification: old CAD has
an unconfirmed internal PSU/divider and an interfering cable keep-out.
Full-body orientation/access and final slices still need review. Fusion V39.
Fresh plate clearance after V49 has not yet been reported.

## Full-case preflight — 24 September, after V49 acceptance

- Full body front-down bounds218.96×231.33×164.17 mm; sloped front face
  reaches the bed. Mesh watertight. Full-body slice remains outstanding.
- Four display screws have room for a compact driver envelope:55 mm shaft,
  Ø5.5 mm, plus45 mm long/Ø25 mm handle, with roof removed. Straight long
  insertion from outside the rear is obstructed at three screw axes. Use roof
  access before routing wires; exact user's screwdriver has not been measured.
- Existing rounded roof and rear hatch prepared together, sliced and previewed
  in Bambu: **3h53m40s,118.64g,whiteA2 only,114 heights**,3walls,4top/bottom,
  10%gyroid,0.12supportgap. Geometry matches savedV39. Only0.78g non-model.
  Project/toolpath in output/v50_full_display_preflight; NOT DISPATCHED.
- Awaiting user choice: existing external adapters vs specified internal PSU.
  Old divider occupies237.48mm³ of provisional Pi rear cable space; do not
  carry unconfirmed power hardware into the final full-body print.
- Fresh plate-clear question sent for roof/hatch; no answer yet. No new print.
- Remaining full body/base need power/cable and ventilation finalization;
  provide closed-looking lean left base without obstructing needed air paths.

## V49 measured bracket-depth correction — 24 September

V48 completed (Device Finished100%,121/121 and user assembly photo), but the
arms bend while seating the display and the short screws do not reach. User
measures glass FRONT to flat metal mounting face **8.4 mm**, and screws **4 mm
under the head**; heads fit the existing counterbores.

- V49 relieves all four contact pads **2.44 mm**, local y6.96 to y9.40.
- Plastic grip under screw head is **2.0 mm**, reduced from3.9; head-seat y11.40.
  The actual4 mm screws protrude2 mm nominally. Do not substitute M3x6.
- Original XY hole positions, arm roots, pocket193.6x111.4/R8.2 and3 mm ledge
  preserved; contact depth changes only. CAD single-body, watertight, bearing,
  screw passage, unchanged-region and conservative insertion checks pass.
- Return to front-face-down orientation at user request. Two small identical
  upper-right corner coupons compare support gap0.20 vs0.12 mm and test depth/
  screw reach. Full-frame geometry also updated, but no full-frame reprint queued.
- V49 small plate sliced/reviewed:50m14s,14.30 g,whiteA2 only,no colour swaps.
  Per-object0.20/0.12 gaps verified in saved project and toolpath.
- User now confirms plate clear. Sent the two V49 coupons using whiteA2,
  bed leveling/timelapseOFF. P1S shows matchingV49 job active0/152,startup,
  ETA18:14 local. First layer, completion and physical outcome pending.
  CAD: output/v49_measured_display_depth. Fusion stays savedV39; not synced.
- Earlier2.5 mm maximum-thread-depth claim is not explicitly verified in the
  manufacturer drawing. Do not force a screw that stops before its head seats.
- Full display case still needs cable/power and full-body print/access review.

## Historical quality feedback — V48 during printing

- User photo shows continuing loose/frayed strands on the opposite side of
  the flipped frame. Orientation change is not a validated surface-quality fix.
- Device checked at58%, layer103/121,1h16m remaining, ETA16:13. Exposed infill
  and unfinished top surfaces cannot yet be judged as final finish.
- Actual support Z gap remains0.2 mm; denser3-layer/0.15 mm interface was used.
  Support contact is a plausible cause; filament calibration is not established
  as the cause from this photo. Original mounts remain unchanged/confirmed.
- Before final-case printing: inspect completed bearing and reverse faces, then
  validate contact gap/finish with a SMALL representative coupon and reference
  surface; review effective filament profile if ordinary surfaces also fail.
  Prefer orientation avoiding support contact on visible/bearing surfaces.
  No calibration job sent; existing print unchanged. Details:
  output/v48_display_original_mounts/PRINT_QUALITY_FEEDBACK.md.

## Latest correction — preserve original mount holes, V48

- User corrected display assembly orientation and confirms original holes match.
  DO NOT apply the earlier rear-view right3.6/down2 mm shift. V47 is superseded
  and was never printed; its project/toolpath are marked DO_NOT_PRINT.
- V48 retains the exact V45/V46 arms, pads, bores and counterbores. Only widen
  the pocket0.2 mm overall and retain the improved rear-down test orientation.
- Original hole alignment physically confirmed. Bearing surface quality and
  simultaneous glass/metal-lug seating are not yet accepted.
- V48 CAD checks passed, including zero mount-geometry difference fromV45.
  GUI project and toolpath saved/reviewed: 11098s, 63.32g,121 preview heights.
  User now authorizes printing and confirms plate clear. Sent V48 test to
  P1S3DP-01P-994, cotton whiteA2; leveling/timelapseOFF verified. Device
  confirms matching job active0/121, heating/loading, ETA16:15 local. Camera
  live; first layer/completion not yet verified. FusionV39.

## Historical, superseded mount shift — V46 correction to V47, 24 September

- V46 completed, confirmed by user photos and Bambu Finished100%,114/114.
- Glass almost fits; one corner tight. Increase pocket total width by0.2 mm,
  centred (+0.1 per side), to193.6×111.4 mm; R8.2 and height retained.
- Shift entire four-lug pattern and pads right3.6 mm/down2 mm viewed from rear.
  In front-based local CAD coordinates this is X−3.6/Z−2.0. Pitch unchanged.
- Loose strands/poor attachment visible along inner ledge. Do not accept the
  bearing surface or simultaneous glass/metal-lug contact as validated.
- V47 updates production tub and extracts a matching fit frame. CAD passes
  single-solid/watertight, full3 mm bearing, corrected bores/lands, nominal
  front insertion sweeps, and unchanged geometry outside interface regions.
- Revised fixture prints rear down, seat and lug lands upward. Denser three-layer
  same-PLA support interface underneath non-contact reverse faces. WhiteA2 only.
  GUI slice/preview passed:3h04m01s,63.31g,121 preview layer heights. Saved
  project/toolpath. Fresh plate-clear question pending; no dispatch yet.
- Full display enclosure not released. Actual metal/Pi offsets not inferred
  from lug-only measurement; power/cable layout and full-case access unresolved.
  Fusion remains closed/latestV39. See output/v47_display_fit_correction.

## Latest display requirement — V45 3 mm bearing seat, 24 September

- User requests 3 mm inward bearing width instead of 2 mm and explicitly
  confirms the black band clears the outermost 3 mm rear glass border.
- Widen ledge through its full 2.3 mm material thickness. Keep measured
  0.8 mm glass, 1 mm recess, accepted opening and four integral retention arms.
  No notch, front lip, soft gasket or separate navy bezel required.
- Selected candidate: output/v45_display_seat_3mm/glass_0p8. V44 2 mm geometry
  is historical. Nominal chassis clearance at lower glass border is only
  0.35 mm; actual ledge/metal-lug stack still needs a physical fit check.
- CAD passed: single valid watertight body, full-width/full-depth ledge,
  nominal hardware clearances, front sweeps with fixed arms, screw passages,
  and conservative band clearance. Bearing contact area is 1754.52 mm².
- Full-case power/cable routing, screw access and slicing remain pending;
  no display-body print released. Printer parts/job unchanged; Fusion V39.

## Completed test — V46 integral display-seat fit frame, 24 September10:39

- Exact V45 seat and four integral arms cropped into one small test frame;
  no loose brackets/case inserts. CAD interface, front passage and mesh checks
  pass. Same-colour normal supports required under ledge and mounting arms.
- GUI slice/export reviewed:2h02m04s,47.29 g (39.11 g model,8.17 g supports),
  A2 cotton white only,114 preview layer heights, no inter-colour swaps.
  3 walls/4 top-bottom layers/10% gyroid. Project/toolpath saved in
  output/v46_display_seat_fit.
- User now explicitly confirms plate clear. Sent toP1S3DP-01P-994 as
  V46_Display_3mm_Seat_Integral_Mount_Test. A2 white mapping and bed leveling/
  timelapse OFF verified before Send. Device confirms matching job active at
  0/114, waiting for heatbed55 C, nozzle220 C; estimated finish12:41 local.
  Camera enabled. Completion subsequently verified; physical test issues above.
- After print, remove supports; fit glass/Pi from front with no screws and
  check even seat plus all four lug-pad contacts, then gently secure M3×6.

## Previous display requirement — V44 bearing seat, 24 September

- User measures glass mostly 0.8 mm, with a local black band measuring 1.3 mm
  total, and confirms the band does not reach the outermost 2 mm rear border.
  Select glass_0p8 seat y1.8 for glass-front y1.0; no seat notch required.
  The 2 mm dimension is bearing width underneath glass, not padding thickness.
  The rigid integral ledge is 2.3 mm thick; there is no soft gasket/front lip.
- User explicitly requires the recessed seat to support the glass and prevent
  inward movement without screws. Four rear screws prevent front withdrawal;
  four support arms stay integral with the case. No separate bezel/front lip.
- V41/V43 left 0.4–0.8 mm behind the glass and did not meet this requirement.
  V44 raises the continuous 2 mm bearing ring to the nominal glass-back plane.
  Accepted 193.4×111.4 mm/R8.2 opening and 1 mm recess are preserved.
- Two older nominal variants (0.7 and 1.1 mm) remain as references. The new
  glass_0p8 baseline uses the user's measurement. A conservative interior band
  envelope checks seat clearance; exact band geometry remains unknown.
  Seat geometry selected; full case not released for printing. Keep glass and rear lug
  bearing planes matched; never tighten across a lug gap.
- The measured 0.8 mm baseline and both reference variants pass valid single-body/watertight checks, all four-side bearing
  checks, glass-alone inward stop/outward clearance, and nominal front sweeps
  with integral arms in place. This verifies geometry, not physical strength
  or a physical assembly test.
- Existing V40 contour test does not validate the new seat or metal lug stack.
  Full-body power/cable, screw access and printability checks remain pending.
  Printer geometry/job unchanged; Fusion remains V39. See output/v44_bearing_seat.

## Previous display candidate — V43 integral mounts,24 September

- User proposes case-integrated mount arms because the display/Pi inserts from
  front. Implemented four integral arms, four M3×6 rear screws into metal lugs.
  Removed four separate brackets, four M3×8 case screws and four case inserts.
- White recessed seat, accepted outline/R8.2 corners and1 mm recess unchanged.
  No navy bezel/front lip. Metal pad depth and screw engagement unchanged.
- Revised body single valid/watertight solid. Four bores/head recesses/lands
  pass. Exact nominal front insertion/extraction sweeps pass with integral arms
  LEFT IN PLACE. Nominal Pi margin and component clearances pass.
- Existing V40 frame/brackets still verify hole pattern and metal bearing depth;
  only glass contour is physically confirmed. Do not require final separate
  brackets after adopting V43. Fixed-arm full-body orientation/support review,
  screwdriver/cable access, and real power architecture remain unverified.
- Cable/divider conflict237.48 mm³ retained. No full-body print released.
  Active navy base unchanged. Fusion closed/latestV39. See output/v43_integral_display_mounts.

## Completed print — navy printer base, verified 24 September morning

- User reports the previous print completed. Bambu Device confirms matching
  V42_Navy_Printer_Base_Lean, 100%, 45/45 Finished. User now explicitly confirms
  the base fits and will glue it later. Bonding remains undone.
- User dislikes the open underside and wants a closed flat bottom. The original
  conservative switch/cable clearance cuts extended through the full base.
  Next revision: thin bottom skin, internal clearance recesses and necessary
  rear/side exits; validate rocker travel, cables and printer extraction first.
  This is recorded design feedback, not a released CAD change. Keep this base.
- User subsequently cleared the plate; V46 was dispatched at10:39 as above.

- User said go on and then explicitly confirmed all five display-test pieces
  were removed and the plate completely clear.
- Compared original V39 slice97.50 g/2h48m01s, pocketed CAD89.01 g/2h38m37s,
  and original shape with lean settings75.89 g/2h05m09s. Selected the last:
 22.2% less filament and42m52s faster than V39, with intact outer/bond surfaces.
- Dispatched02_V42_printer_base_lean toP1S3DP-01P-994. Device shows job
  V42_Navy_Printer_Base_Lean, heating0/45 layers, estimated finish03:02.
  NavyA1 only; no supports/colour swaps; bed leveling/timelapseOFF.
  Completion and physical fit now verified as above. See output/v42_light_printer_base.
- Pocketed candidate NOT selected. Current V42 review STEP retains the V41
  assembly with original printer-base geometry; no Fusion changes.
- V41 exact nominal front-service sweeps pass after bracket removal.
  Full display print waits for rear bracket seating confirmation and actual
  power/cable plan. Asked user about retaining existing external adapters;
  answer pending. Fusion remains closed/latestV39.

## Latest physical feedback — 24 September, V40 display frame

- User reports perfect fit and supplies a photo of the full-outline frame on the
  real glass. Preserve the193.4×111.4 mm opening withR8.2 corners as physically
  accepted. The exact glass radius itself remains inferred, not measured.
- Printed frame completion confirmed. Four rear bracket seating/alignment,
  fastener stack and retention are NOT yet confirmed; clarification requested.
- User explicitly corrects the appearance: **no separate navy bezel and no lip
  over the glass**. The existing black glass border stays visible, fitted into a
  recessed seat in the white sloped front. The assistant's preceding overlap
  interpretation was wrong and is superseded.
- Preserve the accepted pocket contour and the rear metal-lug support. Fill
  the obsolete decorative bezel rebate into the white panel and provide a
  shallow step behind the glass, without a front clamp.
- V41 candidate generated and visually checked: integrated white seat,
  glass recessed1 mm, no front overlap and no separate display_bezel component.
  Body is valid/watertight; checked part pairs and nominal hardware clear.
- Printed bracket shapes unchanged; entire glass/anchor stack moves2 mm
  rearwards together. Rear screws release the screen for extraction from front.
- No new print dispatched. Rear bracket fit remains unconfirmed; provisional
  cable keepout still overlaps divider237.48 mm³. Full-body release held.
  Fusion remains atV39. See output/v41_recessed_glass/{README.md,audit.json}.

## V40 display fit kit — 23 September evening

- User confirms attached display/Pi depth **40 mm**; glass **193 × 111 mm**.
  No outstanding glass or total-depth measurement request.
- User wants the glass to fit precisely into the frame. Candidate opening is
  **193.4 × 111.4 mm**, 0.2 mm nominal per-side gap, R8.2 from provisional R8
  glass. Physical fit test determines the final curve and allowance.
- Small five-part kit: full-outline frame and four separate metal-lug brackets.
  Geometry, connected solids, watertight meshes, assembled pair collisions,
  glass clearance, and print orientations passed independent fit-kit audit.
- Candidate V40 removes obsolete separate Pi standoffs and generic retainer.
  Large display bay remains on hold: rear cable allowance intersects the old
  divider; resolve routing/actual power layout after the mechanical fit test.
- Candidate display foot has 44.3% less CAD solid volume; this is not a sliced
  filament-saving claim or a stiffness validation.
- User stopped work to close Fusion because Mac performance suffered, then
  authorized resuming and printing while clearing the bed. Keep Fusion closed
  for now; V40 has NOT been imported/saved there. V39 remains latest Fusion.
- User brought Bambu forward; GUI controls recovered. Fit kit sliced, saved,
  visually reviewed and dispatched at **21:39 local** to P1S 3DP-01P-994.
  Matching job verified active/heating at **0/60 layers**, estimated finish22:50.
- **1h11m26s,26.74g,60layers**; A2 cotton-white PLA only, no supports or colour
  swaps.3 walls,4 top/bottom layers,0.8 mm top minimum,10% gyroid,0.2 mm layers.
  Bed leveling and timelapse OFF. First layer/completion/physical fit unverified.
  See output/v40_display_mount/{slice_review,print_dispatch}.json.
- Earlier CLI slicing attempts failed; the saved GUI slice/export is authoritative.

## Display hardware update — 23 September

- New photos show Pi attached directly to display; four outer metal mounting
  lugs available. User confirms loose wire plugs only, not broken pins.
- Revise the display mount around metal lugs and measured spacer stack;
  glass must not be squeezed against a rigid lip. Keep25-degree facade.
- Existing21 mm display box and separate Pi mounts are unverified placeholders
  inconsistent with the complete photographed assembly; V39 display-side
  slices remain review-only. Current printer rear-cover print unaffected.
- User measured glass **193 × 111 mm**. Official drawing has no corner-radius
  callout; scaled vector outline suggests ~7.9 mm, so provisional reference R8.
  Allow clearance/corner relief and verify a small fit test; no tight glass clamp.
- Full assembly depth subsequently confirmed as40 mm; superseded by V40 fit
  kit above. See DISPLAY_MOUNT_REVISION.md and display_hardware.json.

## New design requirement — reduce enclosure weight

- User finds the printed shell too heavy; balance stiffness with material use.
- Audited actual G-code: shell ~593 g model; inner+outer wall paths~415 g,
  sparse infill~73 g. Existing broad panels3–4 mm; inter-bay wall9 mm.
- Future candidate:2.4 mm general skins, local ribs/bosses, preserve bearing
  surfaces and insert engagement;3 loops/4 skins/8–10% gyroid as a starting
  point requiring reslicing and stiffness/retention checks.
- Review remaining unprinted bases/display parts for weight before release.
  Current cover continues; existing shell accepted. Detailed measured evidence
  and candidate criteria in output/v39_aligned_rear/NEXT_REVISION.md and
  weight_audit.json. No lightweight geometry or revised print yet released.

## Completed print — V39 integrated rear cover (23 September)

- User authorized next part and confirmed bed clear after shell removal.
- Dispatched 02_V39_printer_rear_cover.gcode.3mf to P1S 3DP-01P-994.
  Device directly verified Finished,100%,231/231 layers before V40 dispatch
  at21:39 local. Physical cover fit remains unverified.
- Cotton white A2 only; auto bed leveling and timelapse OFF.
- Estimate4h04m51s,140.90g,231layers. Completion verified in Device.
  See output/v39_aligned_rear/rear_cover_print_dispatch.json.

## Latest physical confirmation — V39 shell, 23 September

- Shell finished (P1S 805/805); user supplied photos and removed the part.
- Existing V31 yellow cradle fits perfectly in this shell; printer fits perfectly
  on it inside the shell, explicitly confirmed by user.
- User accepts current shell; requests a flush lower band for next revision.
  Existing 0.8 mm decorative exterior inset causes the step and front-down
  support strip. See output/v39_aligned_rear/NEXT_REVISION.md.
- User authorizes next compatible rear-cover print and confirms bed clear.
  Rear cover, navy foot and secured closure remain untested.

## Latest check — 23 September afternoon

- P1S reports shell printing at 96%, 785/805 layers, 37 minutes remaining;
  estimated finish 16:19 local. Completion and fit are not yet confirmed.
- Next physical step: cool, remove supports/brim, dry-fit existing V31 yellow
  cradle and printer into new shell; check raised outlet, LED, switch/cables.
- Next prepared print is integrated white rear retaining cover (4h04m51s),
  then navy printer base (2h48m01s). Cover replaces old separate bars.
- Await actual shell condition and clear plate before another dispatch.

## Active print — V39 printer shell (22 September, 21:45 local)

- User explicitly authorized printing and confirmed the build plate is ready.
- Sent 01_V39_printer_shell.gcode.3mf to P1S 3DP-01P-994; Bambu confirms
  successful send. Device shows the matching job, 0/805 layers, heating.
  Estimated finish 23 September at 16:15 local.
- A1 navy / A2 cotton white; auto bed leveling and timelapse OFF.
- Estimate 18h30m54s, 634.49g, 805 layers. Only this shell dispatched.
- First-layer quality and completion not yet verified. See
  output/v39_aligned_rear/print_dispatch.json. Earlier bed-clear hold resolved.

## Current actionable state — V39 (22 September evening)

- Rear-depth mismatch fixed. Both assembled rear facesY170.75; both basesY168.25.
  Display rear extended9.75mm; matching9.5mm rear corner/7mm base radius.
- Front throughY135 exactly unchanged;25-degree display retained. Pi/PSU fixed.
  Rear hatch/IEC recess/roof skirt and rear mounts updated together. CAD audit
  passes, including clashes, vents, mounts and printer rear removal.
- Fusion saved and verified as LUMON_v39_ALIGNED_REAR at19:38;10/10 editable docs.
- Four revised display-side plates sliced plus three unchanged printer-side
  slices reused with byte-identity checks. All in output/v39_aligned_rear.
  See README.md,plate_manifest.json,slice_review.json. Shell dispatched as above.
- Next job01_V39_printer_shell.gcode.3mf:18h30m54s,634.49g,805layers,6changes.
  Embedded name stillV38 because toolpath is unchanged. WhiteA2/navyA1.
  Bambu Send succeeded for this V39-named file; A1 navy/A2 white and
  bed leveling/timelapse OFF verified.
- Display body19h07m34s,roof3h02m,hatch54m30s,navy base4h38m.
  Seven plates total1528.76g white+259.86g navy(excludes unchanged trim/retainer).
- Older rear-depth design hold and build-plate clearance hold are resolved.
  User confirmed the plate is ready after removal request; shell dispatched.
- Left actual electronics fit unverified. Printer prototype retention/feed passed;
  new integrated rear cover/outer holes still await physical trial.

## Rear alignment review — PRINT HOLD (supersedes launch readiness below)

User identifies mismatched assembled depths in Fusion. Verified actual V38 STEP:
left rear wall/hatch/roofY161.00, printer rear coverY170.75:9.75mm step.
Left navy base endsY158.50 versus rightY168.25:also9.75mm step.
Bambu Send dialog closed without sending. Nothing started. Even a reply to the
older bed-clear question does not release this design hold.
Recommended correction: extend display-side rear envelope/roof/base to common
Y170.75 while preserving tested printer installation and25degree display front.
Dependent rear hatch/vents/IEC/roof/base mounts must be revised together. Left
Pi/PSU placements are depth-derived if regenerated and need corresponding checks.
Geometry has NOT been changed yet; this turn establishes the mismatch and cause.
See output/v38_integrated_rear/rear_alignment_review.json.

## Latest actionable state — V38 (22 September, approximately 17:49)

- Full assembly saved in Fusion as LUMON_v38_INTEGRATED_REAR (17:19 save,
  no unsaved marker, 9/10 editable documents). App-control connection recovered.
  User confirms Fusion and Bambu look fine and says proceed.
- Rear closure: flat shell lands, rounded single cover with integral retaining
  ribs/capture lips, four M3x14 screws, matching navy base. CAD audit passes.
- ALL THREE printer-bay plates sliced and exported in output/v38_integrated_rear:
  - SELECTED shell: V38_final_shell_tree.gcode.3mf, 18h30m54s, 634.49g,
    805 layers. A2 white631.72g, A1 navy2.77g. Colours coexist only layers1–4;
    six changes total. Tree supports39.54g save46.77g and1h20m53s over normal.
  - Cover: V38_rear_cover.gcode.3mf, 4h04m51s,140.90g white,231layers,
    single colour,1.33g removable support.
  - Base: V38_navy_base.gcode.3mf,2h48m01s,97.50g navy,45layers,
    single colour,no supports.
- All slices within build volume, correct P1S0.4/texturedPEI, effective G-code
  flow0.98/maxvol22/nozzle220/bed55 for the selected PLA. Native metadata
  includes per-nozzle arrays; use effective G-code settings when auditing.
- Bambu Send print job dialog OPEN for V38_final_shell_tree:634.49g/18h31m,
  P1S3DP-01P-994,navyA1/whiteA2,TimelapseOFF,AutoBedLevelingOFF verified.
  SEND NOT CLICKED. User already authorizes printing; only missing info is a
  completely clear build plate. Async question pending. Camera shows only part
  of low-positioned bed, so clearance could not be verified from it.
- Current send-dialog screenshot is700x688 with Send centre[631,644]. Refresh
  screenshot before acting. Prior V37 coordinate-mismatch rejection is historical;
  do not reuse old ungrounded coordinates.
- V37 shell G-code and V38_final_shell.gcode.3mf(normal supports) are superseded.
  Selected editable project:01_V38_shell_reviewed.3mf or tree_supports project.
- Physical prototype V28+V31 retention and feed/tear passed; new cover/outer
  screw positions not physically tested yet. Left electronics hardware fit is
  unverified; no left-bay final print released.
- Final PLA:PolyTerra CottonWhiteA2;Bambu NavyBlueA1. No V38 part dispatched.

## Confirmed (historical ledger follows)

- V28 integrated-top printer shell finished. Grey PLA ran out and the user
  continued with yellow; this shell is a mechanical prototype.
- V31 revised cradle and both retaining bars are now printed in yellow PLA.
  User reports the assembled fit is perfectly fine and provides a rear photo
  showing the printer seated and bars offered up. Screws are not installed in
  the visible holes; secured retention, outlet/LED alignment and functional
  feeding/cabling/service checks remain unconfirmed.
- User previously tested the printer in the intended upper-outlet orientation.

## Prepared, not physically completed

- V35 is the latest desktop-terminal study: display and surround at 25 degrees,
  saved in Fusion as `LUMON_v35_DESKTOP_TERMINAL_25DEG`. Printer side unchanged.
  See `output/v35_desktop_terminal/README.md`. Five joint screws and rear dowel
  remain; omit the former front dowel at y35,z118 for this angle. Current CAD
  references clear, but actual hardware remains unverified (buck gap 1.29 mm).
- V34 is the retained 14-degree exterior alternative, saved in Fusion as
  `LUMON_v34_SLOPED_CONNECTED_ROOF`. The user rejected V33's vertical display
  facade: preserve the original sloping face around the screen. V34 restores
  it and the original bezel, connects the flat roofs without a rounded valley
  at the seam, matches exposed front roof rounding and retains the common
  lower band. See `output/v34_sloped_connected_roof/README.md`.
- V33 unified-body study is geometry-checked and saved in Fusion as
  `LUMON_v33_UNIFIED_BODY_STUDY` in `lumon`. It shares the lower band and
  rounded front roof across both bays, recesses the tilted screen inside a
  common upright body, and moves the left lid joint behind the front brow.
  REJECTED by the user; retain only for reference. No new print is released/dispatched.
- V32 equal-height study is modelled and geometry-checked: both bays 201 mm
  tall, display centre 10 mm higher, bases on the same ground plane. See
  `output/v32_equal_height/README.md`. This is not a left-bay print release.
  User confirms they set older Fusion versions read-only and saved V32.
  Local STEP and previews are also saved. The previous save blocker is resolved.
- V31 revised cradle plus two retaining bars are sliced in Bambu Studio:
  3 h 6 m 28 s, 108.54 g PLA, 212 layers, one colour.
- Source/review: `output/v31_cradle_retention/README.md` and
  `output/v31_cradle_retention/slice_review.json`.
- Native project: `output/v31_cradle_retention/02_cradle_and_bars_reviewed.3mf`.
- Sliced plate: `output/v31_cradle_retention/02_cradle_and_bars_reviewed.gcode.3mf`.
- Fusion review saved as `LUMON_v31_CRADLE_RETENTION_REVIEW` in `lumon`.
- Inserts, bars, full printer installation, cable routing, paper feeding/cutting
  through this shell, and rear-service test are not confirmed complete.
- Right navy base and final shape refinements are not physically fitted.

## Next action

User authorizes test prints and confirms AMS slot 2 now contains yellow Generic
PLA. The send dialog maps PLA to A2; bed leveling and timelapse are off.
User clicked Send after CUA controls failed. Dispatch VERIFIED in Bambu Studio:
V31 cradle and retaining bars, 0/212 layers, heating bed to 55 C, estimated
finish 15:32. AMS A2 yellow Generic PLA; bed leveling and timelapse off.
Physical completion and fit remain unconfirmed.
Final enclosure prints wait for final filaments. Preserve these settings at launch.
If a different material/profile is selected, reslice and report any material
change to duration before dispatch.

After the kit finishes, guide the user through physical assembly one step at a
time. Do not ask them to manage Fusion, Bambu Studio, exports, or CAD files while
the assistant can do those steps. Retain the shell for mechanical checks; defer
the final-colour shell until fit and the revised appearance are approved.

The earlier Bambu app-control timeout is resolved. The project generator's
process-override metadata was corrected and the saved native settings and
exported G-code were verified.

Latest physical update: user reports V31 fit successful; photo is consistent
with lower capture bar at bottom and plain upper bar above. Hidden retaining
lip engagement cannot be established from this rear view. Next check is front
outlet/LED alignment with the printer fully seated, then secured/functional tests.

## V36 outlet correction from physical assembly

User confirms LED alignment acceptable and paper opening usable, requests opening
3 mm upward with revised cradle seated. Applied in V36 to V35 shell only:
90 x 14 mm aperture centre Z133.1 (previous130.1); LED/cradle unchanged.
Validated single-solid/watertight shell and opening clearance. STEP exported to
output/v36_outlet_alignment/whole_enclosure_review.step. Fusion import pending;
no new print. Current prototype remains usable for functional checks.

## V37 logo spacing and filament arrival

User reports final filaments arrived; brand/material/colour and loaded AMS slots
asked, not yet confirmed. V37 moves N right 0.3 mm, increasing O–N gap from
0.294 to 0.594 mm. Matching shell recess updated; V36 outlet correction preserved.
Shell and logo validated and exported; Fusion synchronization pending. No print.
Latest CAD: output/v37_logo_spacing/whole_enclosure_review.step.

## Confirmed assembly tests and final materials

User confirms BOTH secured retention and paper feed/tear through prototype pass.
PolyTerra Cotton White PLA is loaded in AMS slot 2, replacing yellow; existing
Bambu Navy Blue PLA remains in slot 1. These supersede earlier pending checks
and material questions. Rear withdrawal/roll service and rear cover remain
unconfirmed; left-bay hardware fit remains unverified. Final slicing preparation
is authorized; ask before dispatching a final print (standing instruction).

## Final shell slice ready; dispatch blocked

User explicitly authorizes proceeding, including final printing. V37 packed and
sliced in Bambu Studio using PolyTerra PLA @BBL X1C for A2 cotton white and
existing Bambu PLA Matte for A1 navy. 60924 seconds (16h55m24s),592.31g total:
589.79g white,2.51g navy;805 layers. Both colours only layers0–3;6 changes.
Support used; outside=false; standard bed-temperature metadata warning remains.
Send dialog verifies A1/A2 mapping, bed leveling/timelapse off. NOT dispatched:
automatic approval review rejected click due screenshot/coordinate mismatch.
Do not retry uncertain coordinates. Fusion V37 import also remains pending;
its native path dialog fails to resolve entered path. Local STEP correct.
Sliced file output/v37_logo_spacing/V37_final_shell.gcode.3mf.

## Rear closure review — hold final shell

User requests Fusion view and questions separate bars/cover and mismatch at
rounded rear outer corner. Source confirms V33 rounded shell but explicitly
retained square bars/cover. V37 shell slice is ON HOLD pending correction of
rear closure and mounting seating. Do not dispatch this stale slice.
Proposed final direction: one removable rear cover with integrated retaining
ribs and cradle capture; match exposed corner profile and check screw lands.

Fusion synchronization recovered: full V37 assembly imported and saved in lumon
as LUMON_v37_REAR_REVIEW. A second local inspection tab V37_REAR_INSPECTION is
open and visibly shows the rear with cover pulled out85mm and retaining bars
coloured navy for distinction. Inspection coordinates are rotated for viewing,
not print/assembly release; tab not cloud-saved. Current design flaws retained
for review, not presented as fixed. No rear geometry redesign performed yet.

## V38 rear closure redesign

User chooses straight rear shell edges and rounded removable panel. V38 built:
square rear lands, one rounded cover with integrated retaining ribs/capture,
four M3x14 screws with outer axes moved inward9.5mm, matching extended navybase.
Closed depth170.75mm (old170.5), cosmetic seam0.25, outerrear radius9.5.
Cradle/printer/front aperture/LED/logo unchanged. Geometry and removal/retention
checks pass. New cover does not use the old prototype's outer screw axes.
V37 sliced shell SUPERSEDED—do not send. V38 not yet sliced or printed.
Latest CAD: output/v38_integrated_rear/whole_enclosure_review.step.

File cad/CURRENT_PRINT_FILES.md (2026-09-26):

# Parts used in the accepted prototype

The user accepted the assembled device on 26 September 2026. Its parts come
from several revisions; old fit coupons, superseded display brackets and navy
screen bezels are preserved in the archive but are not part of this build.

| Part | Existing print project / geometry |
| --- | --- |
| Printer shell with navy logo | [V39 printer shell](output/v39_aligned_rear/01_V39_printer_shell.3mf) |
| Printer cradle | [V31 reviewed cradle plate](output/v31_cradle_retention/02_cradle_and_bars_reviewed.3mf); [cradle STL](output/v31_cradle_retention/cradle_tray.stl) |
| Printer rear cover and integrated retention | [V39 rear cover](output/v39_aligned_rear/02_V39_printer_rear_cover.3mf) |
| Navy printer base | [V42 selected lean base](output/v42_light_printer_base/02_V42_printer_base_lean.3mf), retaining the original V39 shape; the pocketed V42 candidate was rejected. |
| Display body with recessed glass seat | [V51 upright display body](output/v51_external_power_body/02_V51_display_body_upright.3mf); [STEP](output/v51_external_power_body/display_body.step) |
| Rounded display roof and rear hatch | [V50 roof/hatch plate](output/v50_full_display_preflight/02_V50_display_roof_and_hatch.3mf) |
| Navy display base with closed surfaces | [V51 top-down base](output/v51_external_power_body/04_V51_closed_display_base_top_down.3mf); [STEP](output/v51_external_power_body/display_base.step) |
| Glued rear DC inlet panel | [V51 inlet panel](output/v51_dc_inlet_panel/02_DC_inlet_glue_panel.3mf); [STL](output/v51_dc_inlet_panel/dc_inlet_glue_panel_print.stl) |
| Translucent PETG indicator insert | [V51 PETG insert](output/v51_petg_led_insert/01_LED_insert_PETG.3mf); [STL](output/v51_petg_led_insert/led_insert_print.stl) |

Current complete geometry:
[LUMON_v51_GLUE_DC_INLET_ASSEMBLY.step](output/v51_dc_inlet_panel/LUMON_v51_GLUE_DC_INLET_ASSEMBLY.step).
The cloud Fusion review with the same name is a separate saved document; no
native Fusion `.f3d` archive has been exported into this project.

Projects were prepared for a Bambu P1S, 0.4 mm nozzle and textured PEI plate.
The final colour mapping was navy PLA in AMS slot 1, cotton-white PolyTerra PLA
in slot 2 and translucent PETG in slot 3. Slice and inspect the projects for
your own printer and mapping. Existing `.gcode.3mf` exports document past jobs;
their existence does not mean a historical part should be printed again.

For the next revision, retain the accepted working assembly while addressing
the recorded weight, supports, glass-pocket clearance, unused insert bore and
open printer-base underside feedback. See [BUILD_STATUS.md](BUILD_STATUS.md),
[V39 next-revision notes](output/v39_aligned_rear/NEXT_REVISION.md) and the
[V42 base feedback](output/v42_light_printer_base/README.md).

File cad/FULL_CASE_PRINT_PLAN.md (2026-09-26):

# Full-case print preparation

**USER HOLD: prepare only. Do not send or start any print until the user authorizes printing again (20 September 2026).**

Fit coupons passed: shell seam, bezel corner and heat-set insert fit. Keep 4.2mm insert bores. Physical AMS: A2 light-grey Generic PLA, A1 dark Bambu PLA Matte. Separate independent colours onto separate plates; multicolour only for a part requiring both colours.

## Active printer bay

Current source: `printer_bay_v23.py`; instructions and prepared projects: `output/v23_upper_output/README.md`. Supersedes all v19 right-shell, trim, rear and foot parts and v20/v21/v22 printer studies. Do not print those older right-module files.

V23 uses a rear-loading guided cradle, two retaining bars and an integral front with a flush logo. User measurements are 131 W × 175 D × 120 H mm in desktop orientation; rotated envelope is 131 W × 120 D × 175 H. Front-output feeding/cutting is user-confirmed. Native keyhole measurements are recorded but unnecessary to this mounting method; no corner-radius measurement is required.

CAD checks pass for solids, watertight meshes, nominal collisions and rear-removal envelope. Four proposed plate projects are saved, but Bambu import/slicing/preview are not verified. No new print has been sent. Slicer CLI crashes on the previously printed project too; native UI currently inaccessible. The next action is successful GUI import and slice, overhang/bed/filament checks, then await renewed user authorization before printing the printer-bay prototype.

## Remaining full-device work

The combined context study exposes a 20mm rise in printer-bay height compared with the display housing. Complete final cosmetic integration and right plinth/feet before releasing the entire device. The printer opening, cable routing and contact pads need physical trial. Paper changes require removing the printer through the rear; native lid sweep inside the enclosure is therefore unnecessary.

The v19 left tub, bezel, display retainer, top, rear and left foot remain review parts. Confirm real display mounting/thickness/active area, Pi/cooler envelope and power/cable layout before printing the whole left module. Do not describe hardware-reference boxes as verified installed components.

21 September update: user corrected outlet position to upper half. V23 relocates front opening and logo, and provides lower floor/tray/rear cable relief. The outlet is now measured at 90 × 14mm, centred horizontally and 56mm from upper edge (distance datum pending); connector positions still require physical confirmation; upper-output feed/cut test is already confirmed. Print hold remains in force.

21 September measurement correction: upper-output operation is already tested. Outlet 90mm wide × 14mm high, horizontally centred; 56mm from upper edge, with upper-edge/centre datum clarification pending. Plug measurements supplied: power 15mm, square USB 12mm. Small fit samples prepared in `cad/output/v24_printer_fit`; broad v23 front aperture remains provisional and has NOT yet been replaced by an unvalidated narrow slit. No print dispatch.

Confirmed 21 September: 56mm is to outlet VERTICAL CENTRE; upper/lower edges 49/63mm below printer top. V24 centre-version samples sliced 45m42s, 15.37g, A2 only. User conditionally authorized this sample plate before 11:30 if under an hour; full-case hold remains.

## Physical sample result, 21 September 2026

User confirms cradle fit is fine; retain 133mm guide gap. Printed centre-56mm template fits acceptably, but moving its opening DOWN 4mm aligns it perfectly: use centre 60mm below printer upper edge, edges 53/67mm below top, unchanged 90 × 14mm size. This supersedes the earlier 56mm value. No repeat sample print requested or sent. Corrected reference geometry is in `cad/output/v24_printer_fit_refined`; preserve this printed job as history. Paper feed/cut through template was not explicitly reported, so do not mark that test passed.

For the current v23 body placement (X16.5..147.5, Z16..191), the fitted outlet rectangle maps to X37..127 and Z124..138, centre X82/Z131. This is centred on the printer, not shell X79. The v23 broad opening remains provisional; carry these coordinates into the detailed front while resolving button access.

## Hardware correction: tapered casing, downward rocker and LED

User photos, 21 September 2026, show original front/rear walls are not parallel. In the chosen orientation these become upper/lower faces. The prior 131 × 120 × 175mm reference remains only a maximum envelope; it cannot validate support contact, printer tilt or actual outlet alignment when installed. The width coupon passed, not the full cradle. Do not print the full v23 tray/shell as a validated mount.

Original rear power rocker becomes downward-facing. Provide a clearance pocket or through-opening in BOTH tray and any shell floor beneath it, including both switch positions, assembly tolerances and insertion/removal path. The table or eventual foot/base structure must not reach the rocker through that opening. Switch width/height, position and protrusion are pending; no precise hole is guessed from photographs. Define structural support pads on verified casing lands clear of switch and connectors; shim/pad heights may differ to keep the paper-output face aligned. Retainers must secure without wedging tapered casing or loading buttons/lid.

User does not require external feed/lid-release button access; those become available after removing the intact printer for paper service. Conceal with internal noncontact clearance, not a wall resting on controls. LED should remain visible. Preferred proposal: a small separate translucent/off-white insert, supported by a concealed shoulder in the shell, with a light-collection cavity accommodating the sloped native face. Do not claim a fixed matte-PLA wall thickness will transmit enough light; test an optical sample with the actual filament. No direct loading of the native LED lens. Exact LED position and angle pending.

Required measurements: rocker outline, protrusion in both positions and distances to two adjacent edges; original front-to-rear length at lid and bottom (taper); LED outline and centre relative to upper edge in chosen orientation. Photographs establish features but not precise dimensions. The fitted outlet centre remains 60mm from printer top, but its absolute CAD height depends on corrected support placement. No printing authorized for this redesign.

## Additional measurements — 21 September

Original top length 166mm becomes front vertical span; original bottom length175mm becomes rear vertical span. Difference9mm over approximately120mm new front/back depth. This constrains overall taper but does not establish how the9mm is divided between upper and lower faces. Do not assume a9mm wedge under the printer or move the fitted outlet until support pose is determined. Keep175mm as conservative height envelope.

Downward switch outline23×16mm; distance65mm from original top/new front edge and16mm from closest side edge. Edge-versus-centre datum, side in installed coordinates and protrusion remain unconfirmed. Store measurements without silently locating a precision hole. Prefer open relief beneath rocker with support lands outside its full travel; table/base and insertion path clearance still required. No print sent.

## Confirmed rocker clearance

User confirms offsets65mm from new front and16mm from nearest side are to NEAREST EDGES. Rocker protrudes4.5mm. With provisional23mm across-width and16mm front/back axis assignment, rocker spans65–81mm from front and16–39mm from nearest side. Proposed relief27×20mm gives2mm margin on each side:63–83mm from front,14–41mm from nearest side. Reserve at least6.5mm free depth normal to the casing (4.5mm rocker +2mm margin), in both switch positions. These are design allowances, not a validated installed cutout.

Any tray/floor/base structure must clear this volume. A closed pocket under the final position alone is insufficient if the downward rocker crosses solid supports while sliding in; use an open insertion channel or a removable support arrangement. Resolve actual taper/support pose and transverse-side mapping before committing support geometry. No print sent.

Active revision: v25_tapered_printer, source printer_bay_v25.py. User-authorized60/40 taper implemented with bearing rails, rear-open switch channel, fitted90×14 paper slot and separate hollow0.8mm LED insert. LED40×4.5 projected, upper edge2mm down (interpretation); switch mapped left in top plan with FRONT at top. See v25 README for assumptions and checks. Printing requires explicit user confirmation.

21 September12:51: user authorizes useful prints until15:30, meeting15:30–16:00. Must finish with margin before15:30; do not launch a job likely to overlap. LED trial sent usingA2. Between jobs, verify plate cleared before sending; no automatic stacked jobs. This time-limited authorization supersedes earlier ask-before-every-print instruction only within this window.

## V26: lateral taper correction

User confirms final front/outlet width132mm and rear/cable-face width143mm; switch remains underneath. V25 constant-width cradle invalid. Revised source cad/printer_bay_v26.py and output/v26_double_taper_printer accommodate both tapers, with provisional symmetric lateral split. Cradle guide gaps134/145mm; bay width175mm. Geometry audits pass for estimated envelope. Replacement cradle project prepared but not sliced/sent. Full shell remains pending physical fit and full-device integration.

## V27 physical-fit acceptance and refinement

V26 mostly fits; user waives repeat cradle trial. Increase bottom support rise5.4 to8.1mm, reduce total lateral gap0.6mm. Aperture/LED front datum rises2.7mm while retaining166mm front span. Updated CAD audits pass; final cradle included with assembly parts. Shell native supported project sliced8h49m/335.77g/six filament changes,not sent. Remaining parts prepared but not sliced. See output/v27_refined_printer/README.md; native Bambu settings must be verified because imported packer settings were not fully honored.

## V28 integrated top — user-requested cancellation

V27 shell cancelled at layer1/805. V28 merges4mm top into shell, removes both top fasteners and insert bores, retains201mm external height and rear extraction. Front-down orientation prints top as upright wall; separate cover was not required for printability. Geometry audits pass; no replacement dispatched. Bed must be cleared after cooling. See output/v28_integrated_top.

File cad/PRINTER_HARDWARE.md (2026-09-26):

# Receipt-printer identification and orientation review

User product link: https://amzn.eu/d/0i2RsHIF
Resolved listing: https://www.amazon.it/dp/B0CNYYWVCS
Read 20 September 2026. Listing brand Sunydog, model POS 8370, black & grey, USB+LAN, 80mm thermal receipt printer with automatic cutter. Listing explicitly advertises wall mounting with two underside hanging holes. User photo 3 confirms two keyhole mounts and a recessed cable bay with connected power and USB.

User subsequently supplied physical dimensions: width 13.1cm, depth 17.5cm, height 12cm. Use 131mm W × 175mm D × 120mm H in the normal desktop orientation. These supersede the listing axis labels and inherited CAD dimensions (142 × 122 × 122mm). External plug/cable clearance and lid sweep are additional to this body envelope.

For the proposed 90-degree rotation about the left/right axis, the body envelope becomes 131mm W × 120mm D × 175mm H. This is a body-envelope transform only, not final enclosure dimensions. The old 55mm vertical plinth budget must be reconsidered; do not reuse it blindly with the taller rotated printer.

## Confirmed orientation and service choice

User confirmed feeding and cutting work with the printer rotated for front output. User prefers a robust integral enclosure front and accepts removing the whole printer to change paper. Native casing, cutter and lid remain intact. The original detachable-front proposal is superseded.

## Rear-loading mounting decision

Native keyholes: 61mm centre-to-centre, larger-hole centre line 132mm from the original rear/cable edge. These are recorded but not used for the current cradle mounting. No corner-radius measurement is needed.

Active source is `printer_bay_v23.py`. A removable tray and side guides allow nominal 1mm lateral clearance to the full measured rectangular body. Two screw-fastened retaining bars have nominal 0.5mm rear clearance. Front clearance is 1mm. Optional removable shims can take up play after trial fitting; do not rely on an interference fit. Contact-pad positions and actual cable bends still need physical confirmation.

Selected orientation puts native buttons above and original rear/cable edge below. The integral front exposes a 127 × 88mm upper opening for controls and output; exact outlet/control positions are not measured. The printer is represented in CAD by its measured box envelope, not a detailed model. Keep the native cutter unobstructed and verify the output path during the prototype trial.

Paper replacement: disconnect cables, remove enclosure rear cover and two retaining bars, slide the complete printer out, then open its native lid. CAD rear-removal sweep is clear with the top fitted; native lid movement inside the enclosure is not required for this service method.

See `output/v23_upper_output/README.md` for assembly, fasteners and prepared plates. Mesh and nominal collision checks pass. Slicer/preview checks remain blocked by unavailable Bambu UI and command-line crashes; no new print is released or sent. Overall display-side hardware fit and final cosmetic integration remain unfinished.

21 September update: user corrected outlet position to upper half. V23 relocates front opening and logo, and provides lower floor/tray/rear cable relief. The outlet is now measured at 90 × 14mm, centred horizontally and 56mm from upper edge (distance datum pending); connector positions still require physical confirmation; upper-output feed/cut test is already confirmed. Print hold remains in force.

21 September measurement correction: upper-output operation is already tested. Outlet 90mm wide × 14mm high, horizontally centred; 56mm from upper edge, with upper-edge/centre datum clarification pending. Plug measurements supplied: power 15mm, square USB 12mm. Small fit samples prepared in `cad/output/v24_printer_fit`; broad v23 front aperture remains provisional and has NOT yet been replaced by an unvalidated narrow slit. No print dispatch.

Confirmed 21 September: 56mm is to outlet VERTICAL CENTRE; upper/lower edges 49/63mm below printer top. V24 centre-version samples sliced 45m42s, 15.37g, A2 only. User conditionally authorized this sample plate before 11:30 if under an hour; full-case hold remains.

## Physical sample result, 21 September 2026

User confirms cradle fit is fine; retain 133mm guide gap. Printed centre-56mm template fits acceptably, but moving its opening DOWN 4mm aligns it perfectly: use centre 60mm below printer upper edge, edges 53/67mm below top, unchanged 90 × 14mm size. This supersedes the earlier 56mm value. No repeat sample print requested or sent. Corrected reference geometry is in `cad/output/v24_printer_fit_refined`; preserve this printed job as history. Paper feed/cut through template was not explicitly reported, so do not mark that test passed.

For the current v23 body placement (X16.5..147.5, Z16..191), the fitted outlet rectangle maps to X37..127 and Z124..138, centre X82/Z131. This is centred on the printer, not shell X79. The v23 broad opening remains provisional; carry these coordinates into the detailed front while resolving button access.

## Hardware correction: tapered casing, downward rocker and LED

User photos, 21 September 2026, show original front/rear walls are not parallel. In the chosen orientation these become upper/lower faces. The prior 131 × 120 × 175mm reference remains only a maximum envelope; it cannot validate support contact, printer tilt or actual outlet alignment when installed. The width coupon passed, not the full cradle. Do not print the full v23 tray/shell as a validated mount.

Original rear power rocker becomes downward-facing. Provide a clearance pocket or through-opening in BOTH tray and any shell floor beneath it, including both switch positions, assembly tolerances and insertion/removal path. The table or eventual foot/base structure must not reach the rocker through that opening. Switch width/height, position and protrusion are pending; no precise hole is guessed from photographs. Define structural support pads on verified casing lands clear of switch and connectors; shim/pad heights may differ to keep the paper-output face aligned. Retainers must secure without wedging tapered casing or loading buttons/lid.

User does not require external feed/lid-release button access; those become available after removing the intact printer for paper service. Conceal with internal noncontact clearance, not a wall resting on controls. LED should remain visible. Preferred proposal: a small separate translucent/off-white insert, supported by a concealed shoulder in the shell, with a light-collection cavity accommodating the sloped native face. Do not claim a fixed matte-PLA wall thickness will transmit enough light; test an optical sample with the actual filament. No direct loading of the native LED lens. Exact LED position and angle pending.

Required measurements: rocker outline, protrusion in both positions and distances to two adjacent edges; original front-to-rear length at lid and bottom (taper); LED outline and centre relative to upper edge in chosen orientation. Photographs establish features but not precise dimensions. The fitted outlet centre remains 60mm from printer top, but its absolute CAD height depends on corrected support placement. No printing authorized for this redesign.

## Additional measurements — 21 September

Original top length 166mm becomes front vertical span; original bottom length175mm becomes rear vertical span. Difference9mm over approximately120mm new front/back depth. This constrains overall taper but does not establish how the9mm is divided between upper and lower faces. Do not assume a9mm wedge under the printer or move the fitted outlet until support pose is determined. Keep175mm as conservative height envelope.

Downward switch outline23×16mm; distance65mm from original top/new front edge and16mm from closest side edge. Edge-versus-centre datum, side in installed coordinates and protrusion remain unconfirmed. Store measurements without silently locating a precision hole. Prefer open relief beneath rocker with support lands outside its full travel; table/base and insertion path clearance still required. No print sent.

## Confirmed rocker clearance

User confirms offsets65mm from new front and16mm from nearest side are to NEAREST EDGES. Rocker protrudes4.5mm. With provisional23mm across-width and16mm front/back axis assignment, rocker spans65–81mm from front and16–39mm from nearest side. Proposed relief27×20mm gives2mm margin on each side:63–83mm from front,14–41mm from nearest side. Reserve at least6.5mm free depth normal to the casing (4.5mm rocker +2mm margin), in both switch positions. These are design allowances, not a validated installed cutout.

Any tray/floor/base structure must clear this volume. A closed pocket under the final position alone is insufficient if the downward rocker crosses solid supports while sliding in; use an open insertion channel or a removable support arrangement. Resolve actual taper/support pose and transverse-side mapping before committing support geometry. No print sent.

Active revision: v25_tapered_printer, source printer_bay_v25.py. User-authorized60/40 taper implemented with bearing rails, rear-open switch channel, fitted90×14 paper slot and separate hollow0.8mm LED insert. LED40×4.5 projected, upper edge2mm down (interpretation); switch mapped left in top plan with FRONT at top. See v25 README for assumptions and checks. Printing requires explicit user confirmation.

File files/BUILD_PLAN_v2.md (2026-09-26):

# LUMON_TERMINAL — v2 build plan

Supersedes sections 9, 10, 17, 18, 20, 30 of the original specification.
Everything here is generated by `lumon_v2.py`; change a parameter, rerun, get
new STEP/STL/drawings.

**Envelope: 359 × 153 × 144 mm** (W × D × H)

---

## 1. Why the numbers moved

| | blockout | v2 | reason |
|---|---|---|---|
| width | 353 | 359 | spine wall thickened to 9 mm so inserts sit inside it |
| height | 130 | 144 | 18 mm plinth: the display needs ≥12 mm of cavity above and below for M3 bosses. At 130 there were 6 mm and no way to clamp the panel |
| depth | 153 | 153 | unchanged |

The original 340–350 × 135–145 targets were guesses. 359 is what the real
components plus 3 mm walls actually produce. Do not compress it back.

---

## 2. Split architecture

One seam, vertical, on the spine between display and printer zones. It is
forced by the bed (359 mm fits nothing) and it is the only seam that also
reads as deliberate industrial detailing.

```
        tub_left  (201)              tub_right  (158)
   ┌──────────────────────────┬──┬──────────────────────┐
   │  display + electronics   │  │   printer well       │
   │  open top → top_plate    │  │   open top, no lid   │
   └──────────────────────────┴──┴──────────────────────┘
                          3 mm  9 mm
                          wall  spine wall
```

Each module is a **monocoque tub**: floor, four walls and front face printed
as one piece, open at the top. Tubs are stiff, have few tolerance stacks, and
both print in the same orientation so the front-face layer lines line up
across the seam.

### Parts

| part | mm (X×Y×Z) | notes |
|---|---|---|
| `tub_left` | 201 × 153 × 144 | display window, top rebate, retainer bosses, rear opening |
| `tub_right` | 158 × 153 × 144 | printer well open to the top face, printer riser rails, 9 mm spine wall |
| `top_plate_left` | 197 × 149 × 3 | drops flush into the rebate, 4 × M3 |
| `display_retainer` | 194 × 4 × 139 | clamps the panel against the front wall lip |
| `rear_panel_left` | 185 × 6 × 120 | service access, 4 × M3 |
| `rear_panel_right` | 110 × 6 × 90 | service access, 4 × M3 |

All six fit a 250 × 210 bed. Nothing needs diagonal placement.

### Seam joint

- 5 × M3 socket head through the 3 mm wall of `tub_left` into heat-set inserts
  **sunk into the 9 mm spine wall** of `tub_right`. No boss protrudes, which
  matters because the printer sits 2 mm from that wall.
- 2 × Ø4 steel dowels (hole Ø4.3) locate the seam before the screws go in.
- Screw heads are reached from inside the left module with the top plate off.
- Express the seam externally as a 1.5 mm shadow gap at Milestone 4. Do not
  try to hide it.

---

## 3. Mounting — no invented holes

**Printer.** Not screwed down. It drops into the well from above and is
captured by four tub walls at 2 mm clearance, sitting on two riser rails that
lift it 18 mm so its top lands flush with the top face. The rails leave a
cable channel underneath. Its own mounting holes stay unmeasured and unused.

**Display.** Not glued, and it does not use its own mounting holes either.
The panel sits against a 6 mm lip formed by the front wall, is located
laterally by two printed ribs, and is clamped from behind by
`display_retainer` into 4 bosses (2 low, 2 high — the only places with room).

**Lid clearance.** `printer_top_rim = 0`. The well is open across the whole
printer footprint with zero inward overhang, because the clamshell's hinge
line and swing arc are unmeasured. Stiffness comes from a 15 mm tall, 3 mm
thick flange on the *inside* of the walls instead of an inward lip. Do not
raise `printer_top_rim` until the lid is measured open.

---

## 4. Hardware

- 21 × M3 short heat-set insert (OD 4.6 × L 4.0) — hole Ø4.2, depth 6
- 21 × M3 socket head, 8–12 mm
- 2 × Ø4 × 12 steel dowel pin
- 4 × Ø14 adhesive rubber foot (8 recesses provided)

---

## 5. Print settings

- PETG or PLA, 0.4 nozzle, 0.2 layer, 4 perimeters, 25 % gyroid.
- Both tubs print open-top-up. No supports needed: the window and the rear
  opening are vertical, the flanges are vertical thickenings, the boss
  cylinders are horizontal-axis and self-supporting at Ø9.
- Tubs are ~18–24 h each. Print test coupons first (Milestone 2.5).

---

## 6. Assembly sequence

Validated as physically possible — no trapped fastener.

1. Heat-set all 21 inserts while the tubs are still empty.
2. Display into `tub_left` from behind → `display_retainer` → 4 × M3.
3. Pi and PSU into the left bay, cables routed to the spine pass-through.
4. Dowels into `tub_right`, mate the two tubs, 5 × M3 from the left bay.
5. Printer into the right well from above, cables down the riser channel.
6. `top_plate_left` → 4 × M3.
7. Rear panels → 8 × M3.
8. Feet.

Reverse for service. Paper roll replacement needs none of it: the lid is
exposed on the top face.

---

## 7. Revised milestones

**M0 — Metrology. Blocking. Nothing downstream is trustworthy until done.**
Caliper the printer: W, D, H of the *unit* (the 142/122/122 is almost
certainly the carton), the lid footprint, the lid's open swing, the paper slot
position, the LED and button positions on the front edge, all connector
positions. Caliper the display: total assembly thickness with the driver PCB
and standoffs, cable exit positions. Record the Pi model, cooler, PSU.
*Exit: every UNVERIFIED/TBD parameter in `lumon_v2.py` replaced with a
measured value.*

**M1 — Blockout.** Done. Re-run after M0 and re-check the envelope.

**M1.5 — Split and structure.** Done — this document.
*Exit: every part fits the bed, zero interference, assembly sequence valid.*

**M2 — Functional apertures.** Front slot for the printer LED and buttons,
rear port cutouts for power/USB/Ethernet, DSI routing with a generous radius,
vent slots on the rear and underside, cable channel under the riser.
*Blocked by M0 — all positions come from measurement.*

**M2.5 — Test coupons. New, and the highest-value hour in the plan.**
Print three fragments only: the seam joint corner (dowel + insert + screw),
the display rebate corner with a rib, and one riser rail end. ~1 h total.
Validates tolerances before committing 40 h of tub prints.
*Exit: dowel slides with hand pressure, insert seats square, display corner
holds the panel without rocking.*

**M3 — Mechanical refinement.** Ribbing where the coupons showed flex, cable
management features, fillet the internal corners, service-panel gasketing if
wanted.

**M4 — Industrial design.** Shadow gap at the seam, plinth line, display
bezel chamfer, recessed ID plate, single status LED. The aesthetic goes on
last, over a structure that already works.

**M5 — Printability pass.** Orientation, seam placement in the slicer, wall
count, first-layer adhesion on the 201 × 153 footprint.

**M6 — Prototype.** Print `tub_right` first: it carries the riskiest unknown
(the printer envelope). Fit the actual printer before printing `tub_left`.

**M7 — Revision.** Feed measured fit back into the parameter table and
regenerate.

---

## 8. Still unverified

Printer W/D/H, lid swing arc, LED/button positions, connector positions,
display assembly thickness, Pi model, PSU dimensions, cable types, and the
power architecture (one internal PSU with an IEC inlet, or two external
bricks — this decides the rear panel and the left bay volume).

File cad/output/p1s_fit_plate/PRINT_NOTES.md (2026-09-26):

# First physical fit test — 20 September 2026

Bambu Studio project: `LUMON_v19_fit_test.3mf`.

Sent through Bambu Studio to P1S `3DP-01P-994`; device acknowledged the matching job name and completed downloading. Bed seen clear in camera before sending. Auto bed leveling enabled; timelapse disabled.

- A1 / physical AMS slot 1: dark Bambu PLA Matte; bezel corner.
- A2 / physical AMS slot 2: user-confirmed light-grey Generic PLA; screen corner and both seam samples.
- Slot 4 orange was explicitly excluded from final mapping.
- 0.4mm standard nozzle, textured PEI, 0.20mm layers, 3 walls, 20% infill, 3mm outer brims.
- Automatic support from build plate enabled for screen-corner sample.
- Slice estimate: 1h24m, 27.07g total, 16 filament changes.

After cooling, remove brims/support carefully. Check the bezel against the opening, inspect the revised lower-left corner, and test mating seam alignment and M3 holes/inserts. These samples check local geometry and tolerances; they do not establish that the real display or receipt printer fits. Actual device measurements remain required before full-shell release.

`LUMON_v19_fit_test_setup.3mf` is the unarranged intermediate used by `cad/review/configure_fit_project.py`; print the final project above, not that intermediate.

## User-reported fit results

Both grey seam samples match, and the dark bezel corner matches the grey screen corner (confirmed 20 September 2026). Insert installation and screw retention remain untested.

Hardware photo shows M3 screws in lengths 6/10/14/20mm in the silver kit and 8/12/16/20mm in the black kit, plus assorted brass inserts whose dimensions are not identifiable from the photo. Current insert bores are nominally 4.2mm diameter and 6mm deep; intended insert OD in source is 4.6mm. Obtain actual M3 insert outside diameter and length before installation or changing bore dimensions.

User printing preference: group separate parts onto single-color plates to reduce purge waste. Use multicolor printing when required within one part, such as the logo wall. User accepted the first coupon plate's 16 changes.

User subsequently confirmed the insert test is fine and requested proceeding. Retain the tested 4.2mm insert bore; no bore enlargement is justified by the approximate caliper photos. This confirms the seam coupon fit, not every blind-hole installation in the enclosure.

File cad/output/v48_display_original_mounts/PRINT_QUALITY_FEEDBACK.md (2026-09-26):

# V48 print-quality feedback — 24 September 2026

User sees continuing fraying on the opposite side after the frame was flipped,
and suggests filament calibration or excessive separation from support. This
must be resolved or deliberately avoided before final enclosure printing.

Photo:
`/tmp/codex-remote-attachments/01a0bf3e-2220-7252-adef-d07f9ff37b1f/E4D6E3C7-4DCB-467E-A393-EA903649E511/1-Foto-1.jpg`

## Evidence and uncertainty

- Photo shows loose perimeter strands and exposed internal/support structures.
  Do not classify all exposed infill as a defect or judge unfinished top layers
  as completed surface finish.
- Read-only Bambu check during this report: matching V48 job printing at
  58%, layer103/121,1h16m remaining, ETA16:13. Completion not verified.
- Moving the rough area when reversing orientation is consistent with a
  support-contact/bridging problem. This is a hypothesis, not a proven cause;
  exact contact face and damage after support removal still need inspection.
- V48's upward-facing glass seat is not yet confirmed clean, flat or sound.
  Do not mark the orientation change as a validated quality fix.
- Original mount hole alignment remains physically confirmed and unshifted.

## Actual saved toolpath settings

- PolyTerra Cotton White PLA, A2, nozzle220 C.
- Same PLA for model and supports; normal snug supports.
- Support top Z gap **0.2 mm**, unchanged from V46.
- Three top interface layers, interface spacing0.15 mm; support/model XY0.3 mm.
- Support scaffold spacing4 mm; bridge speed30 mm/s; interface speed40 mm/s.
- Saved project filament2 flow ratio0.985, maximum volumetric speed29 mm³/s,
  part fan100%, auxiliary fan70%. These are extracted settings, not measured
  calibration results. Check effective settings after GUI profile resolution;
  do not claim the intended template values are necessarily the saved values.
- The maximum flow setting alone does not establish actual extrusion demand
  or prove under-extrusion in these low-speed bridge/support paths.

The 0.2 mm same-material gap is Bambu's general starting recommendation.
A smaller gap trades easier removal for better support-contact finish; it is
not automatically better for this thin ledge. Reference:
[Bambu user manual, support settings pages65–66](https://csm.bblcdn.com/hub/4668d0ca43994ff3bff4b37f1a65c2e7.pdf#page=66).

## Before the final case

1. Inspect the completed part after support removal: distinguish sacrificial
   support strands from model damage; check upward glass bearing, lug lands,
   reverse face, ordinary walls and top surfaces separately.
2. Prefer a production orientation or local printable geometry that avoids
   support contact on visible and glass-bearing faces. This is a full-case
   orientation decision; a successful small fixture is not proof for the shell.
3. Use a small representative corner/ledge coupon, with comparable unsupported
   spans and support height, to compare current0.2 mm contact gap with a closer
   candidate (e.g.0.12 mm). Keep other variables fixed first; retain the dense
   interface and verify effective sliced gap. Do not make PLA-to-PLA gap zero.
   Check surface, removal effort, ledge damage and dimensional accuracy.
4. Include a directly supported/bed-printed reference to distinguish local
   support-contact failure from general extrusion quality. If supported walls
   or top surfaces also show gaps/poor bonding, verify the saved filament
   profile and run targeted flow/temperature checks before more surface tests.
5. Tune speed/cooling only against observations, rather than changing all
   variables together. Preserve the user's preference to minimize filament
   waste; do not use another full frame just to calibrate support finish.

No new calibration print was prepared or dispatched by this note. The active
job was not changed. This records a final-print quality check, not a confirmed
diagnosis or a reason to change the accepted hole pattern.

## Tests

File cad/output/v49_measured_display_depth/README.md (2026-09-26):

## Physical result — 24 September 2026

Both corner samples passed seating without bending and gentle tightening of
the actual 4 mm screws. User measured to identify the mixed samples and selects
0.12 mm support gap as better. See physical_test.json. Historical CAD and slice
audit below precede this result; full enclosure still needs final preparation.

# V49 — measured display mounting depth

The actual glass-front-to-metal mounting plane is 8.4 mm, not the inherited
5.96 mm. The four pads now start 2.44 mm farther behind the glass. The glass
itself stays in its 1 mm recess, on the existing 3 mm-wide bearing seat.

The user's screws measure 4 mm underneath their heads. Reducing the plastic
grip from 3.9 to 2.0 mm leaves 2.0 mm nominal thread engagement. The 6.5 mm
head recess diameter stays unchanged: the user confirms the heads fit.
Use these measured screws, not the previously assumed M3x6 screws.

All four hole axes and the original arm roots/beams are unchanged. The
193.6 x111.4 mm/R8.2 glass pocket and 3 mm bearing width are unchanged.
The production left bay, assembly STEP, and full fixture are updated together.
Fusion has not been synchronized; its last saved version remains V39.

## Small test plate

The prepared plate contains two identical upper-right glass corners, each
with one complete integral mounting arm. Both print front-face down again.
The LEFT sample uses a 0.20 mm top support gap; the RIGHT uses 0.12 mm.
All other settings match. Keep track of the samples while removing them.
This compares support release/finish while testing the measured depth and
screw reach, without printing another whole frame.

1. Remove supports and loose strands, without shaving away bearing material.
2. Fit one sample to the upper-right glass corner, looking at the display from
   the front in its correctly aligned landscape orientation. The glass rests
   on the short 3 mm ledge; the arm sits behind the matching metal lug.
3. With no screw, the glass and metal should both meet their supports without
   pushing the arm backwards. Report a gap or bending instead of forcing it.
4. Try one measured 4 mm screw gently. Its head should reach the recess floor
   while the mounting face remains relaxed. Stop if it resists before seating.
5. Compare the two support-contact surfaces and how cleanly support released.

## Verification and limits

CAD checks verify valid single solids, watertight meshes, full 3 mm seat width,
glass inward stop/outward clearance, clear screw/head passages, 2 mm plastic
grip, and unchanged geometry outside four pad masks. Nominal front insertion
also passes with the conservative metal envelope extended to the measured
mounting plane. Chassis XY and Pi references remain provisional.

The manufacturer's drawing does not explicitly establish the previously
claimed universal 2.5 mm thread-depth limit. Its handling guide requires screws
to avoid pressing into the backlight. The actual 2 mm engagement and simultaneous
glass/lug bearing remain physical checks, not CAD-established facts.

The inherited full-case cable/divider clash and power/access review are still
outstanding. This is a small test release, not a full display-case release.
Bambu slice reviewed and saved: **50m14s, 14.30 g total**, white A2 only, no
colour swaps. Both support-gap overrides survive the saved project and produce
different interface heights in the toolpath. User confirmed plate clear; Send
clicked with A2 white, bed leveling/timelapseOFF. P1S accepted the matching
V49 job and reports0/152,startup/heating,ETA18:14 local. First layer and
completion are not yet verified. See print_dispatch.json.

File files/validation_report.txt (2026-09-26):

=== ENVELOPE ===
overall 382.96 x 155.00 x 154.00 mm (W x D x H)
seam plane x = 224.96   left module 225 | right module 158
base block 24 mm tall, standing 2.5 mm proud
spine wall 9 mm (inserts sunk into it, nothing protrudes)
body upright; SCREEN tilted 10 deg in a wedge recess
  recess depth: 0 at the bottom edge, 23.8 mm at the top
  panel rear reaches y=45.0 at its top; PSU front y=38
  actual panel/PSU overlap: 0.0 mm3  PASS
  printer front at y=5, wall inner at y=3  PASS
edge breaks: r6 outer verticals, r6 every top edge
ID mark: deboss, 0.8 mm relief, 58 mm wide, artwork = logo_src.png
  minimum feature width should be >= 0.8 mm at a 0.4 nozzle
  logo_fill.stl fills the recess exactly - second filament, blue

=== MARK KEEP-OUT ===
mark occupies x 275..333, z 37..66
  clearance to base block top    12.6 mm  PASS
  clearance to seam gap          49.0 mm  PASS
  clearance to right edge        50.0 mm  PASS
  clearance to bottom of case    35.4 mm  PASS

=== M4 DETAILING ===
bottom edge chamfer 1.2 mm
display window chamfer 1.2 mm on the raked plane
seam shadow gap 2 mm wide x 1 mm deep (half cut into each module, front and top)
base block 24 tall, 2.5 proud, corner radius 14.5
display surround 219 x 135, r12, 3 thick in a 1 mm rebate
rear exhaust restyled as 5 stacked rules (Lumon print motif)
finish: shells #DEE9EE pale grey, mark #0B4F7E blue, display surround #10161E

=== PART LIST / PRINT BED FIT ===
part                       X       Y       Z   Prusa MK4 / Ende   Bambu P1S / X1C          Prusa XL
tub_left               227.5   160.0   152.0               PASS              PASS              PASS  
tub_right              160.5   160.0   154.0               PASS              PASS              PASS  
top_plate_left         221.4   151.4     3.0               PASS              PASS              PASS  
display_retainer       194.4    28.0   137.3               PASS              PASS              PASS  
rear_panel_left        140.0     6.0   114.0               PASS              PASS              PASS  
rear_panel_right       110.0     6.0    90.0               PASS              PASS              PASS  
display_bezel          218.4     5.5   136.2               PASS              PASS              PASS  

=== INTERFERENCE ===
display vs tub_left             0.00 mm3  PASS
display vs retainer             0.00 mm3  PASS
printer vs tub_right            0.00 mm3  PASS
pi vs tub_left                  0.00 mm3  PASS
psu vs tub_left                 0.00 mm3  PASS
tub_left vs tub_right           0.00 mm3  PASS
top_plate vs tub_left           0.00 mm3  PASS
(retainer is expected to touch the display: that is the clamp)

=== POWER BAY ===
PSU pocket 129 x 97 x 30 at x=90 y=38  (LRS-100-24, or LRS-75-24 with shorter blocks)
headroom above the PSU mesh case: 117 mm
mains barrier at x=83, height 46 mm
mains inlet cutout 47.2 x 28.3 in the FIXED rear wall, outer face thinned to 1.5 mm
PSU       vs tub_left            0.00 mm3  PASS
Pi        vs tub_left            0.00 mm3  PASS
IEC body  vs tub_left            0.00 mm3  PASS
buck      vs tub_left            0.00 mm3  PASS
IEC body vs PSU                 0.00 mm3  PASS
Pi vs PSU                       0.00 mm3  PASS
buck vs Pi                      0.00 mm3  PASS
PSU vs display                  0.00 mm3  PASS
mains zone to LV zone separation: barrier + 1 mm air

=== PRINTER SERVICE ===
top well 146 x 126 mm, open to the top face
inward overhang over the lid: 0.0 mm  PASS (must stay 0 until the lid is measured)
printer drops in from above, captured by the tub walls on 4 sides
riser height 28 mm -> cable space under the printer

=== FASTENER SCHEDULE ===
M3 heat-set inserts (short, OD 4.6 x 4.0): 21
  spine 5 | top plate 4 | display retainer 4 | rear panels 8
M3 socket head screws: 21   lengths 8-12 mm
steel dowel pins 4 mm: 2 (spine alignment)
rubber feet pads: 8 recesses, 4 needed

=== STILL UNVERIFIED ===
printer_w/d/h, lid swing, LED and button positions, port positions
display_t, Pi model, PSU, cable types

=== PARAMETERS ===
display_w                 192.96
display_h                 110.76
display_t                  21.00
display_clear               1.00
bezel_overlap               6.00
printer_w                 142.00
printer_d                 122.00
printer_h                 122.00
printer_clear               2.00
printer_top_rim             0.00
psu_w                     129.00
psu_d                      97.00
psu_h                      30.00
psu_clear                   3.00
psu_headroom               20.00
iec_cut_w                  47.20
iec_cut_h                  28.30
iec_body_w                 50.00
iec_body_h                 31.00
iec_body_d                 31.00
iec_panel_t                 1.50
partition_t                 3.00
rake_deg                   10.00
fillet_main                12.00
fillet_top_r                6.00
chamfer_bottom              1.20
bezel_chamfer               1.20
bezel_margin               12.00
bezel_t                     3.00
bezel_rebate                1.00
bezel_r                    12.00
gap_w                       1.00
gap_d                       1.00
skirt_h                    24.00
skirt_out                   2.50
skirt_reveal                1.20
plinth_z                   17.00
plinth_gap_h                1.50
plinth_gap_d                0.00
logo_mode                 deboss
logo_w                     58.00
drop_w                     16.00
drop_zl                   118.00
logo_zl                    52.00
logo_clear                  8.00
logo_relief                 0.80
logo_thicken                0.20
plate_w                    64.00
plate_h                    18.00
plate_depth                 1.20
plate_clear                 0.20
buck_w                     35.00
buck_d                     65.00
buck_h                     20.00
pi_w                       85.00
pi_d                       56.00
pi_h                       22.00
pi_hole_dx                 58.00
pi_hole_dy                 49.00
pi_hole_inset               3.50
pi_standoff                 6.00
wall                        3.00
base_thickness              4.00
plinth                     28.00
rear_cavity                25.00
printer_front               5.00
spine_wall                  9.00
top_flange                 15.00
top_flange_t                3.00
lid_rebate                  3.00
shadow_gap                  1.50
insert_hole_d               4.20
insert_depth                6.00
boss_d                      9.00
screw_clear_d               3.40
cbore_d                     6.20
cbore_depth                 2.20
dowel_d                     4.00
dowel_fit                   0.15
fit_clear                   0.30
foot_d                     14.00
foot_recess                 1.50
W                         382.96
D                         155.00
H                         154.00
x_split                   224.96

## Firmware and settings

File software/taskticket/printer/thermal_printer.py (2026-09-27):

from escpos.printer import Usb
from typing import Optional, Dict
import os
import sys
import logging
from pathlib import Path
from dotenv import load_dotenv
import usb.core
import usb.util
from dataclasses import dataclass
from printer.logo import raster_logo, raster_image
from printer.ticket import render_ticket, format_ticket_text

logger = logging.getLogger(__name__)

@dataclass
class ThermalFormatting:
    """ESC/POS formatting commands"""
    # Basic formatting
    INIT = '\x1b\x40'  # Initialize printer
    BOLD_ON = '\x1b\x45\x01'
    BOLD_OFF = '\x1b\x45\x00'
    UNDERLINE_ON = '\x1b\x2d\x01'
    UNDERLINE_OFF = '\x1b\x2d\x00'
    REVERSE_ON = '\x1d\x42\x01'
    REVERSE_OFF = '\x1d\x42\x00'
    
    # Text size
    NORMAL = '\x1b\x21\x00'
    DOUBLE_HEIGHT = '\x1b\x21\x10'
    DOUBLE_WIDTH = '\x1b\x21\x20'
    DOUBLE_SIZE = '\x1b\x21\x30'
    
    # Alignment
    ALIGN_LEFT = '\x1b\x61\x00'
    ALIGN_CENTER = '\x1b\x61\x01'
    ALIGN_RIGHT = '\x1b\x61\x02'
    
    # Paper control
    FEED_LINE = '\n'
    FEED_AND_CUT = '\n\n\n\n\x1d\x56\x41\x03'
    
    @staticmethod
    def create_header(text: str) -> str:
        """Create a centered header with borders"""
        border = "=" * 48
        return f"{border}\n{text.center(48)}\n{border}"

class ThermalPrinter:
    def __init__(self):
        load_dotenv()
        
        # Get printer configuration from environment variables
        self.vendor_id = int(os.getenv('PRINTER_VENDOR_ID', '0x0416'), 16)
        self.product_id = int(os.getenv('PRINTER_PRODUCT_ID', '0x5011'), 16)
        self.in_ep = int(os.getenv('PRINTER_IN_EP', '0x82'), 16)
        self.out_ep = int(os.getenv('PRINTER_OUT_EP', '0x01'), 16)
        
        self.printer = None
        self.is_initialized = False
        self.debug_mode = os.getenv('PRINTER_DEBUG', 'false').lower() == 'true'
        
        # Add formatting helper
        self.format = ThermalFormatting()
        
        # Use direct access by default
        self.use_direct_access = True
        self.printer_device = '/dev/usb/lp0'
    
    def initialize(self) -> bool:
        """Initialize the printer connection."""
        if self.is_initialized:
            return True
        
        if self.use_direct_access:
            try:
                # Check if printer device exists
                if not os.path.exists(self.printer_device):
                    print(f"Printer device {self.printer_device} not found.")
                    return False
                
                # Test if we can write to it
                with open(self.printer_device, 'wb') as f:
                    f.write(b'\x1b@')  # ESC @ - initialize printer
                
                self.is_initialized = True
                print(f"Printer initialized successfully using direct access to {self.printer_device}")
                return True
            except Exception as e:
                print(f"Error initializing printer with direct access: {e}")
                return False
        else:
            # Original USB initialization
            try:
                # Find the printer device
                device = usb.core.find(idVendor=self.vendor_id, idProduct=self.product_id)
                
                if device is None:
                    print(f"Printer not found. Vendor ID: {self.vendor_id:04x}, Product ID: {self.product_id:04x}")
                    return False

                # Try to connect to the printer
                try:
                    self.printer = Usb(
                        self.vendor_id,
                        self.product_id,
                        timeout=0,
                        in_ep=self.in_ep,
                        out_ep=self.out_ep
                    )
                    self.is_initialized = True
                    print("Printer initialized successfully!")
                    return True
                    
                except Exception as e:
                    print(f"Error connecting to printer: {e}")
                    return False
                
            except Exception as e:
                print(f"Printer initialization error: {e}")
                return False

    def print_text(self, text: str, logo: bool = False) -> bool:
        """Print text to the thermal printer."""
        logo_bytes = b''
        if logo and os.getenv('PRINTER_TASK_LOGO', '1').lower() in ('1', 'true', 'yes'):
            try:
                logo_path = Path(__file__).resolve().parents[1] / 'static/lumon-print.png'
                logo_bytes = raster_logo(logo_path, int(os.getenv('PRINTER_WIDTH_DOTS', '576')))
            except (OSError, ValueError):
                # Prepare everything before opening USB. A missing asset must
                # not prevent the task text from printing.
                logger.warning('Ticket logo unavailable; printing the task text only.')
        if self.debug_mode:
            print("\n=== DEBUG: PRINTER OUTPUT ===")
            if logo_bytes:
                print('[Lumon bitmap logo]')
            print(text)
            print("===========================\n")
            return True
            
        if not self.is_initialized and not self.initialize():
            return False

        try:
            if self.use_direct_access:
                # Print using direct file access
                with open(self.printer_device, 'wb') as f:
                    # One job, no reset between image and task, one final cut.
                    job = (self.format.INIT.encode('utf-8') + logo_bytes +
                           text.encode('utf-8', errors='replace') +
                           self.format.FEED_AND_CUT.encode('utf-8'))
                    f.write(job)
            else:
                # Print using python-escpos
                self.printer.text(self.format.INIT)
                if logo_bytes:
                    self.printer._raw(logo_bytes)
                self.printer.text(text)
                self.printer.text(self.format.FEED_AND_CUT)
                
            return True
                
        except Exception as e:
            print(f"Printing error: {e}")
            import traceback
            traceback.print_exc()
            return False

    def print_task_ticket(self, task: Dict) -> bool:
        """Render the full work slip; prepare all pixels before opening USB."""
        try:
            image = render_ticket(task, width=int(os.getenv('PRINTER_WIDTH_DOTS', '576')),
                                  show_logo=os.getenv('PRINTER_TASK_LOGO', '1').lower() in ('1', 'true', 'yes'))
            payload = raster_image(image)
        except (OSError, ValueError):
            logger.warning('Ticket artwork unavailable; using the native-text work slip.')
            return self.print_text(format_ticket_text(task), logo=True)
        return self.print_image_job(payload)

    def print_image_job(self, payload: bytes) -> bool:
        """Send one already-rendered ticket with one reset and one final cut."""
        if self.debug_mode:
            print('DEBUG: Lumon work-slip raster job (%d bytes), no USB write.' % len(payload))
            return True
        if not self.is_initialized and not self.initialize():
            return False
        # GS V A feeds the image to the cutter; one extra line avoids the
        # previous four-line blank tail on every graphics-only ticket.
        job = self.format.INIT.encode() + payload + b'\n\x1d\x56\x41\x03'
        try:
            if self.use_direct_access:
                with open(self.printer_device, 'wb') as device:
                    if device.write(job) != len(job):
                        raise OSError('Incomplete ticket write')
            else:
                self.printer._raw(job)
            return True
        except Exception:
            logger.exception('Work-slip printing failed; the job will not be retried automatically.')
            return False

    def test_printer(self) -> bool:
        """Print a test page with all formatting options."""
        test_text = (
            f"{self.format.INIT}"  # Initialize printer
            f"{self.format.create_header('PRINTER TEST')}\n\n"
            "Normal text\n"
            f"{self.format.DOUBLE_HEIGHT}Double Height Text\n"
            f"{self.format.DOUBLE_WIDTH}Double Width Text\n"
            f"{self.format.DOUBLE_SIZE}Large Text\n"
            f"{self.format.NORMAL}"  # Reset to normal
            f"{self.format.BOLD_ON}Bold Text\n"
            f"{self.format.BOLD_OFF}Normal Text\n"
            f"{self.format.UNDERLINE_ON}Underlined Text\n"
            f"{self.format.UNDERLINE_OFF}Normal Text\n"
            f"{self.format.REVERSE_ON}Reverse Text\n"
            f"{self.format.REVERSE_OFF}Normal Text\n\n"
            f"{self.format.ALIGN_LEFT}Left aligned\n"
            f"{self.format.ALIGN_CENTER}Center aligned\n"
            f"{self.format.ALIGN_RIGHT}Right aligned\n"
            f"{self.format.ALIGN_LEFT}"  # Reset alignment
            "\n┌──────────────┐\n"
            "│  Box Test    │\n"
            "└──────────────┘\n\n"
            "Test Complete!\n"
        )
        return self.print_text(test_text)

    def print_simple_test(self) -> bool:
        """Print a simple test without any special formatting."""
        if not self.initialize():
            return False
            
        try:
            test_text = (
                f"{self.format.INIT}"
                f"{self.format.create_header('BASIC PRINTER TEST')}\n\n"
                "Normal text\n"
                f"{self.format.BOLD_ON}Bold text\n"
                f"{self.format.BOLD_OFF}Normal text\n"
                f"{self.format.DOUBLE_SIZE}Large text\n"
                f"{self.format.NORMAL}Back to normal\n"
                "Test complete!\n"
            )
            
            return self.print_text(test_text)
            
        except Exception as e:
            print(f"Printing error: {str(e)}")
            return False

    def print_ticket(self, title: str, content: Dict[str, str], footer: str = "") -> bool:
        """Print a formatted ticket."""
        try:
            ticket_text = (
                f"{self.format.INIT}"
                f"{self.format.ALIGN_CENTER}"
                f"{self.format.create_header(title)}\n\n"
                f"{self.format.ALIGN_LEFT}"
            )
            
            # Add content
            for key, value in content.items():
                ticket_text += f"{self.format.BOLD_ON}{key}:{self.format.BOLD_OFF} {value}\n"
            
            # Add footer if provided
            if footer:
                ticket_text += (
                    f"\n{self.format.ALIGN_CENTER}"
                    f"{footer}\n"
                    f"{self.format.ALIGN_LEFT}"
                )
            
            return self.print_text(ticket_text)
            
        except Exception as e:
            print(f"Error printing ticket: {str(e)}")
            return False

def find_printer():
    """Utility function to find USB printer IDs and suggest .env settings."""
    devices = usb.core.find(find_all=True)
    
    print("Available USB devices:")
    print("\nAdd these lines to your .env file for detected printers:\n")
    
    found_printers = False
    for device in devices:
        try:
            if device.product and ('POS' in device.product or 'print' in device.product.lower()):
                found_printers = True
                print(f"# {device.manufacturer} - {device.product}")
                print(f"PRINTER_VENDOR_ID=0x{device.idVendor:04x}")
                print(f"PRINTER_PRODUCT_ID=0x{device.idProduct:04x}")
                print(f"PRINTER_IN_EP=0x82  # Default value, might need adjustment")
                print(f"PRINTER_OUT_EP=0x01  # Default value, might need adjustment")
                print("PRINTER_DEBUG=false")
                print()
                
                # Try to get endpoint information
                try:
                    cfg = device.get_active_configuration()
                    intf = cfg[(0,0)]
                    ep_in = usb.util.find_descriptor(
                        intf,
                        custom_match=lambda e: \
                            usb.util.endpoint_direction(e.bEndpointAddress) == \
                            usb.util.ENDPOINT_IN
                    )
                    ep_out = usb.util.find_descriptor(
                        intf,
                        custom_match=lambda e: \
                            usb.util.endpoint_direction(e.bEndpointAddress) == \
                            usb.util.ENDPOINT_OUT
                    )
                    if ep_in and ep_out:
                        print(f"# Detected endpoints:")
                        print(f"# IN_EP=0x{ep_in.bEndpointAddress:02x}")
                        print(f"# OUT_EP=0x{ep_out.bEndpointAddress:02x}")
                        print()
                except:
                    pass
        except:
            pass
    
    if not found_printers:
        print("No POS/printer devices found!")

if __name__ == "__main__":
    # Find available printers
    find_printer()
    
    # Test the printer
    print("\nTesting printer...")
    printer = ThermalPrinter()
    print("\nRunning simple test first...")
    printer.print_simple_test()
    print("\nRunning formatted test...")
    printer.test_printer()

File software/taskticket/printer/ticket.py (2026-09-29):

"""A compact Lumon-inspired work slip, rendered at the printer's actual dot width.

This is original themed stationery, not a reproduction of a screen-used prop.
The saved preview and USB job use the same monochrome pixels.
"""
from datetime import datetime
from functools import lru_cache
import hashlib
import math
import os
from pathlib import Path
import textwrap
import unicodedata
from zoneinfo import ZoneInfo

from PIL import Image, ImageDraw, ImageFont

ASSETS = Path(__file__).resolve().parents[1] / 'static'
MOTTO = 'The work is mysterious and important.'
# The POS80 leaves a leading margin between its print head and cutter. Keep
# only 1 mm of artwork above the logo, and add 12 mm to the former footer
# padding to balance the physical ticket. At 203 dpi, eight dots are about 1 mm.
TOP_MARGIN_DOTS = 8
BOTTOM_PADDING_DOTS = 112


def clean_text(value):
    value = unicodedata.normalize('NFC', str(value or ''))
    # Card text cannot introduce ESC/POS commands or unexpected blank lines.
    value = ''.join(' ' if char.isspace() else char for char in value
                    if char.isspace() or not unicodedata.category(char).startswith('C'))
    return ' '.join(value.split())


def ticket_content(task, issued_at=None):
    if issued_at is None:
        issued_at = datetime.now(ZoneInfo(os.getenv('TASKTICKET_TIMEZONE', 'Europe/Luxembourg')))
    title = clean_text(task.get('ticket_title') or task.get('title')) or 'Untitled assignment'
    reference = hashlib.sha256(str(task.get('task_id') or title).encode()).hexdigest()[:6].upper()
    def duration(value):
        try:
            minutes = float(value)
            if not math.isfinite(minutes) or minutes <= 0:
                return 'NOT SET'
            return '%g MIN' % minutes
        except (TypeError, ValueError):
            return 'NOT SET'
    return dict(title=title, reference='MDR-' + reference,
                date='%02d %s %d' % (issued_at.day, 'JAN FEB MAR APR MAY JUN JUL AUG SEP OCT NOV DEC'.split()[issued_at.month - 1], issued_at.year),
                time=issued_at.strftime('%H:%M'),
                time_label='FOCUS ALLOCATION' if task.get('selection_method') else 'TIME ESTIMATE',
                duration=duration(task.get('estimated_time')),
                challenge=duration(task['challenge_time']) if task.get('challenge_time') else None,
                # Current local selection already explains the focus allowance.
                # Keep any older, task-specific guidance without repeating it.
                guidance=clean_text(task.get('motivation')) if not task.get('selection_method') else '')


@lru_cache(maxsize=12)
def font(size, bold=False):
    filename = 'DejaVuSansMono-Bold.ttf' if bold else 'DejaVuSansMono.ttf'
    return ImageFont.truetype(str(ASSETS / 'fonts' / filename), size)


def wrap_pixels(text, face, width, stroke=0):
    """Wrap words, including unbroken URLs, without losing title characters."""
    lines, line = [], ''
    for word in clean_text(text).split():
        candidate = (line + ' ' + word).strip()
        if face.getlength(candidate) + 2 * stroke <= width:
            line = candidate
            continue
        if line:
            lines.append(line)
            line = ''
        while face.getlength(word) + 2 * stroke > width:
            count = max(1, int(width / face.getlength('M')) - 1)
            while face.getlength(word[:count]) + 2 * stroke > width:
                count -= 1
            lines.append(word[:count])
            word = word[count:]
        line = word
    if line:
        lines.append(line)
    return lines or ['']


class Receipt:
    def __init__(self, width):
        self.width = width
        self.margin = 30
        self.inner = width - 2 * self.margin
        self.y = TOP_MARGIN_DOTS
        self.operations = []

    def text(self, text, size=18, align='left', bold=False, gap=0):
        face, stroke = font(size, bold), 0
        for line in wrap_pixels(text, face, self.inner, stroke):
            length = face.getlength(line)
            x = (self.width - length) / 2 if align == 'center' else self.margin
            self.operations.append(('text', (x, self.y), line, face, stroke))
            self.y += size + 9
        self.y += gap

    def pair(self, left, right, size=18):
        face = font(size)
        if face.getlength(left + '  ' + right) > self.inner:
            self.text(left, size)
            self.text(right, size)
            return
        self.operations.extend([('text', (self.margin, self.y), left, face, 0),
                                ('text', (self.width - self.margin - face.getlength(right), self.y), right, face, 0)])
        self.y += size + 10

    def rule(self):
        self.y += 10
        self.operations.append(('line', (self.margin, self.y, self.width - self.margin - 1, self.y)))
        self.y += 18

    def logo(self):
        with Image.open(ASSETS / 'lumon-print.png') as source:
            width = min(256, self.inner)
            height = round(source.height * width / source.width)
            logo = source.convert('L').resize((width, height), Image.Resampling.LANCZOS)
        self.operations.append(('image', ((self.width - width) // 2, self.y), logo))
        self.y += height + 14

    def checkboxes(self):
        for x, label in [(self.margin, 'COMPLETED'), (self.width / 2 + 22, 'DEFERRED')]:
            self.operations.append(('box', (x, self.y + 1, x + 19, self.y + 20)))
            self.operations.append(('text', (x + 31, self.y), label, font(18), 0))
        self.y += 32

    def image(self):
        image = Image.new('L', (self.width, self.y + BOTTOM_PADDING_DOTS), 255)
        draw = ImageDraw.Draw(image)
        for operation in self.operations:
            kind, position, *args = operation
            if kind == 'text':
                text, face, stroke = args
                draw.text(position, text, font=face, fill=0, anchor='lt', stroke_width=stroke)
            elif kind == 'line':
                draw.line(position, fill=0, width=2)
            elif kind == 'box':
                draw.rectangle(position, outline=0, width=2)
            else:
                image.paste(args[0], position)
        return image.convert('1', dither=Image.Dither.NONE)
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

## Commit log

2026-09-26 Add Lumon terminal software and enclosure design archive
    [01_DC_inlet_panel_DRAFT_NOT_RELEASED.3mf, 01_LED_insert_PETG.3mf, 01_LED_insert_PETG.gcode.3mf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]
2026-09-27 Print the Lumon logo above task tickets
2026-09-27 Format task tickets as Lumon work-assignment slips
    [logo.py, thermal_printer.py, ticket.py]
2026-09-29 Balance printed work-slip margins
    [ticket.py]
